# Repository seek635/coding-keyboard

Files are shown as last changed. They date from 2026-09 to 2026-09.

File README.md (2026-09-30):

# ClaudePad

> 蓝牙（BLE）编程专用实体小键盘 —— 为 Claude Code / 终端场景定制

一个 11 键 + 侧边审批拨杆的紧凑键盘，把 Claude Code 里最高频的操作从键盘组合键变成**单手一按**。

```
┌──────────┬────┬──────┬────────┬────────┐
│ 访问等级  │ ↑  │ 模型  │ 命令行  │  停止   │
├────┬────┬────┴────┴────────┤        │
│ ←  │ ↓  │ →    │   回车 2u   │        │
├────┴────┴──────┴────┬───────┴────────┤
│      空格 4u        │      语音       │
└─────────────────────┴────────────────┘
                                    ╱ 审批拨杆（OFF / ON）
```

**核心设计目标**：键盘本身不改变 Claude Code 的任何行为。拨杆 OFF 时它就是一个普通键盘；拨杆 ON 时才介入。

---

## 项目状态

| 模块 | 状态 | 说明 |
|---|---|---|
| 产品需求（PRD） | ✅ 完成 | `docs/PRD.md` |
| 结构设计（3D 打印） | ✅ 已渲染验证 | 6 个 STL 全部水密、尺寸零偏差 |
| 固件（ZMK） | ⚠️ 未编译 | 语法依据官方文档逐条核对，本地无 Zephyr 工具链 |
| 审批拨杆（宿主程序） | ✅ 协议层验证 | 31 个用例通过，未在真机 Claude Code 上跑通 |
| PCB | ⚠️ 未打样 | 封装坐标经两个独立开源库交叉验证 |
| 采购 | ✅ 清单完成 | `docs/采购清单.md` |

**未完成**：实机联调（画板 → 打样 → 焊接 → BLE 配对 → hooks 真机验证）。

---

## 硬件

| 部件 | 选型 | 备注 |
|---|---|---|
| 主控 | NoLogo ProMicro NRF52840 | 兼容 nice!nano，**装在 PCB 背面** |
| 轴体 | Kailh Choc **V2** 矮轴 35–40g | 编程敲击密度高，轻力度降疲劳 |
| 定位板 | 3D 打印，**厚 1.2mm** | Choc 标准值，不是 MX 的 1.5–1.6 |
| 审批拨杆 | SPDT 拨动开关 | 三脚，拨过去停住；轴套长度需 ≥ 9mm |
| 电池 | 3.7V 锂电 400–500mAh | 焊盘接线（非插座）；**厚 ≤ 4.0mm** |
| 反馈 | WS2812 | 可选 |

**整机尺寸**：107.10 × 71.10 × **23.30** mm（X 向 111.20 含右侧拨杆凸台）

### 垂直尺寸链

```
z = 23.30  ┌─────────────┐  键帽顶面
           │   键帽 5.0   │
z = 18.30  ├─────────────┤  键帽底面
           │  ★ 间隙 3.5  │  ← 必须 ≥ 键程 3.2，否则按不下去
z = 14.80  ├═════════════┤  定位板上表面
           │  定位板 1.2  │
z = 13.60  ├─────────────┤  定位板底面
           │  轴体卡扣 5.0 │  ← 只走轴体引脚，主控已改到板背面
z =  8.60  ├─────────────┤  PCB 上表面（轴体焊接面）
           │    PCB 1.6   │
z =  7.00  ├─────────────┤  PCB 下表面
           │ 主控/电池 5.0 │  ← 主控 3.2 + 余 1.8
z =  2.00  ├─────────────┤  底板上表面
           │    底板 2.0   │
z =  0.00  └─────────────┘  桌面
```

> ⚠️ **键帽间隙必须 ≥ 键程**。键帽裙边 17.6mm 比定位板轴孔 13.8mm 宽，塞不进孔里，
> 所以键帽只能悬在板上方，下压空间必须靠这个间隙提供。写成 0.3mm 会让键盘**完全按不下去**。

---

## 目录结构

```
cad/          参数化 3D 模型（OpenSCAD）+ 渲染产物
  lib/params.scad   ★ 所有尺寸的唯一来源
  plate.scad        定位板
  case_bottom.scad  底座（腔体/走线/散热/固定）
  keycap.scad       键帽（1u / 2u / 4u）
  test_coupon.scad  校准试件（打印前必打）
  output/*.stl      已渲染验证的 6 个 STL
  output/viewer.html 可交互三维查看器（three.js）

firmware/     ZMK shield 固件配置
  config/boards/shields/claudepad/*.keymap   ★ 键位与手势

host/         宿主程序（审批拨杆实现）
  claudepad_daemon.py   ★ 常驻：HTTP hook 应答 + 键盘监听
  claudepad_core.py     决策核心
  install_hook.py       一键安装到 Claude Code

pcb/          PCB 网表与接线图（json / md / svg / png）
tools/        校验与生成脚本（14 个）
docs/         设计文档
```

---

## 快速开始

### 看三维模型（零依赖）

```bash
python tools/view_model.py          # 起本地服务 + 开浏览器
```

或直接看 `cad/output/preview/*.png`。

### 校验设计（只需 Python）

```bash
python tools/check_env.py           # 先跑这个，看缺什么
python tools/check_dims.py          # 23 项结构设计规则
python tools/verify_geometry.py     # 孔位 / 对称 / 键帽对位
python tools/check_keymap.py        # 固件 ↔ 结构 交叉校验
```

**只有导出 STL 才需要 OpenSCAD**（`python tools/export_stl.py`）。
校验逻辑全部纯 Python 实现，这是刻意设计——OpenSCAD 是整条链里最难装的东西。

### 打印顺序

**别一次打全套。**

| 顺序 | 文件 | 验证什么 | 耗时 |
|---|---|---|---|
| ① | `00_test_coupon.stl` | **轴体卡扣间隙**（唯一需实测的参数） | 15 min |
| ② | `02_plate.stl` | 轴孔松紧 | 40 min |
| ③ | `05_keycap_4u.stl` | 三轴支撑手感 | 35 min |
| ④ | `01_case_bottom.stl` | 孔位与装配 | 3–4 h |

### 审批拨杆（宿主程序）

```bash
python host/install_hook.py         # 安装到 Claude Code（自动备份 + 幂等）
python host/claudepad_daemon.py     # 启动常驻进程
python host/switchctl.py on|off     # 手动切换状态（没有硬件也能测）
python host/test_hook.py            # 31 个用例
```

---

## 三个关键设计决策

### 1. 键盘是无状态的

键盘收不到权限档位、模型名、审批状态。所以「长按复位到 default」「长按循环切换模型」
**键盘做不了**——它不知道当前在哪一档。

方案：键盘只**发信号**（`Ctrl+Alt+Shift+F13`/`F14` 这种极难误触的组合），
由读取终端状态栏的上位机执行真正的操作。

### 2. 审批拨杆走 hooks，不走文本嗅探

| | 终端文本嗅探 | Hooks |
|---|---|---|
| 稳定性 | 匹配文案，**改文案就失效** | 官方接口，不依赖文案 |
| 能否分级 | 难结构化 | 直接拿到 `tool_name` + `tool_input` |
| 误判 | 天然会误判 | 结构化字段，无误判 |

官方机制里有一条是整个方案成立的关键：

> `PreToolUse` 返回 `{"hookSpecificOutput":{"permissionDecision":"allow"}}` → 跳过权限提示
> **返回空（exit 0 无输出）→ 不算批准** → 走原生权限流程

这使「拨杆 OFF = 产品不存在」成立——不改变用户任何既有行为。

**实测性能**：command 模式 510ms/次（每次起进程，不可接受）→ **HTTP 模式 15ms/次**（采用）。

**两条铁律**：
1. **失效安全** —— 任何故障（进程没跑 / 令牌错 / 脚本异常）都退化为「正常询问」，绝不误批
2. **只升不降** —— hook 只返回 `allow`，从不返回 `ask`/`deny`

### 3. 大键必须多轴支撑

4u 空格单轴支撑时 PLA 挠度 **1.59mm**（明显翘），三轴并联降到 **0.20mm**（降 87.5%）。
回车 2u 用 2 轴，空格 4u 用 3 轴。这不是可选项。

---

## 单一数据源

**所有尺寸只有一个来源：`cad/lib/params.scad`。** 任何地方要数字都必须解析它，不能手抄。

已落实：校验脚本、PCB 网表、行程图、**三维查看器**全部从它读取。

> **教训**：渲染出的 PNG 是快照（改参数就过期），手写 HTML 是副本（改参数就骗人）。
> 展示层也必须生成——否则它比没有更糟，因为它会**自信地展示错误信息**。

改完 `params.scad` 后：

```bash
python tools/check_dims.py && python tools/lint_scad.py && \
python tools/verify_geometry.py && python tools/export_stl.py && \
python tools/gen_viewer.py && python tools/draw_travel.py
```

---

## 已知限制

- **固件未编译**：本地无 Zephyr 工具链。语法依据 ZMK 官方文档（shield 结构 / hold-tap /
  tap-dance / macros）逐条核对，并做了静态一致性校验，但首次构建可能需微调。
- **审批拨杆未在真机验证**：本机无 Claude Code CLI，验证在协议层完成（按官方文档构造
  输入输出 + 验证失效路径）。接入步骤见 `docs/审批拨杆技术验证.md`。
- **PCB 未打样**：封装坐标经交叉验证，但未生成实际 PCB 文件跑 DRC。
- **`SWITCH_PLATE_GAP` 待实测**：Choc 官方未公开定位板高度，社区实测 3.5–6.0mm 浮动。
  用 `00_test_coupon.stl` 实测后回填 `params.scad`。

---

## 文档

| 文档 | 内容 |
|---|---|
| `docs/PRD.md` | 产品需求、键位定义、手势表、HID 映射 |
| `docs/结构设计规格书.md` | 尺寸链、公差、装配顺序、走线 |
| `docs/固件设计说明.md` | ZMK 设计原理与取舍 |
| `docs/PCB设计规格书.md` | 封装坐标、布局、打样参数 |
| `docs/审批拨杆技术验证.md` | hooks 路线可行性报告 |
| `docs/采购清单.md` | BOM 与选型理由 |

---

## 许可

未定。

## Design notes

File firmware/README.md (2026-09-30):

# ClaudePad 固件（ZMK）

三行五列 11 键 + 侧边审批拨杆的 ZMK shield 配置。

**主控**：NoLogo ProMicro NRF52840（原 SuperMini，兼容 nice!nano，Pro Micro 引脚兼容）
**固件框架**：[ZMK](https://zmk.dev)（BLE 键盘事实标准）

---

## 目录结构

本目录就是一个**标准 zmk-config**（ZMK 最主流的仓库布局，不用模块机制）：

```
firmware/                                     ← 这个目录的根 = 仓库根
├── .github/workflows/build.yml               ← GitHub Actions：推上去自动编译出 .uf2
├── build.yaml                                ← 构建矩阵：板子 nice_nano_v2 + shield claudepad
├── config/                                   ← ZMK_CONFIG 指向这里
│   ├── west.yml                              ← ZMK 上游依赖（版本锁定，须与 workflow 一致）
│   └── boards/shields/claudepad/             ← ★ shield 必须在 config/boards/shields/ 下
│       ├── Kconfig.shield                    ← shield 标识
│       ├── Kconfig.defconfig                 ← 设备名等默认配置
│       ├── claudepad.overlay                 ← 矩阵 + 引脚 + 变换
│       ├── claudepad.keymap                  ← ★ 键位与手势（核心）
│       ├── claudepad.conf                    ← 配置建议
│       └── claudepad.zmk.yml                 ← 硬件元数据
```

> **⚠️ 两个曾经踩过的坑（已由 `tools/check_keymap.py` 自动拦截）**
>
> 1. **shield 必须在 `config/boards/shields/` 里**。ZMK 只从 `<ZMK_CONFIG>/boards/shields/`
>    查找 shield（依据 `app/keymap-module/modules/modules.cmake` 与 `app/Kconfig`）。
>    放错层级 → 构建报 `shield not found`，而且报错信息很绕。
> 2. **不要在这里放 `zephyr/module.yml`**。官方 CI 工作流会靠它判断「这是不是一个 ZMK 模块」，
>    一旦存在就改走模块分支（把 config 复制到临时目录、另传 `-DZMK_EXTRA_MODULES`），
>    shield 查找路径随之改变。本项目用标准布局，故不设该文件。

---

## 键位与手势总表

| 键位 | 单击 | 双击 | 长按 |
|---|---|---|---|
| **访问等级** | `Shift+Tab` 循环权限档位 | — | 复位到 default（发信号给上位机） |
| **↑ ↓ ← →** | 对应方向键 | — | 自动重复（系统原生） |
| **模型** | `/model` + Enter | — | 循环切换模型（发信号给上位机） |
| **命令行** | `/` | — | `@` 文件引用 |
| **停止** | `Esc` 中断生成 | `Ctrl+C` 强制取消 | `Ctrl+C` ×2 退出会话 |
| **回车** | `Enter` 发送 | `Shift+Enter` 换行 | — |
| **空格** | `Space` | — | `Tab` 自动补全 |
| **语音** | 按住 = `Space`（push-to-talk） | `/voice` 切换启用 | — |
| **审批拨杆** | 拨到 ON = 持续按下 `F13`；OFF = 释放 | — | — |

> 「发信号给上位机」= 发送 `Ctrl+Alt+Shift+F13` / `F14` 这类极难误触的组合键。
> 因为键盘**无法知道**当前权限档位或模型名，这两个操作必须由读取状态栏的上位机执行。
> 详见 `docs/固件设计说明.md`。

---

## 矩阵接线

电气上是 **3 行 × 6 列**，实际用到 12 个交点：

```
        列1    列2    列3    列4    列5    列6
       (D7)   (D8)   (D9)   (D10)  (D16)  (D14)
行1(D4) 访问    ↑     模型   命令行  停止   审批拨杆
行2(D5)  ←      ↓      →     回车     —      —
行3(D6) 空格    —      —      —     语音     —
```

**大键并联接法**（重要）：
- **回车 2u**：定位板开 2 个轴孔，两个轴体都接到 `(行2, 列4)`
- **空格 4u**：定位板开 3 个轴孔，三个轴体都接到 `(行3, 列1)`

即大键的多个轴体**电气上并联**，任一轴触发即响应。PCB 设计时要把这些焊盘接到同一条线。

> ✅ **引脚分配已定稿并与 PCB 交叉校验通过**（2026-10-01）。板上走线就是这套分配，
> PCB 已于 2026-09-28 下单。`tools/check_keymap.py` 会拿 `claudepad.overlay` 与
> `pcb/netlist.json` 逐项比对，改任一边不一致就会报错。
> 若确需调整，改 `claudepad.overlay` 里的 `row-gpios` / `col-gpios` 即可，键位不用动。

---

## 怎么编译

### 方式一：GitHub Actions（推荐，零环境）✅ 已跑通

**已实测成功**：2026-10-01 首次构建通过，产出 138 KB 的 `.uf2`。

**为什么需要一个「根目录等于 firmware/」的分支或仓库**：官方 CI 用 repo 根目录
定位 `build.yaml` 和 `config/`。本项目是 monorepo，`firmware/` 在子目录里，
套一层就会全部错位。

**当前的做法：`zmk-firmware` 分支**（用 git subtree 把 `firmware/` 的内容摊到根）：

```bash
# 更新固件后，重新生成并推送这个分支，CI 就会重新构建
git subtree split --prefix=firmware -b zmk-firmware
git push origin zmk-firmware --force
```

> 因为 subtree 会重写这段历史，所以推送要带 `--force`。这个分支**只用来构建**，
> 不要在它上面开发 —— 所有改动都改 `main` 的 `firmware/`，然后重新 split。
> 推 `main` 不会触发构建（根目录没有 `.github/workflows/`），只有推 `zmk-firmware` 会。

**拿固件**：Actions → `Build ZMK firmware` → 最新一次运行 → **Artifacts** →
`firmware` → 解压得到 `claudepad-nice_nano_v2-zmk.uf2`。
也可在 Actions 页面点 **Run workflow** 手动触发。

**更干净的长远方案**：把 `firmware/` 的内容单独建一个仓库（如 `claudepad-zmk`），
仓库根就是现在这个目录，就不需要 subtree 那一步了。等固件稳定后可以迁过去。

工作流本身只有一行实质内容 —— 复用 ZMK 官方的可复用工作流：

```yaml
uses: zmkfirmware/zmk/.github/workflows/build-user-config.yml@v0.3.0
```

> ⚠️ 这个 `@v0.3.0` 必须与 `config/west.yml` 里的 zmk `revision` 一致，
> 否则构建脚本和 ZMK 版本对不上。`tools/check_keymap.py` 会检查这一条。

### 方式二：本地构建

需要 Zephyr SDK + west（Windows 上配置繁琐，**一般直接用方式一**）。

```bash
cd firmware                      # 本目录

# 1. 初始化 workspace（本目录即 workspace 根）
west init -l config
west update

# 2. 构建
west build -p -b nice_nano_v2 -s zmk/app -- \
    -DSHIELD=claudepad \
    -DZMK_CONFIG="$(pwd)/config"

# 3. 产物
#   build/zephyr/zmk.uf2
```

本地构建**不需要** `ZMK_EXTRA_MODULES` —— shield 就在 `config/boards/shields/` 下，
ZMK 会自动把 `ZMK_CONFIG` 加进 board root。

---

## 怎么刷固件

1. 主控插 USB（**必须是数据线**）
2. **进 bootloader** → 出现名为 `NICENANO` 的 U 盘
   - ⚠️ NoLogo ProMicro **没有复位按钮**，要**在 0.5 秒内短接 2 次 RST 到 GND**
   - 外壳底板预留了 φ8mm 孔，装一个外接轻触开关接在 RST–GND 之间（见 `docs/新手采购清单.md` 第 14 项）
3. 把 `claudepad.uf2` 拖进去
4. 板子自动重启，蓝牙广播名为 `ClaudePad`

之后改键位只需重新编译刷入，无需重新配对。

---

## 怎么改键位

**只改 `claudepad.keymap` 一个文件。**

改完**务必**跑一致性校验：

```bash
python tools/check_keymap.py
```

它会验证：
- 键位数量与 CAD 布局（`cad/lib/params.scad`）是否一致
- 每个键的顺序和功能是否与 PRD 相符
- 自定义行为的参数个数是否匹配

**改键位时注意**：`bindings` 的顺序必须与 `claudepad.overlay` 里 `default_transform` 的 `map` 顺序严格一致（都是从左到右、从上到下）。

---

## 常用调参

手感类参数都在 `claudepad.keymap` 的行为定义里：

| 想调什么 | 改哪个属性 | 当前值 |
|---|---|---|
| 空格误触 Tab | `spc_tab` 的 `tapping-term-ms` | 300（调大更不易误触） |
| 停止键误退会话 | `stop` 的 `tapping-term-ms` | 1200（调大更安全） |
| 双击判定窗口 | 各 tap-dance 的 `tapping-term-ms` | 200~250 |
| 快速连按不判长按 | `quick-tap-ms` | 150~200 |
| 打字时禁用长按 | `require-prior-idle-ms` | 120 |

---

## 已知限制

| 限制 | 说明 |
|---|---|
| **已编译通过，但未上机** | ✅ 2026-10-01 GitHub Actions 首次构建成功（ZMK v0.3.0，产出 138 KB `.uf2`）。⚠️ 但**从未烧进真机**——BLE 配对、按键手感、长按/双击的判定窗口都要等板子到货后才能验证。 |
| **状态指示未实现** | PRD 第 8 章要求「按键 RGB 显示当前权限档位」，这需要自定义固件 + 上位机通过 GATT 回写状态。当前固件只做键位。 |
| **审批拨杆只上报状态** | 拨杆作为矩阵里的一个键（F13），上位机需自行监听。真正的自动审批逻辑在上位机侧。 |
| **引脚分配已定稿** | ✅ 2026-10-01 交叉校验通过：`claudepad.overlay` 的 行 D4/D5/D6、列 D7/D8/D9/D10/D16/D14 与**已下单的** PCB 网表（`pcb/netlist.json`）逐项一致，二极管方向同为 `col2row`。此校验已固化进 `tools/check_keymap.py`。 |

详见 `docs/固件设计说明.md` 的「后续工作」。

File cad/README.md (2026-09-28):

# ClaudePad CAD 模型

3D 打印用的参数化结构模型。**改尺寸只需改一个文件**：`lib/params.scad`

整机 **107.10 × 71.10 × 23.30 mm**

---

## 依赖：大部分脚本不需要 OpenSCAD

这是刻意设计的。OpenSCAD 是整套工具链里最难装的东西（200MB、官方站和 GitHub 都常被拦），
所以**校验逻辑全部用纯 Python 实现**，不依赖它。

| 脚本 | 依赖 | 作用 |
|---|---|---|
| `view_model.py` | 纯 Python | **在浏览器里看三维模型** |
| `lint_scad.py` | 纯 Python | SCAD 语法与符号检查 |
| `check_dims.py` | 纯 Python | 26 项结构设计规则 |
| `verify_geometry.py` | 纯 Python | 孔位/对位验证 |
| `check_keymap.py` | 纯 Python | 固件 ↔ 结构一致性 |
| `verify_stl.py` | 纯 Python | STL 校验（读文件，不需要 CAD 软件） |
| `gen_pcb.py` | 纯 Python | PCB 网表与接线图 |
| `gen_viewer.py` | 纯 Python | **把尺寸注入三维查看器**（防漂移） |
| `draw_travel.py` | 纯 Python | 按键行程剖面图 |
| **`export_stl.py`** | **★ OpenSCAD** | **把 .scad 渲染成可打印的 STL** |

**实际含义**：

- **只装 Python** → 你能**看模型**、改所有尺寸、验证设计是否自洽、检查固件对不对。
  **完全够用来迭代设计。**
- **装了 OpenSCAD** → 才能把模型变成可以送切片软件的 STL。

不确定自己缺什么？跑这个：

```bash
python tools/check_env.py
```

它会逐项告诉你什么已就绪、什么缺失、缺的那个影响哪些功能。

> **本机现状**：OpenSCAD 已装在 `~/openscad-portable/`，6 个 STL 也已生成。
> 所以你现在直接跑任何脚本都可以。

---

## 怎么看到三维模型

**一条命令**：

```bash
python tools/view_model.py
```

会自动起本地服务并打开浏览器，里面是可旋转、可缩放、可爆炸拆解的实时三维模型。

**不需要 OpenSCAD，不需要任何 CAD 软件**——查看器读的是已经渲染好的 STL，
用浏览器的 WebGL 显示。

其它看模型的方式（都不需要软件）：

| 方式 | 位置 |
|---|---|
| 交互式三维查看器 | `python tools/view_model.py` |
| 渲染好的图片 | `cad/output/preview/*.png` |
| 丢进任意 STL 查看器 | `cad/output/*.stl` |
| 丢进切片软件（Cura / PrusaSlicer） | `cad/output/*.stl` |

**什么时候才需要 OpenSCAD**：改了 `params.scad` 里的尺寸，想看到新模型时。
因为 `.scad` 是模型源码，需要 OpenSCAD 求值才能变成几何体。

---

## 目录结构

```
cad/
├── lib/
│   └── params.scad          ← 所有尺寸都在这里，改这个
├── test_coupon.scad         ← ★ 校准试件（先打这个！）
├── plate.scad               ← 定位板（轴板）
├── case_bottom.scad         ← 底座
├── keycap.scad              ← 键帽（1u / 2u / 4u）
├── assembly.scad            ← 总装预览 + 爆炸图
└── output/                  ← 导出的 STL 放这里

tools/
├── check_env.py             ← 环境自检（先跑这个）
├── view_model.py            ← ★ 在浏览器里看三维模型（不需要 CAD）
├── check_dims.py            ← 设计规则校验（26 项）
├── lint_scad.py             ← 语法与符号检查
├── verify_geometry.py       ← 孔位与对位验证
├── verify_stl.py            ← STL 校验（尺寸/水密性/体积）
├── scad_params.py           ← 参数解析器（上面脚本共用）
├── canvas.py                ← 2D 画布（SVG + PNG 双后端，画图脚本共用）
├── gen_pcb.py               ← 生成 PCB 网表与接线图
├── gen_viewer.py            ← 把尺寸注入三维查看器（防漂移）
├── draw_travel.py           ← 生成按键行程剖面图
├── install_openscad.py      ← 自动下载安装 OpenSCAD（多镜像+断点续传）
└── export_stl.py            ← 一键导出全部 STL（★ 唯一需要 OpenSCAD 的）

docs/
└── 结构设计规格书.md          ← 尺寸 / 公差 / 装配 / 走线的完整说明
```

---

## 四步走

### 第 1 步：核参数（不需要装任何东西）

```bash
python tools/check_dims.py       # 26 项设计规则
python tools/lint_scad.py        # 语法、符号、死代码
python tools/verify_geometry.py  # 孔位、对称性、键帽对位
```

这三个脚本**不依赖 OpenSCAD**，纯 Python，随时可跑。

它们**直接从 `params.scad` 读参数**，所以不存在"改了参数但校验还用旧值"的问题。

**最有价值的是 `check_dims.py`** —— 它会抓出这些真实会翻车的问题：

- 内腔高度和零件堆叠对不上（会导致轴体够不到 PCB）
- 螺丝柱撞穿轴孔
- 拨杆螺母没有咬合长度
- 轴芯太长捅穿键帽顶面
- 主控放正面会压到轴体（板面被 14 个轴体占满）
- 电池厚度超过可用空间
- 空格单轴支撑挠度超标

### 第 2 步：装 OpenSCAD

**方式一：自动安装（推荐）**

```bash
python tools/install_openscad.py
```

脚本会自动尝试多个 GitHub 加速镜像、支持断点续传，最后解压到 `~/openscad-portable/`。

**方式二：手动下载**

下载：https://openscad.org/downloads.html

装完确认能调到：

```bash
openscad --version
```

> **为什么需要专门的安装脚本**：`openscad.org` 官方站和 GitHub Release 的
> `objects.githubusercontent.com` 在部分网络环境会被拦，直连速度可能只有 20KB/s。
> 本脚本按顺序试 `ghproxy.net` / `gh-proxy.com` / `gitmirror` 等镜像，断流自动续传。
>
> Windows 上优先用 `openscad.com`（控制台版），它不会弹 GUI 窗口。

### 第 3 步：导出 STL

```bash
python tools/export_stl.py
```

| 文件 | 零件 | 材料 |
|---|---|---|
| `00_test_coupon.stl` | **校准试件** | PLA |
| `01_case_bottom.stl` | 底座 | PETG |
| `02_plate.stl` | 定位板 | PLA |
| `03_keycap_1u.stl` | 键帽（打 9 个） | PLA |
| `04_keycap_2u.stl` | 回车键帽 | PLA |
| `05_keycap_4u.stl` | 空格键帽 | PLA |

**导出后务必校验**：

```bash
python tools/verify_stl.py
```

它会检查每个 STL 的包围盒尺寸是否与设计一致、是否水密（无破面）、体积是否正常。
这一步能抓出 CSG 建模中的共面/非流形问题。

### 第 4 步：打印

**别一次打全套。** 按这个顺序：

| 顺序 | 打什么 | 验证 | 耗时 |
|---|---|---|---|
| ① | `00_test_coupon.stl` | **轴体卡扣间隙** | 15 min |
| ② | `02_plate.stl` | 轴孔松紧 | 40 min |
| ③ | `05_keycap_4u.stl` | 三轴支撑手感 | 35 min |
| ④ | `01_case_bottom.stl` | 孔位与装配 | 3–4 h |

---

## 预览图

渲染预览（OpenSCAD 已装好后可自己重跑）：

```bash
cd cad
OSC=~/openscad-portable/openscad-2021.01/openscad.com
"$OSC" -D 'VIEW="assembly"' --autocenter --viewall --imgsize=1000,700 \
       -o output/preview/assembly.png assembly.scad
```

`cad/output/preview/` 下已有：

| 文件 | 内容 |
|---|---|
| `assembly.png` | 整机总装（等轴测） |
| `explode.png` | **三层爆炸图**（底座 / 定位板 / 键帽） |
| `top_view.png` | 正俯视 —— 用于核对键位排布 |
| `case_iso.png` | 底座内部结构 |
| `side_90.png` | 右壁正视图（拨杆孔 + USB 开口） |
| `plate.png` | 定位板 |
| `keycap4u_bottom.png` | 4u 空格底面 —— 可见 3 个榫头柱与 3 条加强筋 |

---

## 校准试件怎么用（重要）

`SWITCH_PLATE_GAP`（PCB 到定位板的距离）是**整套模型里唯一无法从公开资料确定**的尺寸。Choc 官方没公开，社区实测在 3.5–6.0mm 之间浮动。

所以先打 `00_test_coupon.stl`，上面有 3 个测试位（间隙 3.50 / 4.25 / 5.00mm）：

1. 拿真实 Choc 轴体逐个插进去
2. 找那个「**卡扣清脆扣入 + 轴体底面刚好贴住基座**」的位置
3. 把 `params.scad` 里的 `SWITCH_PLATE_GAP` 改成该值
4. 重跑 `check_dims.py`、`gen_viewer.py` 和 `export_stl.py`

判读标准：

| 现象 | 结论 |
|---|---|
| 轴体底面与基座之间有缝 | 该位间隙**偏大** |
| 卡扣扣不上 / 扣上后底面顶住基座 | 该位间隙**偏小** |
| 完全贴合 + 卡扣清脆 | ✅ 就是它 |

三个都不合适 → 改 `test_coupon.scad` 里的 `GAPS` 数组，重打（15 分钟）。

---

## 在 OpenSCAD 里预览

```bash
openscad assembly.scad
```

`F5` 快速预览，`F6` 完全渲染。改文件里的 `VIEW` 变量：

| VIEW | 效果 |
|---|---|
| `"explode"` | 爆炸图（默认）—— 检查装配关系与干涉 |
| `"assembly"` | 合体图 |
| `"case"` | 只看底座 |
| `"plate"` | 只看定位板 |
| `"caps"` | 只看键帽 |

单独看键帽：

```bash
openscad keycap.scad
```

改文件里的 `keycap_mode` 为 `"1u"` / `"2u"` / `"4u"`。

---

## 最常改的参数

都在 `lib/params.scad`：

| 想做什么 | 改哪个 | 当前值 |
|---|---|---|
| **轴体卡扣位置**（最重要） | `SWITCH_PLATE_GAP` | `5.00` |
| 轴体装不进 / 太松 | `SWITCH_CUTOUT_TOL` | `0.10` |
| 键帽榫槽太紧 / 太松 | `CAP_CROSS_W` | `1.30` |
| 键距 | `PITCH` | `18.0` |
| 键盘更薄 | `PCB_STANDOFF_H` | `5.00` |
| 换拨杆开关 | `SW_*` 系列 | 见文件 |
| 换电池 | `BATT_*` + `PCB_STANDOFF_H` | 见文件 |

**改完必跑**：

```bash
python tools/check_dims.py && python tools/lint_scad.py && python tools/verify_geometry.py
```

---

## 设计要点

### 垂直尺寸是推导出来的，不是写死的

```
内腔净高 = PCB_STANDOFF_H + PCB_T + SWITCH_PLATE_GAP
         = 5.0 + 1.6 + 5.0
         = 11.6 mm
```

改任何一个零件，整机高度自动跟着变。这样就不会出现"定位板抬高 4mm 导致轴体够不到 PCB"这类致命错误。

### 一个必须知道的耦合

**PCB 下方那 5.0mm 要同时容下电池和主控** —— 两者平面错开到两侧（电池贴左壁、主控贴右壁），
但层高由**较厚的电池**决定：胶 0.6 + 电池 4.0 = 4.6mm。想改薄键盘先确认电池装得下。
`check_dims.py` 会校验这一点。

> 主控早先装在 PCB **正面**，那时这条耦合是「轴体卡扣间隙 = 主控净空」；
> 因为 14 个轴体占满板面，主控已改到背面，耦合随之转移。详见 `docs/PCB设计规格书.md` §14。

### 空格为什么要 3 个轴

按无加强筋的最坏情况估算：

| 支撑方式 | 中点挠度（3N 按压力） |
|---|---|
| 单轴 | 1.59 mm ← 明显翘 |
| 三轴并联 | 0.20 mm ← 可接受 |

降幅约 87%。所以定位板在空格位开 3 个轴孔，键帽内对应 3 个榫槽。

### 螺丝柱为什么只能在边距里

轴孔之间净距只有 `18 − 13.9 = 4.1mm`，放不下螺丝柱。所以螺丝柱放在网格外缘到定位板边缘的 6mm 边距里，`check_dims.py` 会校验它与轴孔有 ≥0.8mm 余量。

---

## 关于 STL 文件

本仓库**包含**已导出的 6 个 STL（`cad/output/*.stl`），这样**只装 Python 也能用**：
查看器、切片软件都能直接吃，不需要为了看一眼模型去装 OpenSCAD。

⚠️ **但要注意它们会过期**：`params.scad` 一改，仓库里的 STL 就是旧的快照。
所以：

- **只是想打印** → 直接用仓库里的，但先确认没改过参数（`git log` 看 `params.scad` 的改动时间）
- **改过参数** → 必须重新导出，别拿旧 STL 去打印

```bash
python tools/export_stl.py     # 需要 OpenSCAD
python tools/verify_stl.py     # 校验包围盒与水密性
```

> 之所以强调这点：展示层（预览图、查看器、STL）都必须是**生成物**而不是手抄的副本 ——
> 副本会「自信地展示错误信息」，比没有更糟。见根目录 `README.md` 的「单一数据源」。

---

## 完整设计依据

尺寸从哪来、公差为什么是这个数、装配顺序、走线怎么走 —— 全在 **`docs/结构设计规格书.md`**。

那里也有「常见问题与对策」，遇到装不进、太松、翘曲先查那里。

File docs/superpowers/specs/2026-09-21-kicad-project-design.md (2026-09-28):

# ClaudePad KiCad 工程生成器 — 设计

**日期**：2026-09-21
**状态**：待实现
**相关文档**：`docs/PCB设计规格书.md` · `docs/结构设计规格书.md` · `docs/采购清单.md`

---

## 1. 背景与目标

### 1.1 背景

PCB 打样卡在「没有板文件」：`pcb/` 目录只有 `netlist.json` / `netlist.md` / `placement.csv` / `wiring.svg`，
没有任何 `.kicad_pcb` / `.kicad_sch` / `.kicad_pro`，也没有 Gerber。

`docs/PCB设计规格书.md` §12 自己声明了这条边界：「本文件给的是**设计规格与坐标**，画板需要你在 KiCad 里落地」。

### 1.2 目标

产出一个**能在 KiCad 中打开、DRC 通过、封装放置正确**的板文件，坐标全部来自 `cad/lib/params.scad`
的派生数据，供用户手工布线后打样。

### 1.3 关键约束

- 封装几何**不能由本项目手抄**。手抄的封装即使错了，DRC 也查不出来，但板子会做废 ——
  必须从 KiCad 官方库加载真封装。
- 坐标**不能有第二份来源**。`params.scad` 是唯一数据源，`gen_pcb.py` 已经从它算出全部坐标，
  新生成器只能读它的产物，不能重算。

---

## 2. 非目标

明确不做：

- ❌ **不布线**。生成的是「封装已放好、网络已连（有飞线）」的板，走线由用户在 KiCad 里手工完成
- ❌ **不出 Gerber**。布线完成后才能出
- ❌ **不生成原理图**。只在 `.kicad_pcb` 内部直接给焊盘指定网络
- ❌ **不含 WS2812**。v1 不放灯珠，只保留 D15 焊盘备将来使用
- ❌ **不做实机验证**。物理验证（校准试件、洞洞板原型）不在本次范围

> **为什么不做原理图**：用户只布线，不靠原理图。省掉一套 S-expression 就少一份出错面。
> 代价是以后想改拓扑得直接在 PCB 里改。

---

## 3. 交付物

| 文件 | 状态 | 说明 |
|---|---|---|
| `pcb/kicad/claudepad.kicad_pcb` | 新增 | 板文件，用户在 KiCad 里打开它布线 |
| `pcb/kicad/claudepad.kicad_pro` | 新增 | 工程设置：2 层、板厚 1.6、DRC 规则 |
| `tools/gen_kicad.py` | 新增 | 生成器 |
| `tools/gen_pcb.py` | 修改 | 修二极管坐标（见 §7） |
| `pcb/placement.csv` | 重跑 | 二极管坐标更新 |
| `pcb/netlist.json` | 重跑 | 增加二极管坐标字段 |
| `pcb/netlist.md` | 重跑 | 二极管数量/位置说明更新 |
| `tools/check_env.py` | 修改 | 增加 KiCad 与 `pcbnew` 的检测 |

**不改动**：`firmware/` · `cad/` · `host/`。

---

## 4. 板上元件

坐标系：**PCB 左下角为原点**，单位 mm，Y 向上。板面 98.00 × 50.00。

### 4.1 正面：14 个轴体

**Kailh Choc V2（PG1353）**，原点 = 轴芯中心。**来源：凯华官方规格图。**

> ⚠️ **2026-09-21 修订**：此前本节依据两个开源封装库（daprice / siderakb）「交叉验证」，
> 但实物实测与该表不符 —— **两个库一起错了**（详见任务 #7）。

| 特征 | 孔径 | 数量 | 类型 |
|---|---|---|---|
| 金属电气脚 | **1.20** | **2** | 金属化（PTH）★ 官方图标注 `2-Ø1.20`，通电 |
| 不通电定位脚 | **1.50** | **1** | 非金属化（NPTH），轴体第 3 脚，不导通（官方图 `2*1.5`） |
| 轴芯中心孔 | **5.00** | 1 | 非金属化（NPTH，让位给中央 Ø4.80 塑料凸台） |
| LED 焊盘 | — | 1 | 官方图标注 `LED` |

**★ 三根引脚坐标（2026-09-26 按官方 datasheet 最终落定）**：电气脚 (−3.80, 4.93) 与
(−5.90, 0.00)，不通电定位脚 (5.15, −5.00)（Ø1.50）。依据：凯华官方 datasheet
CPG135301D01（2020-10-23 版）PCB Layout 矢量图像素标定。
⚠️ siderakb 社区封装三孔坐标是官方坐标的 x/y 互换错版，勿引用。

外形 15 × 15 × 5.3mm；底座外形 13.95 × 13.95mm。

14 个绝对坐标来自 `pcb/netlist.json` 的 `keys[].pcb_positions`：

| 行 | 轴体 x | y |
|---|---|---|
| 1 | 13, 31, 49, 67, 85 | 7 |
| 2 | 13, 31, 49, 67, 85 | 25 |
| 3 | 13, **40**, 67（空格）+ 85（语音） | 43 |

> 空格的中间轴在 x = 40，**不在 18mm 网格上** —— 放置时关掉网格吸附，照坐标放。

### 4.2 正面：12 只 1N4148（直插 DO-35）

用户已购**直插**二极管，不用贴片。

| 项 | 值 |
|---|---|
| 封装 | DO-35 玻璃封装，轴向引线 |
| 引脚跨距 | 7.62 mm（预计 KiCad 库名为 `Diode_THT:D_DO-35_SOD27_P7.62mm_Horizontal`，**Step 0 需确认**） |
| 数量 | **12** |
| 安装面 | **正面**（与轴体同侧） |

**为什么必须放正面**：PCB 下方那 5.0mm 已被电池（左，PCB x 0~28）和主控（右，PCB x 79.7~97.5）占用，
剩余 x 28~79.7 还要扣掉 x=40 / 76 两根 ⌀4 支撑台，按行间隙带估算只放得下约 9 只，**不够 12 只**。

**正面的空间**：轴体之间走廊宽 `18 − 13.5 = 4.5mm`，而 DO-35 本体直径仅约 1.9mm。
二极管**沿走廊方向躺放**（7.62mm 引脚跨距顺着走廊走，不横穿），可以放下。
纵向可用高度为 PCB 上表面到定位板下表面的 5.0mm，本体 1.9mm 占得下。

**12 个位置怎么分布**：11 个矩阵位置（9 个单键 + 回车 1 + 空格 1）各 1 只，
加上拨杆 1 只。具体坐标由生成器按 §7 的算法算出。

**方向**：`col2row` —— **阳极接列线、阴极接行线**，电流方向 列 → 行。
12 只必须**统一方向**，接反不会烧但矩阵读不出来。

### 4.3 背面：主控

**NoLogo ProMicro NRF52840**（原名 SuperMini，nice!nano / Pro Micro 引脚兼容）。

| 项 | 值 |
|---|---|
| 尺寸 | 17.78 × 33.00 mm，厚 3.20 mm |
| 安装面 | **PCB 背面（下表面）** |
| 朝向 | 镜像；元件面朝下；USB-C 朝**右壁** |
| 原点位置 | PCB 坐标 **(79.70, 8.50)**（左下角），右缘 97.48，距板缘 0.52 |
| 引脚 | 2.54mm 通孔，引脚朝上穿过 PCB 焊在正面 |

**为什么在背面**：板面被 14 个轴体占满，穷举后正面「零重叠位置数 = 0」。

**引脚分配**（必须与 `firmware/.../claudepad.overlay` 一致）：

| 信号 | 引脚 | 方向 |
|---|---|---|
| ROW1 / ROW2 / ROW3 | D4 / D5 / D6 | 输入（`ACTIVE_HIGH \| PULL_DOWN`） |
| COL1 … COL6 | D7 / D8 / D9 / D10 / D16 / D14 | 输出（`ACTIVE_HIGH`） |
| RGB 数据（留焊盘） | D15 | 输出 |

### 4.4 背面：其余焊盘

`docs/PCB设计规格书.md` §5 只给了这些焊盘的**语义位置**，没给坐标 —— 生成器需自行选位（见 §6.3）。

| 焊盘组 | 数量 | 语义 | 规格书的说法 |
|---|---|---|---|
| 电池 | 2（B+ / B−） | 电池引线焊到主控的 B+ / B− 焊盘 | 「左侧空区」 |
| 电源开关 | 2 | 串在电池正极与主控之间 | 「左侧」 |
| 复位按钮 | 2 | 并联到 RST（该主控无板载复位按钮） | 「主控旁」 |
| 拨杆引线 | 2 | 公共端 → ROW1，常开端 → COL6 | 「右侧缺口附近」 |
| D15（RGB 预留） | 1 | 备将来接 WS2812 | — |

### 4.5 网络清单

| 网络 | 连接 |
|---|---|
| `ROW1` | 主控 D4、PERM、UP、MODEL、CMD、STOP 的二极管阴极、拨杆二极管阴极 |
| `ROW2` | 主控 D5、LEFT、DOWN、RIGHT、回车二极管阴极 |
| `ROW3` | 主控 D6、空格二极管阴极、语音二极管阴极 |
| `COL1` | 主控 D7、PERM 二极管阳极、LEFT、空格（3 轴并联） |
| `COL2` | 主控 D8、UP、DOWN |
| `COL3` | 主控 D9、MODEL、RIGHT |
| `COL4` | 主控 D10、CMD、回车（2 轴并联） |
| `COL5` | 主控 D16、STOP、语音 |
| `COL6` | 主控 D14、拨杆二极管的**阳极** |
| `APPROVE_MID` | 拨杆二极管的**阴极** ↔ 拨杆开关**常开端 NO** |
| `VBAT` | 电池 B+ → 电源开关 → 主控 B+ |
| `GND` | 电池 B−、主控 B−、复位按钮一端、拨杆公共端 |
| `RST` | 主控 RST、复位按钮另一端 |
| `RGB_DIN` | 主控 D15、D15 预留焊盘 |

**拨杆的串联路径**（与矩阵按键同构，方向一致）：

```
COL6 ──▶ 二极管阳极 ──▶ 二极管阴极 ──▶ 拨杆 NO ──[拨杆]── COM ──▶ ROW1
              （APPROVE_MID 是二极管与开关之间的中间网络）
```

**大键并联**：回车 2 个轴体电气并联到同一交点（ROW2 × COL4）；
空格 3 个轴体并联到（ROW3 × COL1）。PCB 上把它们的焊盘用铜箔连到同一条线。

---

## 5. 板框与缺口

### 5.1 板框

矩形 **98.00 × 50.00**，四角**不做安装孔** —— PCB 由 14 个轴体「挂」着（轴体卡在定位板上，
定位板用 4 颗 M2 螺丝锁在底座上）。

### 5.2 右侧缺口

| 项 | 值 | 状态 |
|---|---|---|
| 深度 | 8.00 mm | ✅ 已定 |
| 长度 | 24.00 mm | ✅ 已定 |
| **纵向位置** | **未知** | ❌ **必须在生成前解决** |

**缺口的用途**：SPDT 拨杆的**本体在壳内**（拨杆 + 轴套 + 螺母在壳外），本体沿轴套方向侵入约 8.5mm。
不给它让位，本体就会压到 PCB 上。

**为什么位置是未知项**：`cad/case_bottom.scad` 第 28 行有 `SW_Y = 16.0`（拨杆中心纵向位置），
但它处于**外壳坐标系**，而缺口要落在 **PCB 坐标系**里。两套坐标的换算关系没有在文档里对齐过，
按 `case_bottom.scad` 第 34–35 行的换算约定（`case = CASE_WALL + PCB偏移 + pcb`）推出来的缺口区间
会超出板边（y 为负），说明 `SW_Y` 可能没跟着历次改动更新。

**更严重的是**：`tools/check_dims.py` 只校验了缺口的**深度**（`PCB_NOTCH_D >= 4.0`），
**从未校验过缺口的纵向位置**。也就是说缺口开错位置，26 项校验照样全绿 —— 这是同一类
「校验过了但不代表对」的陷阱。

**解决要求**：生成前必须确定缺口的纵向区间，并把它固化成可校验的值（进 `params.scad` 或 `check_dims.py`）。
缺口位置错 → 拨杆本体压板 → 板子报废。

---

## 6. 生成器设计

### 6.1 技术路线

用 **KiCad 自带的 Python + `pcbnew` API** 生成。

```
KiCad/bin/python.exe tools/gen_kicad.py
```

选这条路线的**唯一理由是封装正确性**：`pcbnew.FootprintLoad()` 从 KiCad 官方库加载真封装，
封装几何不由本项目手抄。备选方案（纯 Python 手写 `.kicad_pcb` 文本）虽然不依赖 KiCad 的 Python，
但必须内嵌手抄的封装定义 —— 抄错 1mm，DRC 全绿而板子做废，正是本项目 README 警告的
「自信地展示错误信息」。

### 6.2 输入

只读 **`pcb/netlist.json`** —— 由 `tools/gen_pcb.py` 从 `cad/lib/params.scad` 生成。

现有字段已经足够：

| 字段 | 内容 |
|---|---|
| `keys[]` | 12 个键：`label` / `row` / `col` / `net_row` / `net_col` / `pin_row` / `pin_col` / `switches` / `pcb_positions` |
| `rows[]` / `cols[]` | 网络名到引脚的映射 |
| `pinout` | 行/列/拨杆/RGB 引脚 |
| `diode_direction` | `col2row` |
| `switch_footprint` | Choc V2 焊盘坐标与孔径 |
| `pcb` | 宽 / 高 / 厚 / 原点偏移 / 缺口深度与长度 |

**生成器不得重新计算轴体坐标**。坐标算错一次就有两份不一致的来源。

### 6.3 需要生成器自行选位的部分

`netlist.json` 里**没有**这些焊盘的坐标，生成器必须按语义选定并写死为常量（附注释说明依据）：

- 电池 B+ / B− 焊盘
- 电源开关 2 个焊盘
- 复位按钮 2 个焊盘
- 拨杆引线 2 个焊盘

选位时必须满足：

1. 不与任何轴体本体（13.5mm 见方）重叠
2. 不与 4 个 ⌀4 支撑台（PCB 坐标 (40,16) (76,16) (40,34) (76,34)）重叠
3. 落在板框内
4. 不侵入右侧 8×24 缺口

---

## 7. 二极管坐标重算（修现有 bug）

### 7.1 问题

`pcb/placement.csv` 当前给出的二极管「建议位」**落在板外**：

```
D1,diode,ROW1xCOL1,13.00,-1.00,PERM；阳极→COL1，阴极→ROW1
```

它是按「轴体正上方 8mm」算的，而轴体在 y = 7，减 8 得 **y = −1**，板是 y 0~50。

### 7.2 修法

把二极管坐标的计算**移进 `tools/gen_pcb.py`**（它已经在算轴体坐标），算法：

1. 对每个需要二极管的矩阵位置，找一个**离对应轴体最近、且合法**的走廊位置
2. 合法性 = 不与轴体本体、支撑台、缺口、板缘重叠
3. 二极管方向统一为 `col2row`

产出写进 `netlist.json` 的新字段（如 `keys[].diode_pcb_pos`），供：

- `gen_pcb.py` 写 `placement.csv` 与 `netlist.md`
- `gen_kicad.py` 放 KiCad 封装

**这样三处共用同一份坐标**，不会各算各的。

---

## 8. 验证方案

| # | 手段 | 查什么 |
|---|---|---|
| 1 | `kicad-cli pcb drc` | 必须 **0 错误** |
| 2 | `kicad-cli pcb export gerbers` | 能导出 = 文件可被 KiCad 解析 |
| 3 | `gen_kicad.py` 自带纯 Python 自检 | ① 轴体/二极管坐标与 `netlist.json` 逐条一致 ② 二极管与轴体本体、支撑台不重叠 ③ 焊缝网络与 `netlist.md` 逐条一致 ④ 板框 98×50 |
| 4 | 人工 | 在 KiCad 里打开，核对板框、缺口位置、轴体是否落在定位板孔位上 |

**自检必须是纯 Python**（不依赖 KiCad），延续本项目「校验逻辑全部纯 Python 实现」的设计 ——
OpenSCAD 与 KiCad 都只用于产出，不用于校验。

---

## 9. 执行顺序

### Step 0：侦察 ✅ **已完成（2026-09-26，KiCad 10.0.6 @ D:\kicad）**

1. ✅ `pcbnew` 在 KiCad 自带 Python（`D:\kicad\bin\python.exe`）可 import，版本 10.0.6
2. ✅ **官方库没有 Choc 封装**（Button_Switch_Keyboard.pretty 只有 MX 系列）
   → 决定：自建封装，孔位直接采用 §4.1 已确认坐标（电气 (−3.8,4.93)/(−5.9,0) Ø1.20 PTH，
   定位 (5.15,−5) Ø1.50 NPTH，中心 Ø5.00 NPTH）——按凯华官方 datasheet 像素标定
3. ✅ 主控封装：`Connector_PinHeader_2.54mm:PinHeader_1x12_P2.54mm_Vertical`（直焊两排 1×12）
4. ✅ 二极管封装：`Diode_THT:D_DO-35_SOD27_P7.62mm_Horizontal`（与预期库名完全一致）

### Step 1..n

1. ✅ 缺口纵向位置已固化（params.scad `PCB_NOTCH_Y0/Y1` = [0,12] + check_dims.py 校验）
2. ✅ 二极管坐标已进 `gen_pcb.py`（DIODE_POS，DRC 校正后 v2），`netlist.json` 新字段 `diode_pcb_pos`
3. ✅ `placement.csv` 已同步（含轴体旋转角）
4. ✅ `gen_kicad.py` 已写完（2026-09-26）
5. ✅ 板文件已生成 `pcb/claudepad.kicad_pcb`：生成器自检通过 + DRC 0 违规（58 unconnected 为布线前预期）+ Gerber 全层导出成功
6. ✅ 用户 KiCad 核对通过（2026-09-27）；**布线完成**：FreeRouting v2.4.1 自动布线
   （DSN 导出 → CLI `-de/-do` → 58 项全布通）→ `tools/import_ses.py` 导回
   （KiCad 10 的 ImportSpecctraSES 对 FR v2.4.1 输出返回 False，自写导入器：
   坐标变换 x_k=x_ses×0.1μm / y_k=−y_ses，179 段走线 + 2 过孔）
   → **DRC 最终结果：0 违规、0 未连接** ✓ 待打样

**生成过程沉淀的关键决策**（详见 `tools/gen_kicad.py` 头注释）：
- 主控 y[8.5,41.5]→y[12.5,45.5]（右排孔避让缺口 + 左排孔避让 STOP 焊盘；外壳 USB 开孔 y 联动）
- 缺口纵向 [0,12]（拨杆本体 [2.4,8.8] + 主控右排孔下缘 13.53 双约束）
- 轴体旋转：STOP 0°、ENTER 第2轴 180°、VOICE 180°（电气焊盘避让主控排针）
- NPTH 定位孔省略 2 个（ENTER 第2轴、STOP——落主控区/缺口，定位脚悬空，机械靠卡扣）
- 二极管 12 只分布两条走廊（间距 ≥10.32、避支撑台禁带与主控左排孔带）

---

## 10. 风险与未知项

| # | 风险 | 影响 | 应对 |
|---|---|---|---|
| 1 | ~~三根引脚坐标未知~~ **已解除（2026-09-26）** | — | 坐标已落定：(−3.8,4.93)/(−5.9,0) 电气、(5.15,−5) 定位；官方 datasheet 像素标定 + 万用表导通对确认 |
| 2 | KiCad 库里没有 Choc V2 封装，或库里的与官方图不符 | 现成封装的引脚坐标 / 中心孔可能对不上 → **轴插不进** | Step 0 侦察；对不上就按官方图自建封装 |
| 3 | 缺口纵向位置错 | 拨杆本体压板，**整板报废** | §5.2 必须在生成前解决，并加进自动校验 |
| 4 | 定位板开孔 13.80 vs 底座外形 13.95 | 轴体装不进定位板 | 待实物复量；若需改则定位板要重打 |
| 5 | 二极管选位算法产出的位置不合法 | 装不进 | 自检项 ②③ 拦掉 |
| 6 | `pcbnew` API 版本差异 | 脚本跑不起来 | Step 0 侦察；以实际安装版本的 API 为准 |
| 7 | 主控在背面需镜像 | 引脚左右颠倒，固件对不上 | 生成后用自检核对每个引脚的网络与 `netlist.md` 一致 |

---

## 11. 本设计的边界

**包含**：生成器设计、板上元件与网表、板框与缺口、二极管坐标重算、验证方案、执行顺序。

**不包含**：

- ❌ 布线（用户在 KiCad 里完成）
- ❌ Gerber 导出与打样参数（布线后的事）
- ❌ 原理图
- ❌ 实机（校准试件 / 洞洞板原型 / 焊接）

**前置假设**：

- 用户已购**直插** 1N4148（不用贴片）
- 用户会安装 KiCad
- 布局不再变动（若物理验证后要改布局，本产物需重新生成）

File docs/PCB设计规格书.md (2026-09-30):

# ClaudePad PCB 设计规格书

**版本**：v0.2
**日期**：2026-09-20
**板子尺寸**：98.00 × 50.00 × 1.60 mm（2026-09-16 从 86 加宽，解决 USB 口够不到右壁）
**配套文件**：`pcb/netlist.json` · `pcb/netlist.md` · `pcb/wiring.svg` · `cad/lib/params.scad`

> 本文件里的所有坐标均由 `tools/gen_pcb.py` 从 `cad/lib/params.scad` 生成，与外壳/定位板/固件严格对齐。
>
> **v0.2 同步**：附录速查此前停留在 86mm 板宽 / Choc V1 的旧值，已对齐到 **98×50 / Choc V2 /
> 支撑台 40·76 / 主控 (79.70, 8.50)**；主控名称统一为 **NoLogo ProMicro NRF52840**。
> §14 保留为改动过程的历史记录，其中的 86×50 与「x=68」是当时的值。

---

## 0. 快速导航

| 你想做的事 | 看哪节 |
|---|---|
| 手焊洞洞板 | §3 接线 + `pcb/wiring.svg` |
| 画 PCB | §4 封装坐标 + §5 元件布局 |
| **拿开源设计改板** | **`docs/PCB改板方案.md`** |
| 打样下单 | §8 制造参数 |
| 检查设计对不对 | §11 验证清单 |

---

## 1. 这块板子要做什么

把 11 个轴体 + 1 个审批拨杆 + 1 个主控 + 1 个电池座连起来，装进外壳。

**设计约束（全部来自已确定的结构与固件）**：

| 约束 | 来源 | 值 |
|---|---|---|
| 板子外形 | `params.scad` 的 `PCB_W` / `PCB_H` | 98 × 50 mm |
| 板厚 | `PCB_T` | 1.6 mm |
| 矩阵 | 固件 `claudepad.overlay` | 3 行 × 6 列 |
| 引脚 | 同上 | 行 D4/D5/D6，列 D7/D8/D9/D10/D16/D14 |
| 右侧缺口 | 拨杆本体在壳内的位置 | 深 8 × 长 24 mm |
| 轴体位置 | 定位板轴孔（`params.scad`） | 见 §4 |

---

## 2. 板子外形

```
        ┌──────────────────────────────────────────────┐
        │                                              │
        │             98.00 × 50.00                    │
        │                                              │┌──┐
        │              主矩阵区                         ││缺│
        │                                              ││口│ 8×24
        │                                              │└──┘
        └──────────────────────────────────────────────┘
```

**右侧缺口**：深 8mm、纵向 24mm，位置对准拨杆。
原因：SPDT 拨杆的**本体在壳内**（拨杆+轴套+螺母在壳外），本体沿轴套方向侵入约 8.5mm。
不给它让位，本体就会压到 PCB 上。

**四角不要放安装孔**：PCB 不靠螺丝固定——它由 14 个轴体「挂」着（轴体卡在定位板上，定位板用 4 颗 M2 螺丝锁在底座上）。
这是键盘的常规做法，PCB 无需额外固定。

---

## 3. 矩阵接线

完整接线图见 **`pcb/wiring.svg`**（可打印放大），焊接对照表见 **`pcb/netlist.md`**。

### 3.1 二极管方向（关键）

```
固件配置：diode-direction = "col2row"
含义：    二极管阳极接列线，阴极接行线
电流方向：列 → 行
```

每个按键回路：

```
列线 ──▶ 二极管阳极 ──▶ 二极管阴极 ──▶ 轴体 ──▶ 行线
```

**为什么是这个方向**：`col2row` 时列是**输出驱动**（`GPIO_ACTIVE_HIGH`），行是**输入读取**（`GPIO_ACTIVE_HIGH | GPIO_PULL_DOWN`）。二极管必须允许电流从被驱动的列流向被读取的行。

> ⚠️ **接反不会烧，但矩阵完全读不出来。**
> 修正二选一：把所有二极管掉头，或把固件里的 `diode-direction` 改成 `"row2col"`。
> 后者更省事，但以后别人看板子会困惑——建议前者。

### 3.2 引脚分配

| 信号 | 引脚 | 方向 |
|---|---|---|
| ROW1 / ROW2 / ROW3 | D4 / D5 / D6 | 输入（PULL_DOWN） |
| COL1 … COL6 | D7 / D8 / D9 / D10 / D16 / D14 | 输出 |
| RGB 数据 | D15 | 输出 |

> 这套分配必须与 `firmware/config/boards/shields/claudepad/claudepad.overlay` 一致。
> `tools/check_keymap.py` 现在会**自动交叉校验**行/列引脚与二极管方向（2026-10-01 补上），
> 与 `pcb/netlist.json` 不一致会直接报错 —— 不再依赖人工确认。

### 3.3 大键并联（重要）

回车和空格在定位板上分别开了 2 个和 3 个轴孔（解决长键翘曲）。这些轴体在**电气上并联**：

| 大键 | 轴体数 | 都接到 |
|---|---|---|
| **回车**（2u） | 2 | ROW2 × COL4 |
| **空格**（4u） | 3 | ROW3 × COL1 |

**PCB 上要把这几个轴体的焊盘用铜箔连到同一条行/列线上**，否则会变成多个独立按键。
手焊洞洞板时，就是用一根导线把它们的引脚串起来。

### 3.4 审批拨杆

| 项 | 值 |
|---|---|
| 位置 | 右壁（不在轴体网格里） |
| 接线 | 公共端 → ROW1；常开端 → COL6（D14） |
| 二极管 | **建议串一只 1N4148** —— 拨杆是开关不是轴体，不串可能在多键同按时产生鬼影 |

拨杆是**两态**器件：拨到 ON 时持续接通 ROW1–COL6，固件读到的就是一个「一直按住的 F13」。

---

## 4. 轴体封装坐标

**Kailh Choc V2 (PG1353)**，原点 = 轴芯中心。

> **来源：凯华官方规格图**（PCB 板安装示意图）。
> ⚠️ 2026-09-21 修订：此前本节依据两个开源封装库（`daprice/keyswitches.pretty` 与
> `siderakb/key-switches.pretty`）「交叉验证」，但**实物实测与该表不符 —— 两个库一起错了**。

官方图确认的数据：

| 特征 | 孔径 mm | 数量 | 类型 |
|---|---|---|---|
| 金属电气脚 | **1.20** | **2** | 金属化（PTH）★ 官方图标注 `2-Ø1.20`，通电 |
| 不通电定位脚 | **1.50** | **1** | 非金属化（NPTH），轴体第 3 脚，不导通（官方图 `2*1.5`） |
| 轴芯中心孔 | **5.00** | 1 | 非金属化（NPTH）★ 让位给中央 Ø4.80 塑料凸台 |
| LED 焊盘 | — | 1 | 官方图标注 `LED` |

**★ 三根引脚坐标（2026-09-26 按官方 datasheet 最终落定）**：

| 引脚 | 坐标 (x, y) mm | 孔径 | 类型 |
|---|---|---|---|
| 电气脚 1 | (−3.80, 4.93) | Ø1.20 | PTH，通电 |
| 电气脚 2 | (−5.90, 0.00) | Ø1.20 | PTH，通电 |
| 定位脚 | (5.15, −5.00) | Ø1.50 | NPTH，不导通 |
| LED 焊盘 | (5.15, 0.00) | — | 焊盘 |

依据：凯华官方 datasheet（CPG135301D01，2020-10-23 版）Recommended PCB Layout，
600dpi 矢量图像素标定 + 双尺寸交叉验证（误差 0.1%）。
⚠️ **siderakb 等社区封装的三个孔坐标是官方坐标的 x/y 互换错版**（(−5.90,0)→(0,5.9)，
(−4.93,3.8)→(−5,3.8)，(5.15,−5)→(5,−5.15)），勿再引用；两两间距实测无法区分这组镜像。
**2026-09-26 用户已用万用表实测确认**：按下导通的一对即电气脚。
PCB 必须钻满 3 个孔，一个都不能省。

**外形**：官方图标注 **15 × 15 × 5.3mm**，底座外形 **13.95 × 13.95mm**。

> ⚠️ 定位板开孔当前是 **13.80**（`params.scad` 的 `SWITCH_CUTOUT`），而 **13.95 > 13.80**。
> 若底座需穿过定位板，此孔偏小 → 轴体装不进。**待实物复量后定。**

**每个轴体的绝对位置**（PCB 坐标系，原点 = PCB 左下角）：

| 按键 | 轴体坐标 (x, y) |
|---|---|
| 访问等级 PERM | (13, 7) |
| ↑ UP | (31, 7) |
| 模型 MODEL | (49, 7) |
| 命令行 CMD | (67, 7) |
| 停止 STOP | (85, 7) |
| ← LEFT | (13, 25) |
| ↓ DOWN | (31, 25) |
| → RIGHT | (49, 25) |
| 回车 ENTER | (67, 25) **和** (85, 25) |
| 空格 SPACE | (13, 43) **(40, 43)** **(67, 43)** |
| 语音 VOICE | (85, 43) |

> 空格三个轴在 x = 13 / 40 / 67，跨 54mm，配合 4u 键帽的 3 个榫槽。
>
> ⚠️ 这组坐标随 **PCB 加宽**整体 +6mm（原 7/25/43/61/79）。权威来源是
> `pcb/placement.csv`（由 `tools/gen_pcb.py` 生成），改 PCB 尺寸后重跑该脚本即可同步。

---

## 5. 元件布局

| 元件 | 位置 | 说明 |
|---|---|---|
| 14 个轴体 | 见 §4 | 主矩阵 |
| 14 只 1N4148 | 每个轴体旁 | 建议放在轴体与行线之间，占用小 |
| NoLogo ProMicro NRF52840 | **PCB 背面（下表面）右侧**，**直接焊在板上** | 见下 |
| 审批拨杆引线焊盘 | 右侧缺口附近 | 公共端→ROW1，常开端→COL6 |
| 电池引线焊盘（B+ / B−） | 左侧空区 | 电池在 PCB 正下方，走线穿过 |
| 电源开关焊盘 | 左侧 | 串在电池正极与主控之间 |
| 复位按钮焊盘 | 主控旁 | 并联到 RST |
| WS2812 | 沿轴体分布 | 数据线 D15 |

### 5.1 主控必须直焊，不能用排母

主控装在 **PCB 背面**，那一层（`PCB_STANDOFF_H`）只有 **5.0mm**，
而主控本体 3.2mm + 普通排母 2.54mm = **5.74mm，超了**。

所以主控必须**直接焊接在 PCB 上**（板对板），引脚朝上穿过 PCB 焊在正面。这是「薄」换来的代价。

主控位置：PCB 背面右侧，USB-C 口朝**右侧**，对准外壳右壁的 USB 开孔。

> 同一层还有电池（贴左壁）。两者平面错开、互不重叠，但一起受这 5.0mm 限制 —— 详见 `docs/结构设计规格书.md` §1.3。

### 5.2 PCB 支撑台位置（与外壳的配合）

外壳里有 4 个矮柱托住 PCB，位置在 **PCB 坐标 (40,16)、(76,16)、(40,34)、(76,34)**。

> ⚠️ 这些位置是**轴体之间的空隙中心**，不是四角。
> 轴体之间只有 `18 − 13.5 = 4.5mm` 空隙，四角正好是轴体塑料脚的位置，支撑台放那里会顶住装不进去。
> 支撑台直径 4.0mm < 4.5mm 空隙。
>
> 合法的空隙中心是 x ∈ {22, 40, 58, 76}、y ∈ {16, 34}。取 40 / 76 是因为
> x=22 被电池占、x=58 与主控（x=79.7 起）不对称。校验见 `check_dims.py` 第 19–22 项。

画 PCB 时**不需要**为它们开孔（支撑台在 PCB 下方，只是托着）。

---

## 6. 布线规格

| 项 | 建议值 | 理由 |
|---|---|---|
| 铜厚 | 1 oz（35µm） | 常规，够用 |
| 行/列信号线宽 | **0.25 mm** | 信号线电流极小 |
| 电源线宽（3.3V / VBAT） | **0.6 mm** | 主控峰值电流 + RGB |
| GND 线宽 | **0.6 mm** 或铺铜 | 回流路径 |
| 线间距 | ≥ 0.2 mm | 嘉立创常规工艺 |
| 过孔 | 0.3/0.6 mm | 常规 |
| 层数 | **2 层** | 足够，成本低 |

**布线要点**：

1. **行线/列线尽量走到底层**，顶层留给轴体焊盘和元件
2. **WS2812 的数据线串一颗 100–300Ω 电阻**（靠主控端），防振铃
3. **RGB 电源加 100µF 电解 + 0.1µF 陶瓷**去耦，否则灯珠闪烁
4. 天线区（主控的板载天线在 **PCB 背面**，其正下方的**底层投影区**）**不要铺铜、不要走线**，否则蓝牙距离骤降
5. 大键并联的几个轴体，用同一根粗一点的线（0.4mm）串起来

---

## 7. 与外壳/定位板的配合

| 接口 | 值 | 校验方式 |
|---|---|---|
| 板子外形 | 98 × 50 mm | `check_dims.py` 第 7 项 |
| 板厚 | 1.6 mm | 与 `PCB_T` 一致 |
| 轴体位置 | 与定位板轴孔同心 | `gen_pcb.py` 从 `params.scad` 取 |
| 右侧缺口 | 深 8 × 长 24 mm | `check_dims.py` 第 11 项 |
| PCB 上方净空 | 5.0 mm | 只走轴体引脚，决定了「主控不能放正面」 |
| PCB 下方净空 | 5.0 mm | 主控 + 电池；决定主控必须直焊（排母会超） |
| 支撑台避让 | 支撑台在空隙中心 | `check_dims.py` 第 19–22 项 |

**装配关系**：

```
        定位板（4 颗 M2 螺丝锁在底座上）
          │
          │ 轴体穿过定位板、焊在 PCB 上
          ▼
        PCB  ──── 由轴体「挂着」，同时被 4 个支撑台托住
          │
          │ 电池 + 走线在 PCB 下方
          ▼
        底座底板
```

---

## 8. 制造参数（嘉立创打样）

| 参数 | 值 |
|---|---|
| 层数 | 2 层 |
| 尺寸 | 98 × 50 mm |
| 板厚 | 1.6 mm |
| 铜厚 | 1 oz |
| 阻焊颜色 | 任意（建议哑黑，视觉干净） |
| 丝印 | 白 |
| 表面处理 | 有铅喷锡（最便宜）或沉金 |
| 最小线宽/间距 | 0.25 / 0.2 mm（常规工艺范围内） |
| 最小孔径 | 0.3 mm（本项目最小是 1.27，很宽裕） |

> 板子很小，嘉立创 5 片起打，成本极低。建议**多打几片**——首片焊坏了不用重等。

---

## 9. 打板前必做的三件事

1. **先打外壳和定位板，实测 `SWITCH_PLATE_GAP`**
   （用 `cad/test_coupon.scad` 校准件，15 分钟）
   这个值决定 PCB 上轴体焊盘与定位板的相对高度关系，虽然 PCB 本身不受影响，
   但**主控高度**受它约束——如果实测值 < 3.7mm，主控方案要改。

2. **确认拨杆实物尺寸**
   轴套直径/长度、面板尺寸、**本体侵入深度**。本体侵入 > 8.5mm 的话，缺口要加深。

3. **确认 NoLogo ProMicro 的封装尺寸**
   17.78 × 33.00mm 是标称值，实物可能有偏差。特别是 USB-C 口的位置——它要和外壳右壁的开孔对齐。

---

## 10. 手焊洞洞板（不用打 PCB 的路线）

如果想先验证电路再打板，按 `pcb/wiring.svg` 在洞洞板上焊：

**需要的洞洞板**：至少 98 × 50 mm（留余量）

**步骤**：

1. 先焊 14 只二极管，**统一方向**（阳极朝列）
2. 用裸铜线沿列走 6 条、沿行走 3 条，构成矩阵
3. 每个轴体位置焊两个排针座（或用飞线直接连轴体）
4. 大键的多个轴体，用一根线把它们的引脚串起来
5. 最后接主控、拨杆、电池座

> 洞洞板版本的轴体无法插进去固定，只能**用飞线把轴体引出来**，或者先不装轴体、用镊子短接焊盘测试固件。

---

## 11. 验证清单

打板前逐项确认：

```
□ 板子外形 98 × 50 mm
□ 右侧缺口 深 8 × 长 24 mm，位置对准拨杆
□ 14 个轴体位置与 §4 表格一致
□ 引脚共 **3 个孔**：电气 2 孔 **Ø1.20 PTH**（官方图 `2-Ø1.20`）+ 不通电定位 1 孔 **Ø1.50 NPTH** —— 一个都不能省
□ 中心孔 **Ø5.00** 非金属化
□ 二极管统一方向：阳极接列、阴极接行
□ 回车两个轴、空格三个轴各自并联到同一交点
□ 引脚分配与 claudepad.overlay 一致
□ 主控天线区无铺铜、无走线（天线在 PCB 背面）
□ 主控焊在 PCB **背面**，引脚朝上穿板焊在正面
□ 主控 USB 口位置与外壳右壁开孔对齐（开孔 z = PCB 下表面 −1.80 = 5.20）
□ PCB 四角无安装孔（不需要）
□ 支撑台位置不需开孔
```

---

## 12. 本规格书的边界

**包含**：板子外形、矩阵接线、封装坐标、元件布局、布线规格、与外壳的配合。

**不包含**：
- ❌ **具体 PCB 布局文件**（KiCad 工程）——本文件给的是**设计规格与坐标**，画板需要你在 KiCad 里落地
- ❌ **原理图符号库**——直接用 KiCad 自带的 Switch/Diode 符号即可
- ❌ **RGB 灯珠的具体数量与排布**——取决于你想要的灯效，见 PRD 第 8 章

**未验证项**：
- 本规格书的数据来自 `params.scad` 与两个开源封装库，**逻辑与坐标已交叉验证**
- 但**没有生成实际的 PCB 文件并用 DRC 检查过**，也没有打样实测
- 首次画板后，请用 KiCad 的 DRC 跑一遍，并对照 §11 清单人工确认

---

## 13. 能买现成的 PCB 吗？

**结论：不能。** 而且原因比"布局特殊"更根本。

### 13.1 根本障碍：我们的轴体不在标准网格上

标准宏键盘 PCB 是**均匀网格**——每 18mm（Choc）或 19.05mm（MX）一个格点，每个格点一个独立矩阵节点。

本设计的轴体坐标（PCB 原点在左下，单位 mm）：

| 键 | 坐标 |
|---|---|
| 第 1 行 5 键 | x = 13, 31, 49, 67, 85（y=7） |
| 第 2 行 3 键 + 回车 2 轴 | x = 13, 31, 49, 67, 85（y=25） |
| 空格 3 轴 | **x = 13, 40, 67**（y=43） |
| 语音 | x = 85（y=43） |

网格线是 **13 / 31 / 49 / 67 / 85**。而空格的中间那根轴在 **x = 40** —— **它不在网格上**。

这不是失误：4u 键跨列 1–4，跨度 72mm，三点对称支撑落在 1/6、3/6、5/6 处，中点正好是跨度中心。
**任何均匀网格的 PCB 都放不下它。**

### 13.2 其余三个不匹配

| 维度 | 本设计 | 市面现成宏键盘 PCB |
|---|---|---|
| 主控 | NoLogo ProMicro（nRF52840）+ BLE | 多为 Pro Micro（ATmega32u4）+ USB 有线 |
| 固件 | ZMK | 多为 QMK（引脚与配置不通用） |
| 轴体 | Kailh Choc **V2** 矮轴，18mm 键距 | 多为 MX，19.05mm 键距 |
| 板形 | 98 × 50，右侧 8×24 拨杆缺口 | 尺寸与缺口都对不上 |

### 13.3 那怎么办？三条实际路径

| 路径 | 说明 | 适用时机 |
|---|---|---|
| **A. 洞洞板手焊** | 用 §10 的接线图 + `pcb/wiring.svg` 直接焊。零等待、成本最低 | **原型验证阶段（推荐先走这条）** |
| **B. 拿开源设计改** | 立创开源硬件平台（oshwhub）上有现成的**无线矮轴小键盘**项目，已解决最难的部分：nice!nano 引脚、电池接口、充电电路、电源开关、Choc 轴座封装、ZMK/RMK 固件。只需改布局 + 加拨杆缺口。**详细方案见 `docs/PCB改板方案.md`** | 想要正式 PCB 但不想从零画 |
| **C. 从零画板打样** | 本规格书已给全部网表与坐标，2 层板，嘉立创 5 片起 | 布局定稿后 |

**参考开源项目**（oshwhub 搜索可得，均为无线矮轴 + nice!nano）：
- **EPPad** —— 无线小键盘，凯华/佳达隆两种轴座孔，资料最全（原理图+PCB+BOM+结构）→ **推荐作底板**
- **TK13** —— 凯华矮轴，结构简单，但无 BOM

> ⚠️ 这些项目**布局都与本设计不同**，只能拿来复用「主控电路 + 轴座封装 + 固件框架」，
> 布局必须自己改。**具体怎么做见 `docs/PCB改板方案.md`** —— 含复用清单、
> 三个必先解决的冲突（热插拔高度冲突 / 板形 / 离格轴）、分步流程与验证清单。

### 13.4 为什么建议先洞洞板

1. **布局还没经过实物验证** —— 大键手感、拨杆位置、整体厚度都只是纸面设计
2. **洞洞板改起来零成本**，PCB 改一次要等一周
3. 项目本来就是分步推进的（`docs/采购清单.md` 第 1 步 → 第 3 步）

**顺序建议**：校准试件 → 洞洞板原型 → 实机验证手感 → 定稿布局 → 打样 PCB。

---

## 14. ★ 已解决的阻塞问题：主控放不下

**2026-09-15 发现，2026-09-16 解决。** 本节保留为改动过程记录 ——
**其中的 86 × 50、"x = 68 / y = 8.5"、支撑台 34/52 都是当时的值，不是现状。**
当前值见文首与附录速查：板 98×50、主控 (79.70, 8.50)、支撑台 40/76。

它当时影响**所有**路径（买现成 / 改开源 / 自己画）——
不是 PCB 的问题，是**布局本身没有给主控留位置**。

### 14.1 问题

主控 nice!nano 是 **17.8 × 33.0 mm**，而板面只有 **86 × 50 mm**，
上面已经摆了 **14 个轴体**（本体 13.5mm 见方，占 2550 mm²，板面共 4300 mm²）。

穷举板面所有位置（步长 0.5mm）：

| 检查 | 结果 |
|---|---|
| 当前设计位置（PCB 坐标 65.2, 14.0） | ❌ 与轴体重叠 **322.52 mm²** |
| 板面上零重叠的位置数 | **0 个** |

重叠的 4 个轴体：

| 键 | 轴心 | 重叠面积 |
|---|---|---|
| 回车（第 2 轴） | (79, 25) | ~146 mm²（几乎整个轴体） |
| 语音 | (79, 43) | ~116 mm²（几乎整个轴体） |
| 回车（第 1 轴） | (61, 25) | ~34 mm² |
| 空格（第 3 轴） | (61, 43) | ~27 mm² |

**根因**：3×5 网格在 18mm 键距下需要 **90 × 54 mm** 才排得开，
而 PCB 只有 86 × 50 —— 轴体本体几乎贴到板边（四边各余 0.25mm），**没有任何连续空位**。

> 这条已固化为 `tools/check_dims.py` 第 11 节的两项自动检查，不会再被漏掉。

### 14.2 解决方案（推荐：主控移到 PCB 背面）

PCB 下方有 **5.0 mm** 层高，主控厚 **3.2 mm** —— **放得下**。

背面布局（PCB 坐标）：

```
        ┌────────────────────────────────────────┐
        │                                        │
        │        电池 30×40（居中偏左）           │
        │      x 30.55~60.55  y 7.55~47.55       │
        │                          ┌───────────┐ │
        │                          │  主控      │ │
        │                          │ 17.8×33   │ │
        │                          │x68~85.8   │ │
        │                          │y8.5~41.5  │ │
        └──────────────────────────┴───────────┴─┘
```

**推荐位置**：`x = 68.0, y = 8.5`（最靠右，USB-C 朝右壁）

### 14.3 连带要改的三处

| # | 改什么 | 从 | 到 |
|---|---|---|---|
| 1 | **右侧支撑台** | x = 70（会被主控压住） | **x = 52**（合法的轴体间隙中心） |
| 2 | **USB-C 开孔高度** | PCB 上表面 +1.8mm | PCB 下表面 −1.8mm |
| 3 | 天线净空 | 主控正上方禁铺铜 | 改为**主控正下方**（PCB 背面）禁铺铜 |

**支撑台为什么能挪**：合法位置是轴体间隙中心，x ∈ {16, 34, 52, 70}、y ∈ {16, 34}。
把右侧两个从 70 挪到 52 仍在合法集合内，且避开主控（52 < 68）。

### 14.4 备选方案

| 方案 | 做法 | 代价 |
|---|---|---|
| **A. 主控放背面**（推荐） | 见 §14.2 | USB 开孔下移；天线区改到背面 |
| B. 换更小主控 | 用 E73-2G4M08S1E 等模块（约 13×18mm） | 需自己加充放电电路；固件要改引脚 |
| C. 加大板子/外壳 | PCB 加宽到 96mm 以上 | 整机尺寸变大，外壳全部重做 |
| ~~D. 改用 ESP32~~ | **已评估，否决**（见 §14.4.1） | — |

**方案 B 的额外好处**：EPPad 作者也提到 nice!nano 多为 2020 年产芯片、**容易坏**，
建议改用 E73 + 自加充放电。如果要走这条路，值得一并考虑。

### 14.4.1 已评估并否决：ESP32（2026-09-16）

用户问过「能不能用 ESP32-WROOM-32 做主控」。**结论：不行，三个硬伤。**

| 硬伤 | 数据 | 来源 |
|---|---|---|
| **① 装不进** | ESP32-DevKitC 开发板 **54.4 × 27.9 × 10 mm**；而键盘 PCB 上方净空 **3.40mm**、下方 **5.0mm** | 乐鑫官方 / 厂商规格 |
| **② 焊不了** | 纯模组 **18.00 × 25.50 × 3.10 mm**，38 脚，**引脚间距 1.27mm**。洞洞板是 2.54mm 网格，插不进；手工焊需热风枪或拖焊 | `ESP32-WROOM-32_datasheet_cn.pdf` v3.8 第 32 页 |
| **③ 固件要自己写** | ESP32 **跑不了 ZMK**，需用 ESP-IDF + FreeRTOS 自己实现矩阵扫描 / 去抖 / BLE HID 报告 / 休眠状态机 | — |

**外加：功耗差一个数量级**

| 方案 | 500mAh 电池续航 | 出处 |
|---|---|---|
| nice!nano (nRF52840) | **约 25 天** | kriscables 官方 FAQ（110mAh + 每天 8h = 5–7 天，换算） |
| ESP32-C3 低功耗模式 | 约 2 天 | 实测（9.5mA） |
| ESP32-C3 默认设置 | 约 5 小时 | 实测（93mA） |
| ESP32-WROOM-32 | 比 C3 更差（初代双核，非低功耗设计） | — |

> **关键差异不在睡眠电流，而在连接状态**：nRF52840 深度睡眠 **20µA 且保持蓝牙连接**；
> ESP32 深度睡眠虽低至 5µA，但**必须断开蓝牙**，唤醒后需 **3–5 秒**重连，期间按键无响应。
> 对键盘而言这是体验硬伤。

**外围也全要自己加**：无 USB（需 CH340/CP2102）、无稳压（锂电 3.7–4.2V 需 LDO）、
无充电管理（需 TP4056/IP5306）。nice!nano 全部板载。

**如果确实想走 ESP32 系**：选 **ESP32-C3** 而非 WROOM-32（功耗与尺寸都更好，
且内置 USB Serial/JTAG 可直接烧录，省掉一个芯片）。立创开源平台有现成的
「ESP32-C3 17 键 BLE 数字小键盘」可参考（CC BY-NC-SA 4.0，Gitee 有源码）。

**如果想省钱**：用 **SuperMini nRF52840**（约 20–30 元）—— Pro Micro 引脚兼容、
**2.54mm 通孔**、能跑 ZMK、低功耗。该有的都有，钱也省了。

### 14.5 待办

- [x] 确认采用哪个方案 —— **2026-09-16 选定方案 A（主控放背面）**
- [x] 更新 `cad/lib/params.scad`（加主控位置参数）
- [x] 更新 `cad/case_bottom.scad`（挪支撑台、移 USB 开孔、电池让位）
- [x] 重新跑 `tools/check_dims.py` 确认 26 项全绿
- [x] 重新导出 STL 并验证

**实施记录（2026-09-16）**

| 项 | 从 | 到 |
|---|---|---|
| 主控安装面 | PCB 正面（上表面） | **PCB 背面（下表面）**，`NANO_ON_BACK = true` |
| 主控位置（PCB 坐标） | (65.2, 14.0) | **(68.0, 8.5)** |
| 支撑台 x | 16 / 70 | **34 / 52** |
| 电池 x（PCB 坐标） | 28.15 ~ 58.15（居中） | **−8 ~ 22（贴内腔左壁）** |
| USB 开孔 z | `PCB_TOP_Z + 1.80` = 10.40 | **`PCB_BOTTOM_Z − 1.80` = 5.20** |

**为什么电池也要挪**：主控移到背面右侧后，支撑台必须用 x=34/52 这两个间隙中心
（x=70 被主控占、x=16 让给电池）。而**居中的电池（x 28.15~58.15）正好盖住 34 和 52** ——
四个候选位置会全部冲突。所以电池让位到左侧，PCB 坐标 x −8~22。

> 这是改板过程中**新暴露**的连锁问题：原设计（主控在正面、电池居中、支撑台 16/70）
> 本身是自洽的，但一旦主控移到底面右侧，三个元件就在同一层里抢位置。

**校验结果**：`check_dims.py` **26 项全部通过**（项目首次全绿）。
`lint_scad` / `verify_geometry` / `check_keymap` / `verify_stl` 全部通过，6 个 STL 已重新导出。

**⚠️ 已打印的外壳需要重做**：支撑台位置在底板上、USB 开孔在右壁上，两处都变了。
顶盖和定位板不受影响。

---

### 14.6 ✅ 已解决：USB 口够不到外壳右壁（2026-09-16 发现并当天解决）

**现象**：主控装在 PCB 背面后，USB 口位于主控右缘 = PCB 坐标 x 85.8。
PCB 右边缘在 86，而内腔右壁在 94 —— **USB 口距内腔右壁 8.2mm**。

**后果**：标准 USB-C 插头的金属部分只有 **6.5mm**，插入时够不到 USB 座，
**插不到底、可能接触不良**。

**根因**：PCB 比内腔小 16mm（每边 8mm）。
`PCB_W = GRID_W − 4 = 86`，而定位板 `= GRID_W + 12 = 102`，内腔 102.3。
**无论主控放正面还是背面、横放还是竖放，这个距离都消不掉** ——
换安装面只是把它从 11.3mm 改善到 8.2mm，没有根治。

**四个候选解法**：

| 方案 | 做法 | 代价 |
|---|---|---|
| **A. USB-C 面板延长线**（推荐） | 买一根「面板安装式 USB-C 公转母延长线」，公头插主控、母座固定在右壁孔上 | 多一个元件（约 10 元）；右壁开孔改为按母座尺寸 |
| B. PCB 加宽 | `PCB_W` 从 86 加到约 100，四角切角避开螺丝柱 | 改 PCB 设计；需重新验证轴体焊盘与定位板对位 |
| C. 主控 USB 端探出 PCB | 主控右移，右侧引脚用飞线补 | 引脚悬空，不可靠，不推荐 |
| D. 接受现状 | 插头只能插到 6.5mm | **不推荐**，可能接触不良 |

**状态**：✅ **已解决 —— 采用方案 B（PCB 加宽）**

用户 2026-09-16 决定「不买延长线，直接改 PCB」（外壳尚未开工，改动成本最低）。

**实施**：`PCB_W` 从 86 加宽到 **98**（`PCB_X` 由 8 变 2），主控随之右移到 x=80。

| 检查 | 结果 |
|---|---|
| PCB 右缘距内腔右壁 | **2.15 mm** |
| 插头插入深度 = 壁厚 + 该距离 | 2.4 + 2.15 = **4.55 mm** |
| 插头金属部分长度 | 6.5 mm |
| 判定 | ✅ **4.55 < 6.5，够得到** |

**为什么加宽不会撞四角螺丝柱**：PCB 占 y 8~58，而螺丝柱占 y 1.5~6.5 与 59.5~64.5 ——
两者在 y 方向天然错开，所以 PCB 在 x 方向可以一直延伸到接近内腔壁。

**连带改动**：PCB 加宽使 `PCB_X` 从 8 变 2，所有「列间隙中心」整体左移 6mm，
支撑台从 34/52 改为 **40/76**（间距 36mm，对称，且与电池、主控都留有余量）。

**副产物**：PCB 面积从 4300 增至 4900 mm²，布线余量更大。

**同时发现并修复的检查器 bug**：`check_dims.py` 里 x 和 y 方向的偏移**都用了 PCB_X**。
原设计 `PCB_X == PCB_Y == 8`，巧合正确；PCB 加宽后 `PCB_X` 变 2，y 方向检查立即误报。
已改为各自使用 `PCB_X` / `PCB_Y`。

---

## 附：一页速查

```
【板子】98 × 50 × 1.6 mm，2 层，右侧缺口 8×24

【矩阵】3 行 × 6 列
  行 D4/D5/D6（输入，PULL_DOWN）
  列 D7/D8/D9/D10/D16/D14（输出）

【二极管】col2row：阳极接列、阴极接行，电流 列→行

【轴体封装】Choc V2 (PG1353)，原点=轴芯中心 —— **来源：凯华官方规格图**
  物理引脚 ×3（一个都不能省）：
    电气脚 ×2  孔径 Ø1.20 PTH    ← ★ 官方图 `2-Ø1.20`，通电
    定位脚 ×1  孔径 Ø1.50 NPTH   ← 不通电
  中心孔   ×1   孔径 Ø5.00 NPTH   ← 让位给中央 Ø4.80 塑料凸台
  另有 1 个 LED 焊盘
  外形 15 × 15 × 5.3 ｜ 底座外形 13.95 × 13.95
  ★ 引脚坐标最终落定（官方datasheet像素标定）：(-3.8,4.93)电气 / (-5.9,0)电气 / (5.15,-5)定位Ø1.5

【轴体坐标】网格线 13/31/49/67/85，行 7/25/43（PCB 坐标）
  ★ 空格中间轴在 x=40 —— 离格值，放置时关掉网格吸附
  权威来源：pcb/placement.csv（python tools/gen_pcb.py 生成）

【大键并联】回车 2 轴 → ROW2×COL4 ｜ 空格 3 轴 → ROW3×COL1

【主控】NoLogo ProMicro NRF52840，装在 PCB 背面
  位置 (79.70, 8.50)（PCB 坐标），USB-C 朝右壁
  ★ 必须直焊，不能用排母（下方层只有 5.0，主控 3.2 + 排母 2.54 = 5.74 超了）
  【主控选谁】nRF52840 系（NoLogo ProMicro / nice!nano / E73）。不要 ESP32（见 §14.4.1）
  天线在 PCB 背面 → 背面天线投影区禁铺铜
  USB 开孔 z = PCB 下表面 −1.80 = 5.20

【支撑台】外壳侧在 PCB (40,16)(76,16)(40,34)(76,34)，板子上不用开孔

【生成命令】python tools/gen_pcb.py
【改键位后】python tools/check_keymap.py 会校验固件与结构是否一致

【能买现成的吗】不能 —— 空格中间轴在 x=40，不在 18mm 网格上（见 §13）
【推荐顺序】校准试件 → 洞洞板原型 → 验证手感 → 定稿 → 打样
```

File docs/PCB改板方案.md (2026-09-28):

# ClaudePad PCB 改板方案（路径 B：拿开源设计改）

**日期**：2026-09-15（**2026-09-20 同步**：板形 86 → **98mm**、空格离格轴 x=34 → **40**、主控改到 **PCB 背面**）
**路径**：不改布局、不从零画板 —— 拿一个成熟的开源无线矮轴键盘工程做底板，替换布局
**配套文件**：`pcb/placement.csv`（元件坐标表）· `docs/PCB设计规格书.md` §13

---

## 0. 结论速览

| 项 | 结论 |
|---|---|
| **选定底板** | **EPPad**（立创开源硬件平台，作者 HAVIS，GPL 3.0） |
| **复用** | nice!nano 载板电路 · 凯华矮轴封装 · 贴片二极管 · 结构做法 |
| **重做** | 布局 · 板形 · 矩阵 · 拨杆接线 · 固件 |
| **★ 必须先解决** | **不能用热插拔轴座**（高度冲突，见 §3.1） |
| **合规** | EPPad 是 GPL 3.0 → 本项目若基于它改板，**必须同样开源**（见 §7） |

---

## 1. 为什么选 EPPad

调研过的候选：

| 项目 | 来源 | 布局 | 主控 | 轴体 | 提供什么 | 结论 |
|---|---|---|---|---|---|---|
| **EPPad** | oshwhub | 20 键（4×5） | **nice!nano** / Monkey / TuCore | **凯华/佳达隆矮轴** | 原理图 + PCB + **BOM** + 定位板/底板 + 3D | ✅ **选定** |
| TK13 | oshwhub | 10 键 | nice!nano | 凯华矮轴 | 壳 STEP + 固件，**无 BOM** | 资料太少 |
| sticc14 | GitHub | 3×5 均匀网格 | Pro Micro | MX | KiCad + gerber | ❌ 有线、无大键 |
| 其他 GitHub 宏键盘 | GitHub | — | — | — | 多为**固件配置**，非硬件 | ❌ |

**选 EPPad 的三个理由**：

1. **同时满足「无线 + nice!nano + 凯华矮轴」** —— 这三个条件同时满足的开源项目极少
2. **资料最全** —— 有原理图、PCB 源文件、BOM（含具体型号）、定位板与底板示例
3. **规模最接近** —— 20 键 vs 我们 14 轴，差得不多

> ⚠️ EPPad 作者自己提到：市面 nice!nano 多为 2020 年产芯片，**容易坏**，建议买正品。
> 这一点与本项目 `docs/采购清单.md` 的提醒一致。

---

## 2. 复用什么 / 重做什么

### 2.1 直接复用（省掉大部分工作）

| 项 | 说明 |
|---|---|
| **nice!nano 载板电路** | 引脚 breakout、电池接口、电源开关、复位按钮 —— 这是最难自己搞对的部分 |
| **凯华矮轴封装** | 轴体焊盘 + 定位柱孔（本项目已交叉验证过坐标，可互相印证） |
| **贴片二极管封装** | EPPad 用 0805 的 CD4148WSP，比直插省空间 |
| **结构做法** | 定位板厚度、铜柱高度、电池固定方式 |
| **BOM 型号** | 照抄，避免选型踩坑 |

### 2.2 必须重做

| 项 | 从 | 到 |
|---|---|---|
| **轴体布局** | 20 键均匀网格 | 14 个轴体的坐标（含 **x=40 离格轴**） |
| **板形** | EPPad 外形 | **98 × 50 mm + 右侧 8×24 拨杆缺口** |
| **矩阵** | EPPad 的矩阵 | **3 行 × 6 列**（第 6 列给拨杆） |
| **新增 SPDT 拨杆** | 无 | 接到 ROW1 × COL6 |
| **固件** | RMK | **本项目的 ZMK shield**（`firmware/`） |

---

## 3. 三个必须先解决的冲突

### 3.1 ★ 不能用热插拔轴座（最硬的约束）

EPPad 用的是**凯华矮轴热插拔轴座**，但我们用不了：

| | 数值 |
|---|---|
| 热插拔轴座在 PCB **下方**凸出 | **2.5 – 3.0 mm** |
| 而 PCB 下方总共只有（`PCB_STANDOFF_H`） | **5.0 mm** |
| 电池已占（`BATT_H` 4.0 + `BATT_TAPE_T` 0.6） | **4.6 mm** |
| 剩余 | **0.4 mm** ← 装不下轴座 |

**结论：必须改成直焊**（轴脚穿过 PCB 后剪平，凸出 < 0.5mm）。

| | 热插拔 | **直焊（采用）** |
|---|---|---|
| 占用 PCB 下方高度 | 2.5–3.0 mm | < 0.5 mm |
| 能否换轴 | 能 | 不能 |
| 焊接难度 | 低 | 中（14 个轴 × 2 脚） |

**代价可接受**：这是把键盘做到 23.3mm 薄必须付的成本。

> 顺带说明：本项目在 `docs/结构设计规格书.md` 里早就按直焊设计，
> 这条冲突是**改板时才会暴露**的 —— 直接照抄 EPPad 会装不进去。

### 3.2 板形与网格尺寸对不上

| | 尺寸 |
|---|---|
| EPPad 的 4×5 网格 | 约 **90 × 72 mm** |
| 本项目的板 | **98 × 50 mm** |

板形必须完全重画。但这不是问题——「改板」的本意就是重画布局。

### 3.3 离格轴（最容易漏的一条）

空格中间那根轴在 **x = 40**，而网格线是 13 / 31 / 49 / 67 / 85 —— **它不在网格上**。

**操作要点**：放置时**关掉网格吸附**（KiCad 里按 `N` 或改 grid 为 0.01mm），
严格照 `pcb/placement.csv` 的坐标放。靠网格吸附会把它吸到 25 或 43，导致定位板孔对不上。

---

## 4. 分步操作流程

### 第 1 步：拿到 EPPad 工程

1. 打开 EPPad 项目页（立创开源硬件平台，搜索「EPPad」）
2. 点「克隆工程」把工程复制到自己账号
3. 在立创 EDA 编辑器里打开，或导出为 KiCad 格式

### 第 2 步：建新板并改外形

- 板外形改成 **98 × 50 mm**
- 右侧开缺口 **深 8 × 长 24 mm**，纵向位置对准拨杆（见 `docs/PCB设计规格书.md` §2）
- 板厚 1.6mm，2 层

### 第 3 步：照坐标表放轴体

打开 `pcb/placement.csv`，逐行放 14 个轴体：

```
ref,type,label,matrix,x_mm,y_mm,x_kicad,y_kicad,rotation,note
SW1,switch,PERM,ROW1xCOL1,7.00,7.00,7.00,43.00,0,PERM
...
SW12,switch,SPACE,ROW3xCOL1,40.00,43.00,40.00,7.00,0,SPACE（2/3 并联）
...
```

**注意**：CSV 给了两套坐标
- `x_mm / y_mm` —— 本设计坐标系（板左下角为原点，Y 向上）
- `x_kicad / y_kicad` —— KiCad 坐标系（Y 向下），`y_kicad = 50 − y_mm`

**放之前先确认你的 KiCad 原点设在哪**，别混用。

### 第 4 步：放二极管

14 个 1N4148（0805 贴片）。方向**必须**：**阳极接列线、阴极接行线**（`col2row`）。

> 接反了不会烧，但矩阵读不出来 —— 排查很痛苦，建议放之前先在纸上画一遍。

### 第 5 步：移植主控电路

从 EPPad 复制：主控封装（NoLogo ProMicro / nice!nano 引脚兼容）、电池接口、电源开关、复位按钮。
**但有三处必须改：**

1. **把热插拔轴座换成直焊焊盘**（见 §3.1）
2. **主控放到 PCB 背面**（下表面）—— 正面被 14 个轴体占满，放不下
   （见 `docs/PCB设计规格书.md` §14）。位置 (79.70, 8.50)，USB-C 朝右壁
3. **电池改到 PCB 背面左侧**（贴着左壁），与主控平面错开

> ⚠️ 主控在背面意味着**顶层的天线投影区禁铺铜** —— 和 EPPad 默认的顶层天线净空规则相反，照抄会削弱蓝牙。

### 第 6 步：接矩阵

按本项目的 `pcb/wiring.svg` 接：

| 网络 | 引脚 |
|---|---|
| 行 ROW1 / ROW2 / ROW3 | D4 / D5 / D6 |
| 列 COL1–COL5 | D7 / D8 / D9 / D10 / D16 |
| COL6（拨杆） | D14 |

**大键并联**（关键）：
- 回车 2 轴 → 同一矩阵点 **ROW2 × COL4**
- 空格 3 轴 → 同一矩阵点 **ROW3 × COL1**

### 第 7 步：布线

- 信号线 **0.25 mm**，电源 **0.5 mm**
- 2 层，背面铺地
- 天线区域（主控在 **PCB 背面**，其天线在底层）**禁止铺铜**

### 第 8 步：DRC → 出 gerber → 打样

对照 §6 清单人工确认后，导出 gerber 送嘉立创。

---

## 5. 坐标数据

`pcb/placement.csv` 由 `tools/gen_pcb.py` 从 `cad/lib/params.scad` 生成，
**改尺寸后重跑一次即可同步**：

```bash
python tools/gen_pcb.py
```

14 个轴体的完整坐标见该文件。核心规律：

| 行 | 轴体 x 坐标 | y |
|---|---|---|
| 第 1 行 | 13, 31, 49, 67, 85 | 7 |
| 第 2 行 | 13, 31, 49, 67, 85 | 25 |
| 第 3 行 | 13, **40**, 67（空格）+ 85（语音） | 43 |

**网格线是 13/31/49/67/85，第 3 行的 40 是唯一离格值。**
（这组坐标随 PCB 加宽 86→98 整体 +6mm；权威来源是 `pcb/placement.csv`。）

---

## 6. 打板前验证清单

- [ ] 轴体坐标与 `pcb/placement.csv` **逐行一致**
- [ ] 空格 3 轴确认**并联到同一矩阵点** ROW3 × COL1
- [ ] 回车 2 轴确认并联到 ROW2 × COL4
- [ ] 二极管方向：**阳极接列、阴极接行**
- [ ] 拨杆接到 ROW1 × COL6
- [ ] 板形 98 × 50，缺口 8 × 24 **对准拨杆位置**
- [ ] 热插拔轴座**已全部换成直焊焊盘**
- [ ] 主控天线下方（**底层**）**未铺铜**
- [ ] KiCad DRC **无错误**
- [ ] 与 `docs/PCB设计规格书.md` §11 清单对照

---

## 7. 许可证与合规（重要）

**EPPad 采用 GPL 3.0。** 这意味着：

| 义务 | 说明 |
|---|---|
| **衍生作品必须同样以 GPL 3.0 开源** | 本项目当前**没有 LICENSE**，基于 EPPad 改板后需加上 GPL 3.0 |
| **保留原作者署名** | PCB 文件里注明「基于 HAVIS 的 EPPad 修改」 |
| **提供源文件** | 打样时需同时公开 KiCad 源文件，不能只给 gerber |

> 立创开源硬件平台的声明：项目仅供学习交流，**不包括商业性使用**。
> 如果以后要商业化，需要联系原作者授权。

**建议**：既然本项目已经在 GitHub 开源，加个 GPL 3.0 是一致的做法。
我可以帮你加 LICENSE 并写好署名说明。

---

## 8. 本方案的边界

**包含**：底板选型、复用/重做清单、冲突分析、操作流程、坐标数据、验证清单。

**不包含**：
- ❌ **改好的 PCB 文件** —— 需要在 KiCad / 立创 EDA 里实际操作
- ❌ **EPPad 的源文件** —— 需你从平台克隆获取（有版权，我不代为分发）
- ❌ **实际打样验证** —— 尚未执行

**未验证**：本方案基于对 EPPad 公开资料的阅读，**未实际下载其工程验证**。
§3.1 的热插拔冲突是理论计算（`PCB_STANDOFF_H` 5.0 vs 电池 4.6），
拿到实物后可复核。

---

## 附：一页速查

```
【底板】EPPad（oshwhub / HAVIS / GPL 3.0）
【复用】nice!nano 电路 · 凯华矮轴封装 · 0805 二极管 · 结构做法
【重做】布局 · 板形 98×50+缺口 · 矩阵 3×6 · 拨杆 · 固件

【★ 必改】热插拔 → 直焊
  轴座下方凸出 2.5–3.0mm，该层只有 5.0mm，电池已占 4.6mm

【★ 别漏】空格中间轴 x=40 不在网格上 → 关网格吸附，照 CSV 放

【坐标】python tools/gen_pcb.py → pcb/placement.csv
【接线】见 pcb/wiring.svg
【合规】GPL 3.0，衍生作品必须同样开源 + 署名
```

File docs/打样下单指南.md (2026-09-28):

# ClaudePad 打样下单指南（嘉立创 JLC）

> 打样文件已打包：`pcb/fabrication/claudepad-jlc.zip`（Gerber 7 层 + 钻孔 + IPC-D-356 网表）
> 生成命令：`kicad-cli pcb export gerbers/drill/ipcd356`（2026-09-28，基于 DRC 全绿版板文件）

## 一、下单参数（嘉立创官网 → PCB 智能下单 → 上传 zip 后逐项核对）

| 参数 | 选什么 | 说明 |
|---|---|---|
| 板子尺寸 | 98 × 50 mm（自动识别） | 单板，**不拼板** |
| 板层数 | **2** | 双面板 |
| 板厚 | **1.6 mm** ★ | **凯华 datasheet 明确要求 1.6mm**（轴体引脚长度按此设计），选错轴体插不到底 |
| 数量 | 5 | 嘉立创最低起订量 |
| 阻焊颜色 | 任意（绿色最便宜） | |
| 丝印颜色 | 白色 | 阻焊选绿/红/蓝时配白字；选白油需配黑字 |
| 表面处理 | **有铅喷锡（HASL）** | 最便宜够用；预算充足可选沉金（插拔更顺滑） |
| 铜厚 | 1 oz（默认） | |
| 过孔处理 | **盖油（覆盖）** | 板上仅 2 个过孔，盖油防止意外短路 |
| 飞针/电测 | 可不选 | 已附带 IPC-D-356 网表（claudepad-d356a.txt），需要时再补 |
| 半孔/挖槽 | 无需特殊工艺 | 右下角缺口是普通板边开槽，不加钱 |

## 二、下单步骤

1. 打开 jlc.com → 注册/登录 → 首页「PCB 下单」
2. 把 `pcb/fabrication/claudepad-jlc.zip` 拖进上传框 → 系统自动解析尺寸/层数
3. 按上表逐项核对（尤其 **板厚 1.6mm**）
4. 付款下单（5 片学生价约 10~30 元，普通物流另计）

## 三、到货核对清单

- [ ] 板厚 1.6mm（卡尺量）
- [ ] 右下角缺口位置、深度 8mm 对（对照板上丝印）
- [ ] 14 个轴体孔位：每轴 2 小孔 + 1 中心大孔（下排最右、中排最右 2 轴无小定位孔——设计如此）
- [ ] 24 个主控排针孔两列对齐
- [ ] 走线无断路（可对照 `pcb/fabrication/claudepad-d356a.txt` 或 KiCad 3D 视图）

## 四、到货后返回项目继续

焊接 → 固件烧录 → 装壳。参考 `docs/新手采购清单.md` 的焊接章节。

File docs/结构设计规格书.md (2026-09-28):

# ClaudePad 结构设计规格书

**版本**：v0.4
**日期**：2026-09-20
**制造方式**：FDM 3D 打印（0.4mm 喷嘴）
**配套文件**：`cad/*.scad`（参数化模型）· `tools/*.py`（校验与导出）

> **v0.4 同步**：把本文档对齐到 `params.scad` 的实际值。此前有三轮改动只改了模型没改文档：
> 主控移到 **PCB 背面**（§1.3 / §3）、PCB 加宽 86 → **98mm**、轴体改用 **Choc V2**
> （键程 3.0 → **3.2mm**，键帽榫槽改成 MX 十字）。
> 整机高度因此从 23.10 变为 **23.30mm**，PCB 尺寸从 86×50 变为 **98×50**。
>
> **v0.3 重要修正**：v0.1–v0.2 的键帽间隙是 0.3mm，导致**按键根本按不动**
> （键帽裙边比定位板轴孔宽，下压时直接撞板）。已改为按轴体键程推导，
> 整机高度 20.1 → 23.1mm。详见 §1.3 与 `docs/按键行程图.png`。
>
> **v0.2 修正**：内腔高度写死导致轴体够不到 PCB、定位板宽度算错 12mm。
>
> 现在垂直方向的尺寸**全部由零件堆叠推导**，不再有写死的数值。

---

## 0. 快速导航

| 你想做的事 | 看哪节 |
|---|---|
| **先打个件验证尺寸** | §9 → 打 `00_test_coupon.stl` |
| 知道整机多大 | §1 |
| 知道每样东西装在哪 | §3 |
| 知道孔要开多大 | §6 |
| 知道怎么装起来 | §8 |
| 卡住了怎么办 | §11 |

---

## 1. 总体尺寸

### 1.1 整机外形

| 项目 | 尺寸 |
|---|---|
| **长（X，列方向）** | **107.10 mm** |
| **宽（Y，行方向）** | **71.10 mm** |
| **高（Z，桌面到键帽顶）** | **23.30 mm** |
| 底座本体高 | 14.80 mm |
| 重量（预估） | 约 140–170 g |

**作为参照**：标准 104 键键盘宽约 440mm，ClaudePad 只有它的 1/4。

### 1.2 垂直尺寸链（关键）

```
z = 23.30  ┌─────────────────┐  键帽顶面
           │    键帽 5.0     │
z = 18.30  ├─────────────────┤  键帽底面（离定位板 3.5）
           │  行程空间 3.5    │  ★ 必须 ≥ 轴体键程 3.2
z = 14.80  ├═════════════════┤  定位板上表面
           │   定位板 1.2    │
z = 13.60  ├─────────────────┤  定位板下表面 ◄─ 轴体卡扣在此
           │  轴体卡扣 5.0    │  ★ 待实物确认
z =  8.60  ├─────────────────┤  PCB 上表面（轴体焊接面）
           │     PCB 1.6     │
z =  7.00  ├─────────────────┤  PCB 下表面
           │ 主控/电池 5.0    │  ← 主控 3.2（贴板背面）+ 电池 4.0 + 胶 0.6
z =  2.00  ├─────────────────┤  底板上表面
           │    底板 2.0     │
z =  0.00  └─────────────────┘  桌面（含 0.2 倒角）
```

**内腔净高 = 5.0（电池/走线）+ 1.6（PCB）+ 5.0（轴体卡扣）= 11.6mm**

> ⚠️ 这个 11.6 是**算出来的**，不是拍的。改任何一个零件尺寸，它自动跟着变。
> 改参数后跑 `python tools/check_dims.py`，会校验整条链是否还自洽。

### 1.3 两个必须知道的耦合关系

**耦合 1：PCB 下方层高同时决定电池与主控**

主控**装在 PCB 背面**（v0.4 起），与电池共用 PCB 下方这 5.0mm。两者平面**不重叠**
（电池贴内腔左壁、主控贴右侧），但层高必须同时容下最厚的那个：

| 占用 | 高度 |
|---|---|
| 电池 4.0 + 双面泡棉胶 0.6 | **4.6 mm** ← 决定层高 |
| 主控 3.2（贴 PCB 背面，元件面朝下） | 3.2 mm（余 1.8） |

所以 `PCB_STANDOFF_H = 5.0` 是**电池**定的，不是主控。想改薄键盘，先确认电池装得下。

> **v0.4 之前**：主控装在 PCB **正面**，与轴体争板面 —— 14 个轴体几乎占满板面，
> 穷举后「零重叠位置数 = 0」。移到背面后这条约束消失，`SWITCH_PLATE_GAP`
> 不再兼任「主控净空」，只由**轴体卡扣位置**决定。详见 `docs/PCB设计规格书.md` §14。

**耦合 2：键帽间隙必须 ≥ 轴体键程**（v0.3 修正的 bug）

键帽裙边 **17.6mm** 比定位板轴孔 **13.8mm** 宽，**塞不进孔里**。所以键帽只能整体悬在定位板上方，
下压时裙边会直接撞到板面。

```
键帽底面离定位板 ≥ 轴体键程
CAP_GAP (3.5) ≥ SWITCH_TRAVEL (3.2)   ✅
```

> **v0.1–v0.2 的 `CAP_GAP = 0.3mm` 是错的** —— 按键只能按下 0.3mm 就顶死，剩余行程全废，
> **按键根本按不动**。修正后整机从 20.1mm 变成 23.1mm，这 3mm 是物理上必须的。
> v0.4 换 Choc V2 后键程 3.0 → 3.2，整机再涨到 23.3mm。
> 详见 `docs/按键行程图.png`。

---

## 2. 零件清单

| 编号 | 零件 | 文件 | 材料 | 填充 | 耗时 |
|---|---|---|---|---|---|
| 00 | **校准试件** | `00_test_coupon.stl` | PLA | 20% | 15 min |
| 01 | 底座 | `01_case_bottom.stl` | PETG | 25% | 3–4 h |
| 02 | 定位板 | `02_plate.stl` | PLA | 40% | 40 min |
| 03 | 键帽 1u × **9** | `03_keycap_1u.stl` | PLA | 15% | 12 min/个 |
| 04 | 键帽 2u（回车） | `04_keycap_2u.stl` | PLA | 15% | 20 min |
| 05 | 键帽 4u（空格） | `05_keycap_4u.stl` | PLA | 15% | 35 min |

**为什么底座用 PETG、定位板用 PLA**：底座要承受反复插拔 USB 和拨杆拨动，PETG 韧性更好；定位板只需要卡住轴体，PLA 刚性高、打印精度好。

---

## 3. 内部布局

### 3.1 俯视分区

下图是**去掉定位板后**的俯视示意（主控和电池都在 PCB **下表面**那一层，左右分开）：

```
        ┌───────────────────────────────────────────────┐
        │ [柱]                              [柱]        │
        │                                               │
        │  ┌────────────┐            ┌──────────────┐   │
        │  │            │            │  NoLogo      │   │
        │  │  电池仓     │            │  主控        │───┼─→ USB-C 开孔
        │  │  30 × 40   │            │  17.78 × 33  │   │    （右壁）
        │  │  （贴左壁）  │            │  （贴右壁）   │   │
        │  └────────────┘            └──────────────┘   │
        │ [柱]                              [柱]        │
        │                                               │
        │  ←─── 走线通道 A（沿下缘）────→                 │
        └───────────────────────────────────────────────┘
          右壁外侧：审批拨杆凸台（外凸 4.1mm）
```

> **为什么左右分开**：两者同处 PCB 下方这一层（只有 5.0mm）。电池 40mm 长、主控 33mm 长，
> 内腔宽度装不下并排两个，所以电池贴左壁、主控贴右壁，靠 X 方向错开。
> 支撑台因此只能取 x = 40 / 76 这两个轴体间隙中心（x = 22 被电池占、x = 94 不存在）。

### 3.2 各部件安装位置与固定方式

| 部件 | 位置 | 固定方式 | 可拆 |
|---|---|---|---|
| **定位板** | 内腔顶部，与外壳上沿**齐平** | 4 颗 M2×6 螺丝，穿过定位板拧入四角螺丝柱 | ✅ |
| **PCB** | 内腔中部，托在 4 个矮支撑台上 | 靠轴体 + 定位板压住（不需螺丝） | ✅ |
| **NoLogo ProMicro 主控** | **PCB 背面（下表面）右侧** | **必须直接焊在 PCB 上**（不能用普通排母，高度不够） | ❌ |
| **锂电池** | **PCB 正下方，贴内腔左壁** | 双面泡棉胶贴底 + 限位挡墙 | ✅ |
| **SPDT 拨杆** | 右壁外侧凸台 | 轴套穿过 φ6.2 孔，**外侧**拧螺母锁紧（拨杆+轴套+螺母在壳外，开关本体在壳内） | ✅ |
| **脚垫 × 4** | 底面四角沉孔 | 硅胶脚垫压入 | — |

### 3.3 为什么这样分区

| 决策 | 理由 |
|---|---|
| **电池走 PCB 正下方** | 内腔平面只有 102×66，电池 30×40 无法与 PCB（98×50）并排放置；且电池放最下层，远离主控发热 |
| **主控靠右** | USB-C 开孔开在右壁上，主控越靠右开孔越浅越好做 |
| **主控必须直焊** | 这层只有 5.0mm 高，普通排母（8.5mm）根本放不下。这是"薄"换来的代价 |
| **拨杆在右壁** | 拇指自然落点；信号线沿右壁竖直走，路径最短 |
| **定位板与上沿齐平** | 视觉整洁，且定位板被内腔四壁框住，不会横向晃动 |

---

## 4. 走线通道

### 4.1 两条主干道

| 通道 | 路径 | 走什么线 |
|---|---|---|
| **A** | 沿下缘横向 | 键位矩阵行线（3 条）+ 列线（5 条） |
| **B** | 沿右缘纵向 | 拨杆信号线（2 条）+ 地线 |

规格：槽宽 3.0 × 深 2.0mm，从底板上表面下挖。

### 4.2 走线规则

1. **所有飞线走 PCB 下方**（PCB 抬高 5.0mm 的这层），PCB 上方只允许轴体引脚和主控。
2. 走线槽转角做圆角，防割线皮。
3. 线径上限 2.2mm（30AWG 硅胶线约 0.8mm，余量充裕）。
4. 每根线两端留 5–8mm 余量，方便拆装。

---

## 5. 散热与间隙

### 5.1 发热源

| 部件 | 发热 | 处理 |
|---|---|---|
| NoLogo ProMicro（nRF52840） | 中（BLE 脉冲） | 正下方（底板上）开 6 个 φ4 通气孔形成对流 |
| 充电 IC | 中（充电时） | 同上 |
| 电池 | 不发热但**怕热** | 与主控同在 PCB 下方这一层，但**平面错开到两侧**，互不叠加 |

### 5.2 间隙要求

| 位置 | 最小间隙 |
|---|---|
| 元器件 ↔ 元器件 | 0.5 mm |
| 主控 ↔ 底板 | 0.3 mm（当前实际 **1.8mm**，主控 3.2 贴 PCB 背面，下方余 1.8） |
| 走线槽 ↔ 元器件 | 1.0 mm |
| 电池 ↔ PCB | 由 PCB_STANDOFF_H 保证（胶 0.6 + 电池 4.0 = 4.6 ≤ 5.0） |

### 5.3 通气孔

**3×2 共 6 个 φ4 孔**，开在底板上、跟随主控位置（因此随主控一起移到了右侧）。
作用：主控与充电 IC 的散热对流。

> v0.4 之前主控在 PCB 正面，通气孔在电池上方，兼有「电池鼓包泄压」的作用；
> 现在电池已让位到左壁、通气孔跟着主控到了右侧，**泄压作用不再成立**。

---

## 6. 公差总表（3D 打印直接照用）

FDM 打印的孔会比设计值小，所以孔一律放大。

| 部位 | 设计值 | 打印应设 | 说明 |
|---|---|---|---|
| **轴体开孔** | 13.80 | **13.90 ~ 13.95** | **最关键**。过紧装不进，过松轴体晃 |
| M2 自攻底孔 | 1.70 | **1.70** | PLA 可直接拧自攻螺丝 |
| M2 通孔 | 2.00 | **2.30** | 定位板过孔 |
| 拨杆轴套孔 | 6.00 | **6.20** | 要螺纹咬合，宁紧勿松 |
| 拨杆运动槽 | 4.50 | **4.70** | 要能自由拨动 |
| USB-C 开孔 | 9.0×3.6 | **9.4×4.4** | **宁大勿小** |
| 定位板 ↔ 内腔 | — | 单边 **+0.15** | 落入式配合 |
| 电池仓 | — | 单边 **+1.00** | 电池实物误差大 |
| 键帽外宽 | 17.60 | **17.60** | = 间距 − 0.4，防相邻摩擦 |
| 键帽榫槽宽 | 1.30 | **1.30** | **MX 十字**筋厚 ~1.2，留 0.1 松配（V1 小十字是 0.95） |
| 键帽十字臂长 | 4.00 | **4.00** | MX 标准（V1 小十字只有 1.20） |
| 底部倒角 | — | **0.2×45°** | 防首层大象脚卡死 |

**孔轴线平行热床**（孔径最准），所有零件**不需要支撑**。

### 6.1 CSG 融合重叠（建模规则，不是打印公差）

所有「贴附在母体表面」的凸起（螺丝柱 / PCB 支撑台 / 电池挡墙 / 拨杆凸台）在建模时都**往母体里多伸 0.5mm**（`FUSE_OVERLAP`）。

**为什么**：如果两个实体的面完全共面，布尔并集后会产生**非流形边** —— STL 不水密，切片软件可能报错或产生薄壁。

这个问题是在**真实渲染验证**中发现的：第一版底座 STL 有 64 / 11300 条边不是恰好被 2 个面共用。加上 0.5mm 重叠后完全水密。

> 校验方法：`python tools/verify_stl.py` —— 它会检查每个 STL 的水密性与包围盒尺寸。

### 6.2 已通过的真实渲染验证

6 个零件全部导出 STL 并校验通过：

| 零件 | 实测包围盒 | 偏差 |
|---|---|---|
| 底座 | 111.20 × 71.10 × 14.60 mm | 0.00 |
| 定位板 | 102.00 × 66.00 × 1.20 mm | 0.00 |
| 键帽 1u | 17.60 × 17.60 × 5.00 mm | 0.00 |
| 键帽 2u | 35.60 × 17.60 × 5.00 mm | 0.00 |
| 键帽 4u | 71.60 × 17.60 × 5.00 mm | 0.00 |

> 底座 X 含壳外拨杆凸台（+4.10mm），Z 少底部防大象脚倒角（−0.20mm），均为设计值。

---

## 7. 打印参数

| 参数 | 底座 | 定位板 | 键帽 |
|---|---|---|---|
| 材料 | PETG | PLA | PLA |
| 层高 | 0.20 mm | **0.16 mm** | 0.12 mm |
| 壁数 | 3 | 3 | 3 |
| 填充 | 25% | 40% | 15% |
| 支撑 | 不需要 | 不需要 | 不需要 |
| 打印方向 | 底面朝下 | 平放 | **顶面朝下倒扣** |

> **定位板层高为什么是 0.16**：板厚只有 1.2mm，用 0.2 层高只有 6 层，太粗糙；0.16 有 7.5 层，尺寸更准。

---

## 8. 装配顺序

```
第 1 步  主控焊到 PCB
        └─ NoLogo ProMicro 直接焊在 PCB **背面**（不用排母！高度不够）
        └─ 引脚朝上穿过 PCB，焊在正面
        └─ 焊二极管（矩阵防鬼影）

第 2 步  定位板装轴体
        └─ 从定位板正面按入 11 个轴
        └─ 空格位装 3 个轴（左中右），回车位装 2 个
        └─ ⚠️ 装前先试插 1 个，确认松紧

第 3 步  焊接
        └─ 定位板 + 轴体翻转，对齐 PCB 引脚，逐个焊
        └─ 焊拨杆引线（留 8mm 余量）
        └─ 🔌 先接 USB 测一遍：所有键是否响应、拨杆是否识别
        └─ ⚠️ 这一步别跳过，焊完再拆开查线最痛苦

第 4 步  装进底座
        └─ 定位板+PCB 组合体放入内腔，对准四角螺丝柱
        └─ 4 颗 M2×6 螺丝**对角交替**拧紧（别一次拧死）

第 5 步  电池
        └─ 电池背面贴双面泡棉胶
        └─ 塞入 PCB 下方**左侧**（主控在右侧，两边不叠；注意极性）
        └─ 走线沿通道 A 归拢

第 6 步  拨杆
        └─ SPDT 开关本体从右壁**内侧**对准轴套孔，轴套穿出壳外
        └─ **壳外**套垫片、拧螺母锁紧（螺母在凸台外侧，见 §11.2）
        └─ 拨动几次确认行程顺畅

第 7 步  收尾
        └─ 底面贴 4 个硅胶脚垫
        └─ 上键帽（注意 2u/4u 位置别装错）
        └─ 🎉 通电
```

---

## 9. 分步打印路线（强烈建议照做）

| 顺序 | 打什么 | 验证什么 | 耗时 |
|---|---|---|---|
| **①** | `00_test_coupon.stl` | **轴体卡扣间隙**（最关键） | 15 min |
| ② | `02_plate.stl` | 轴孔松紧、键帽能否挂住 | 40 min |
| ③ | `05_keycap_4u.stl` | 三轴支撑手感 | 35 min |
| ④ | `01_case_bottom.stl` | 孔位与装配 | 3–4 h |
| ⑤ | 全部 | — | — |

### 第 ① 步怎么用（最重要）

校准试件上有 **3 个测试位**，卡扣间隙分别是 **3.50 / 4.25 / 5.00mm**：

1. 拿一个**真实 Choc 轴体**，逐个插进去
2. 找那个「卡扣清脆扣入，且轴体塑料底面刚好贴住基座顶面」的位置
3. **判读**：
   - 轴体底面与基座之间有缝隙 → 该位间隙**偏大**
   - 卡扣扣不上，或扣上后底面顶住基座 → 该位间隙**偏小**
   - 完全贴合 + 卡扣清脆 → ✅ **就是它**
4. 把 `cad/lib/params.scad` 里的 `SWITCH_PLATE_GAP` 改成该值
5. 重跑校验和导出：
   ```bash
   python tools/check_dims.py
   python tools/export_stl.py
   ```

**为什么必须先做这步**：`SWITCH_PLATE_GAP` 是整套模型里**唯一无法从公开资料确定**的尺寸。Choc 官方未公开定位板高度，社区实测在 3.5–6.0mm 之间浮动。花 15 分钟测准，比打完 4 小时外壳才发现按不动划算得多。

**如果三个测试位都不合适**：改 `test_coupon.scad` 里的 `GAPS` 数组，重打一次（15 分钟）。

---

## 10. 需要额外采购的结构件

| 物品 | 规格 | 数量 | 用途 |
|---|---|---|---|
| M2 × 6mm 自攻螺丝 | 十字盘头 | 4 | 固定定位板 |
| 硅胶脚垫 | φ8mm，背胶 | 4 | 底面防滑 |
| 双面泡棉胶 | 0.6mm 厚 | 1 片 | 固定电池 |
| SPDT 拨动开关 | 轴套 φ6、长 **≥9mm** | 1 | 审批拨杆 |

> 螺丝多备 1.5 倍，极易丢。

---

## 11. 常见问题与对策

### 11.1 打印类

| 问题 | 对策 |
|---|---|
| 轴孔装不进 | `params.scad` 里 `SWITCH_CUTOUT_TOL` 从 0.10 调到 0.20 |
| 轴体装进去晃 | 调到 0.05 |
| 键帽榫槽太紧 | `CAP_STEM_GAP` 调到 1.05 |
| 键帽榫槽太松 | 调到 0.90 |
| 底部装不进底座 | 确认底部 0.2×45° 倒角已生效 |
| 定位板卡在内腔里 | 调大 `CASE_TOP_TOL`，或砂纸修定位板四边 |
| 空格按两端翘 | 确认空格装了 3 个轴（不是 1 个） |

### 11.2 拨杆选型注意

**必须买 SPDT 拨动开关**（拨过去停住的），不是自复位按钮。

**安装方向**：拨杆 + 轴套 + 螺母在**壳外**，开关本体在**壳内**。所以壳壁上只需要一个轴套过孔，**不需要拨杆行程槽**（拨杆在壳外摆动，不干涉壳体）。

默认按这个规格建模：

| 参数 | 值 | 参数名 |
|---|---|---|
| 轴套直径 | 6.0 mm | `SW_BUSH_D` |
| 轴套长度 | **≥ 9.0 mm** | `SW_BUSH_H` |
| 螺母厚度 | 2.0 mm | `SW_NUT_T` |
| 凸台直径 | 12.0 mm | `SW_BOSS_D` |

**为什么轴套要 ≥9mm**：外壳壁 2.4mm + 凸台 4.1mm + 螺母 2.0mm = 8.5mm，还要留 0.5mm 余量。

**买回来先量**，对不上就改 `params.scad` 里对应的 `SW_*` 参数，然后重跑校验 —— `check_dims.py` 会检查：
- 轴套能否穿过 壁+凸台+螺母
- 凸台会不会穿出外壳上下表面
- PCB 缺口够不够让开开关本体

### 11.3 电池选型注意

PCB 下方净高 5.0mm，减去泡棉胶 0.6mm，**电池厚度上限 4.4mm**。

| 规格 | 是否合适 |
|---|---|
| 3.7V 400–500mAh，厚 ≤4.0mm，**带引线**（焊到主控 B+ / B− 焊盘） | ✅ 推荐 |
| 3.7V 500mAh，厚 5.0mm | ❌ 需改 `PCB_STANDOFF_H` 到 6.0（整机变厚 1mm） |
| 3.7V 1000mAh 以上 | ❌ 装不下 |

**务必带保护板**。买前量实际长宽厚，电池是「标称和实物差最多」的元件。

---

## 12. 如何修改模型

**所有尺寸都在 `cad/lib/params.scad` 一个文件里。** 改完必做：

```bash
python tools/check_dims.py        # 设计规则（26 项）
python tools/lint_scad.py         # 语法与符号
python tools/verify_geometry.py   # 孔位与对位
python tools/export_stl.py        # 重新导出（需装 OpenSCAD）
```

**常见修改**：

| 想做什么 | 改哪个参数 |
|---|---|
| 键距 18 → 19 | `PITCH` |
| 键盘更薄 | 减小 `PCB_STANDOFF_H`（但要先确认电池装得下） |
| 换更大的电池 | `PCB_STANDOFF_H` 调大 + `BATT_*` |
| 换拨杆开关 | `SW_*` 系列 |
| 轴孔松紧 | `SWITCH_CUTOUT_TOL` |
| 键帽高度 | `CAP_H` |

> 这些脚本会**直接从 params.scad 读参数**，所以不存在「改了参数但校验还用旧值」的问题。

---

## 13. 本规格书的边界

**包含**：结构几何、内部布局、公差、打印参数、装配顺序、设计规则校验。

**不包含**：
- ❌ **电路设计（原理图 / PCB 布局）**——只定义「PCB 装在哪、多大、要开什么缺口」
- ❌ **ZMK 固件配置**
- ❌ **上位机软件**
- ❌ **打印服务报价**

**前置假设**：
- 0.4mm 喷嘴 FDM 打印机
- 材料 PLA / PETG
- 你按 §9 分步验证，而不是一次打全套

---

## 附：一页速查

```
【尺寸】
  整机  107.10 × 71.10 × 23.30 mm
  内腔净高 11.6 = 主控/电池 5.0 + PCB 1.6 + 轴体卡扣 5.0
  定位板 102 × 66 × 1.2 mm ｜ PCB 98 × 50 × 1.6 mm

【两条不能违反的耦合】
  ① PCB 下方 5.0mm 要同时容下电池（胶 0.6 + 电池 4.0 = 4.6）和主控（3.2）
     两者平面错开到两侧（电池贴左壁、主控贴右壁），层高由【电池】决定
  ② 键帽间隙 ≥ 轴体键程 → 3.5 ≥ 3.2
     否则键帽裙边撞定位板，按键按不动

【最关键的 3 个公差】
  轴体开孔 13.80 → 打印设 13.90~13.95   ← 错了整机报废
  USB-C 开孔        → 宁大勿小 +0.4
  键帽榫槽 1.30     → MX 十字臂宽，太紧插不进，太松老掉

【打印参数】
  底座 PETG 0.20mm 25% ｜ 定位板 PLA 0.16mm 40% ｜ 键帽 PLA 0.12mm 15%
  全部不需要支撑 ｜ 键帽倒扣打

【装配 7 步】
  主控焊 PCB 背面 → 装轴 → 焊接+测试 → 装入底座拧螺丝 → 电池 → 拨杆 → 上键帽

【打印顺序】
  ① 校准试件（测轴体间隙，15min）
  ② 定位板 → ③ 4u 空格 → ④ 外壳

【唯一需要实测的参数】
  SWITCH_PLATE_GAP —— 用 00_test_coupon.stl 测出来再回填

【改参数后必跑】
  python tools/check_dims.py     # 26 项设计规则，能抓出行程/干涉/主控放置类错误
```

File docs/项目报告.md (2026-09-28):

# ClaudePad 项目报告

**报告日期**：2026-09-15（**2026-09-20 修订**：对齐到 params.scad 实际值 —— 主控改到 PCB 背面、PCB 加宽至 98mm、轴体改 Choc V2）
**项目代号**：ClaudePad
**当前阶段**：P1 技术验证收尾 → P2 原型机制造（**设计已冻结，等待制造**）
**仓库**：https://github.com/seek635/coding-keyboard

---

## 一、项目概览

### 1.1 一句话定位

一款**蓝牙（BLE）编程专用实体小键盘**，11 键 + 侧边审批拨杆，把 Claude Code 里最高频的操作从键盘组合键变成单手一按。

### 1.2 核心设计目标

> **键盘本身不改变 Claude Code 的任何行为。** 拨杆 OFF 时它就是一个普通键盘；拨杆 ON 时才介入。

这一条决定了整个产品的技术路线——不是"劫持"终端，而是通过**官方 hooks 接口**在用户明确授权时提供便利。

### 1.3 键位

```
┌──────────┬────┬──────┬────────┬────────┐
│ 访问等级  │ ↑  │ 模型  │ 命令行  │  停止   │
├────┬────┬────┴────┴────────┤        │
│ ←  │ ↓  │ →    │   回车 2u   │        │
├────┴────┴──────┴────┬───────┴────────┤
│      空格 4u        │      语音       │
└─────────────────────┴────────────────┘
                                    ╱ 审批拨杆（OFF / ON）
```

- **11 个物理键** + 1 个侧边拨杆
- 三行五列网格；**方向键保留传统十字排列**（最高优先级约束）
- 大键：空格跨 4 格、回车跨 2 格

### 1.4 整机参数

| 项 | 值 |
|---|---|
| 尺寸 | **107.10 × 71.10 × 23.30 mm**（X 向 111.20 含右侧拨杆凸台） |
| 主控 | NoLogo ProMicro NRF52840（**装在 PCB 背面**） |
| 轴体 | Kailh Choc **V2** 矮轴 35–40g，**共 14 个** |
| 供电 | 3.7V 锂电 400–500mAh（厚度 ≤4.0mm） |
| 固件 | ZMK（shield 配置） |
| 连接 | BLE HID over GATT |

---

## 二、任务计划与进度

### 2.1 路线图（P0–P4）

| 阶段 | 目标 | 状态 | 完成度 |
|---|---|---|---|
| **P0 产品定义** | 确认键位、交互、边界 | ✅ **已完成** | 100% |
| **P1 技术验证** | 打通 BLE HID + hooks 自动审批 | 🟡 **大部分完成** | 70% |
| **P2 原型机** | 实体原型，键位全部可用 | 🟡 **设计完成，未制造** | 55% |
| **P3 上位机** | 状态回写、配置界面 | ⚪ 未开始 | 10% |
| **P4 打磨** | 安全机制、日志、可编程键位 | ⚪ 未开始 | 0% |

**整体完成度约 50%**（设计与验证基本就绪，制造与联调未开始）。

> 说明：完成度为**粗略估计**，用于判断重心，非精确度量。判定依据是「可交付物是否就绪」——
> 设计与验证类工作已闭环，制造与实机联调尚未开始。

### 2.2 P1 技术验证明细

| 验证项 | 状态 | 证据 |
|---|---|---|
| hooks 能否读取外部状态并跳过审批 | ✅ **已验证** | 官方文档确认 + 31 个用例通过 |
| HTTP hook 延迟是否可接受 | ✅ **已验证** | 实测 15ms/次（command 模式 510ms 已弃用） |
| 失效安全（故障时是否误批） | ✅ **已验证** | 4 条失效路径全部退化为「正常询问」 |
| BLE HID 实机配对 | ⚪ **未验证** | 需硬件 |
| ZMK 固件实机烧录 | ⚪ **未验证** | 需硬件 + 工具链 |

### 2.3 P2 原型机明细

| 工作项 | 状态 | 说明 |
|---|---|---|
| 结构设计（3D 打印） | ✅ 完成 | 6 个 STL 已渲染验证 |
| 键位/手势定义 | ✅ 完成 | 11 键 + 7 种手势 |
| 固件配置编写 | ✅ 完成 | ⚠️ 未编译 |
| PCB 设计 | ✅ 完成 | ⚠️ 未打样 |
| 采购清单 | ✅ 完成 | 见第四章 |
| **实际制造** | ⚪ **未开始** | 打印 + 采购 + 焊接 |

---

## 三、模块进度明细

### 3.1 总览

| 模块 | 状态 | 代码/文件量 | 关键产出 |
|---|---|---|---|
| 产品定义 | ✅ | PRD 29KB | `docs/PRD.md` |
| 结构设计 | ✅ 已渲染验证 | 819 行 SCAD | 6 个 STL + 9 张预览图 |
| 固件 | ⚠️ 未编译 | 426 行 | ZMK shield 配置 |
| 宿主程序 | ✅ 协议层验证 | 1087 行 | 审批拨杆实现（6 个脚本） |
| PCB | ⚠️ 未打样 | 4 个文件 | 网表 + 接线图 |
| 工具链 | ✅ | 2751 行 | 14 个脚本 |
| 文档 | ✅ | 7 份 md | 见 3.3 |

**代码总量 5083 行**（cad + firmware + host + tools）。

### 3.2 结构设计

| 项 | 结果 |
|---|---|
| 零件数 | 6 个（底座 / 定位板 / 键帽 ×3 / 校准试件） |
| STL 校验 | **6/6 通过**（水密、包围盒零偏差） |
| 设计规则 | **26 项全部通过** |
| 几何对位 | **14 个轴孔 100% 对位** |

**垂直尺寸链**：

```
z = 23.30  ┌─────────────┐  键帽顶面
           │   键帽 5.0   │
z = 18.30  ├─────────────┤  键帽底面
           │  ★ 间隙 3.5  │  ← 必须 ≥ 键程 3.2
z = 14.80  ├═════════════┤  定位板上表面
           │  定位板 1.2  │
z = 13.60  ├─────────────┤  定位板底面
           │  轴体卡扣 5.0 │  ← 只走轴体引脚，主控已移到板背面
z =  8.60  ├─────────────┤  PCB 上表面
           │    PCB 1.6   │
z =  7.00  ├─────────────┤  PCB 下表面
           │ 主控/电池 5.0 │  ← 主控 3.2 贴背面 + 电池 4.0 + 胶 0.6
z =  2.00  ├─────────────┤  底板上表面
           │    底板 2.0   │
z =  0.00  └─────────────┘  桌面
```

### 3.3 文档产出

| 文档 | 大小 | 内容 |
|---|---|---|
| `PRD.md` | 28.8 KB | 产品需求、键位定义、手势表、HID 映射 |
| `结构设计规格书.md` | 18.4 KB | 尺寸链、公差、装配顺序、走线 |
| `采购清单.md` | 14.9 KB | BOM 与选型理由 |
| `PCB设计规格书.md` | 12.9 KB | 封装坐标、布局、打样参数 |
| `审批拨杆技术验证.md` | 12.4 KB | hooks 路线可行性报告 |
| `固件设计说明.md` | 10.0 KB | ZMK 设计原理与取舍 |
| `项目报告.md` | 15.1 KB | 本报告 |
| `按键行程图.svg/png` | — | 行程剖面图 |

---

## 四、材料清单（BOM）

> **不标具体价格**——电子件价差可达 3 倍，标了反而误导。以下给的是**规格要求**。

### 4.1 最小验证集（建议先买，8 项）

花最少的钱验证三件事：**BLE 能否连上** / **ZMK 能否自定义** / **拨杆能否被识别**。

| # | 物品 | 规格 | 数量 |
|---|---|---|---|
| 1 | NoLogo ProMicro NRF52840 主控 | nRF52840，Pro Micro 兼容，自带充电管理 | 1 |
| 2 | 锂电池 | 3.7V 300–500mAh，**JST 1.25** | 1 |
| 3 | Choc 矮轴 | 红轴轻力度 35–40g | 6 |
| 4 | Choc 1u 键帽 | 矮轴专用 | 6 |
| 5 | 拨动开关 | **SPDT 三脚**（非自复位） | 2 |
| 6 | 杜邦线 | 公母各一扎 | 2 |
| 7 | 面包板 | 400 孔 | 1 |
| 8 | USB-C 数据线 | **必须是数据线**，非纯充电线 | 1 |

### 4.2 完整原型清单

**电子部分**

| # | 物品 | 规格 | 数量 |
|---|---|---|---|
| 1 | NoLogo ProMicro NRF52840 | nRF52840 | 1 |
| 2 | 锂电池 | 3.7V 400–500mAh，**厚 ≤4.0mm**，带保护板 | 1 |
| 3 | **Choc 矮轴** | 红轴轻力度 | **17**（需 14，备 3） |
| 4 | ~~键帽~~ | — | **0**（自己打印） |
| 5 | SPDT 拨动开关 | 三脚，**轴套长 ≥9mm** | 2 |
| 6 | 二极管 | 1N4148 | 20 |
| 7 | 电源开关 | 小型拨动 | 1 |
| 8 | 复位按钮 | 轻触开关 | 2 |
| 9 | ~~排针/排母~~ | — | **0**（主控必须直焊） |
| 10 | 细导线 | 30AWG 硅胶线 | 1 卷 |
| 11 | WS2812 | RGB 灯珠 | 若干 |

**结构部分**（全部自己打印）

| # | 物品 | 对应文件 |
|---|---|---|
| 12 | 底座 | `01_case_bottom.stl` |
| 13 | 定位板 | `02_plate.stl` |
| 14 | 键帽 1u ×9 | `03_keycap_1u.stl` |
| 15 | 键帽 2u ×1 | `04_keycap_2u.stl` |
| 16 | 键帽 4u ×1 | `05_keycap_4u.stl` |
| 17 | 硅胶脚垫 φ8 | — |
| 18 | M2×6mm 自攻螺丝 ×6 | — |

### 4.3 工具（一次性投入，可复用）

可调温电烙铁 + 细尖头 · 焊锡丝 0.6mm · 助焊剂 · 吸锡带 · 防静电镊子 · 斜口钳 · 万用表（带通断）· 热缩管 · 防静电手环

### 4.4 成本构成（比例参考）

| 类别 | 占比 |
|---|---|
| 主控 + 电池 | 25–30% |
| 轴体 + 键帽 | 25–30% |
| 拨杆 + 元器件 | 5–10% |
| 结构件 | 10–15% |
| 工具 | 20–30%（一次性） |

### 4.5 三个必避的坑

| 坑 | 后果 |
|---|---|
| **USB-C 买成纯充电线** | 只有电源针，电脑不认设备，刷不了固件 |
| **拨杆买成 SPST（两脚）** | 做不出 OFF/ON 两态语义，审批功能失效 |
| **拨杆轴套长度 <9mm** | 壁 2.4 + 凸台 4.1 + 螺母 2.0 = 8.5mm，短了装不上 |

---

## 五、关键设计决策

### 5.1 键盘是无状态的

键盘收不到权限档位、模型名、审批状态。所以「长按复位到 default」「长按循环切换模型」**键盘做不了**——它不知道当前在哪一档。

**方案**：键盘只**发信号**（`Ctrl+Alt+Shift+F13`/`F14` 这种极难误触的组合），由读取终端状态栏的上位机执行真正的操作。

### 5.2 审批拨杆走 hooks，不走文本嗅探

| | 终端文本嗅探 | Hooks（采用） |
|---|---|---|
| 稳定性 | 匹配文案，**改文案就失效** | 官方接口，不依赖文案 |
| 能否分级 | 难结构化 | 直接拿到 `tool_name` + `tool_input` |
| 误判 | 天然会误判 | 结构化字段，无误判 |

**官方机制的关键一条**：

> `PreToolUse` 返回 `{"hookSpecificOutput":{"permissionDecision":"allow"}}` → 跳过权限提示
> **返回空（exit 0 无输出）→ 不算批准** → 走原生权限流程

这使「拨杆 OFF = 产品不存在」成立。

**两条铁律**：
1. **失效安全** —— 任何故障（进程没跑 / 令牌错 / 脚本异常）都退化为「正常询问」，绝不误批
2. **只升不降** —— hook 只返回 `allow`，从不返回 `ask`/`deny`

### 5.3 大键必须多轴支撑

| 方案 | 4u 空格 PLA 挠度 |
|---|---|
| 单轴支撑 | **1.59 mm**（明显翘） |
| **三轴并联** | **0.20 mm**（降 87.5%） |

回车 2u 用 2 轴，空格 4u 用 3 轴。**这不是可选项**，是数值证明的必需项。

### 5.4 键帽间隙必须 ≥ 键程

键帽裙边 **17.6mm** 比定位板轴孔 **13.8mm** 宽——**裙边塞不进孔里**，键帽只能悬在板上方。所以下压空间必须靠「键帽底面到定位板」的间隙提供：

```
CAP_GAP = SWITCH_TRAVEL(3.2) + 0.3 = 3.50 mm
```

写成 0.3mm 会让键盘**完全按不下去**。这一条是在审查渲染图时发现并修正的。

### 5.5 单一数据源

**所有尺寸只有一个来源：`cad/lib/params.scad`。** 校验脚本、PCB 网表、行程图、三维查看器全部解析它，不手抄。

---

## 六、验证证据

### 6.1 六项自动校验（当前全绿）

| # | 校验 | 结果 |
|---|---|---|
| 1 | SCAD 语法 + 跨文件符号 + 死代码 | ✅ 全部通过 |
| 2 | 结构设计规则 | ✅ **26 项全部通过** |
| 3 | 几何对位（孔位/对称/筋宽/键帽） | ✅ 全部通过 |
| 4 | STL 校验（包围盒/水密性/体积） | ✅ **6/6** 通过 |
| 5 | 固件 ↔ 结构 交叉校验 | ✅ 12 键位、矩阵 3×6 相符 |
| 6 | 审批 hook 逻辑 | ✅ **31 个用例**通过 |

### 6.2 关键实测数据

| 项 | 实测值 |
|---|---|
| 底座 STL 包围盒 | 111.20 × 71.10 × 14.60 mm（偏差 0.00） |
| 定位板 STL | 102.00 × 66.00 × 1.20 mm（偏差 0.00） |
| 键帽 STL | 17.60 / 35.60 / 71.60 × 17.60 × 5.00 mm |
| hook 延迟（HTTP） | **15 ms/次** |
| hook 延迟（command） | 510 ms/次（已弃用） |
| 4u 空格挠度 | 单轴 1.59mm → 三轴 0.20mm |

### 6.3 Choc V2 (PG1353) PCB 封装（凯华官方 datasheet 像素标定，2026-09-26 最终版）

| 特征 | 坐标 | 孔径 | 类型 |
|---|---|---|---|
| 电气引脚 1 | (−3.80, 4.93) | 1.20 | PTH，通电 |
| 电气引脚 2 | (−5.90, 0.00) | 1.20 | PTH，通电 |
| 不通电定位脚 | (5.15, −5.00) | 1.50 | NPTH |
| 轴芯中心孔 | (0, 0) | **5.0**（★ V2 加大，V1 是 3.429） | NPTH |
| LED 焊盘 | (5.15, 0) | — | 焊盘 |

> ⚠️ 社区开源库（siderakb 等）的三孔坐标是官方坐标的 **x/y 互换错版**，本项目已按
> 凯华官方 datasheet（CPG135301D01，2020-10-23 版）像素标定修正，两两间距 6/12.5/14
> 的实测无法区分这组镜像，坐标以官方图为准。

---

## 七、风险与未验证项

### 7.1 高优先级（阻塞制造）

| 风险 | 影响 | 应对 |
|---|---|---|
| ~~★ 主控在板面上放不下~~ | ✅ **已解决（2026-09-16）**：原板面 86×50 被 14 个轴体占满，17.8×33 的主控零重叠位置数为 0，与 4 个轴体重叠 322.52 mm² | 主控移到 **PCB 背面**、PCB 加宽到 98、支撑台改 40/76。详见 `docs/PCB设计规格书.md` §14 |
| **`SWITCH_PLATE_GAP` 未知** | Choc 官方未公开定位板高度，社区实测 3.5–6.0mm 浮动。取错会导致轴体装不上或主控放不下 | 已做**校准试件** `00_test_coupon.stl`（3 个测试位），**15 分钟打印即可实测** |

### 7.2 中优先级

| 风险 | 说明 |
|---|---|
| **固件未编译** | 本地无 Zephyr 工具链。语法依据官方文档逐条核对 + 静态校验，首次构建可能需微调 |
| **审批拨杆未真机验证** | 本机无 Claude Code CLI，验证在协议层完成。接入步骤见 `docs/审批拨杆技术验证.md` §7 |
| **PCB 未打样** | 封装坐标已交叉验证，但未生成实际 PCB 文件跑 DRC |

### 7.3 低优先级

| 风险 | 说明 |
|---|---|
| 拨杆型号差异 | 不同型号轴套尺寸可差 2mm。买回后量三个尺寸（轴套直径/长度/面板），对不上改 `params.scad` 的 `SW_*` 参数 |
| 打印公差 | 轴孔 13.80 → 打印需设 **13.90~13.95**。这是唯一错了就整机报废的尺寸 |

### 7.4 设计过程中发现并修复的严重问题

| 问题 | 后果 | 发现方式 |
|---|---|---|
| 键帽间隙写死 0.3mm | **键盘完全按不下去** | 用户看渲染图发现 |
| 内腔高度写死 9.0mm | 定位板抬高 4.2mm，轴体够不到 PCB | 自写脚本检查发现 |
| USB-C 开口方向错 | **USB 口插不进去** | 渲染右壁正视图发现 |
| PCB 支撑台顶住轴体塑料脚 | 装不进去 | 计算轴体空隙发现 |
| 底座 STL 非水密 | 切片软件报错 | STL 校验脚本发现 |

> **教训**：「零件之间不干涉」不等于「机构能动」。静态装配检查全过，但运动部件的行程没检查。
> 任何有相对运动的部件，都必须校验「它能否走完整个行程」。

---

## 八、下一步

### 8.1 推荐执行顺序

| 顺序 | 事项 | 耗时 | 为什么先做 |
|---|---|---|---|
| **1** | 打印校准试件，实测 `SWITCH_PLATE_GAP` | 15 min | **唯一阻塞项**，且决定后续所有尺寸 |
| **2** | 买最小验证集（8 项），验证 BLE + ZMK + 拨杆 | 1 周 | 花小钱试通，避免投错方向 |
| **3** | 打印定位板 → 键帽 → 外壳 | 半天 | 验证打印公差 |
| **4** | 焊接组装，做出第一台能用的原型 | 1 周 | — |
| **5** | 打样 PCB，替换手工布线 | 2 周 | 布局定稿后再投 |
| **6** | 接入 Claude Code 真机验证 hooks | 5 min | 报告 §7 有六步接入流程 |

### 8.2 立即可做的三件事

1. **改仓库可见性** —— 当前是**公开**，需改为私有（Settings → Danger Zone → Change visibility）
2. **决定许可证** —— 目前无 LICENSE
3. **打印校准试件** —— `cad/output/00_test_coupon.stl`，15 分钟

---

## 附录：项目文件结构

```
coding-keyboard/
├── README.md              项目首页
├── cad/                   参数化 3D 模型（819 行）
│   ├── lib/params.scad    ★ 所有尺寸的唯一来源
│   ├── output/*.stl       6 个已验证 STL
│   ├── output/preview/    9 张预览图
│   └── output/viewer.html 可交互三维查看器
├── firmware/              ZMK shield 配置（426 行）
├── host/                  审批拨杆实现（1087 行）
├── pcb/                   网表 + 接线图（json/md/svg/png）
├── tools/                 14 个校验与生成脚本（2751 行）
└── docs/                  7 份设计文档 + 行程图
```

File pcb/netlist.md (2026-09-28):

# ClaudePad PCB 网表

矩阵 **3 行 × 6 列**｜轴体 **14 个**（含大键并联）｜审批拨杆 **1 个**

> 本文件由 `tools/gen_pcb.py` 从 `cad/lib/params.scad` 自动生成，不要手改。

## 1. 引脚分配

| 信号 | 主控引脚（NoLogo ProMicro NRF52840 / nice!nano 兼容） | 说明 |
|---|---|---|
| ROW1 | **D4** | 行，输入（`ACTIVE_HIGH \| PULL_DOWN`） |
| ROW2 | **D5** | 行，输入（`ACTIVE_HIGH \| PULL_DOWN`） |
| ROW3 | **D6** | 行，输入（`ACTIVE_HIGH \| PULL_DOWN`） |
| COL1 | **D7** | 列，输出（`ACTIVE_HIGH`） |
| COL2 | **D8** | 列，输出（`ACTIVE_HIGH`） |
| COL3 | **D9** | 列，输出（`ACTIVE_HIGH`） |
| COL4 | **D10** | 列，输出（`ACTIVE_HIGH`） |
| COL5 | **D16** | 列，输出（`ACTIVE_HIGH`） |
| COL6 | **D14** | 列，输出（`ACTIVE_HIGH`） |
| RGB 数据 | D15 | WS2812 数据线 |

## 2. 二极管方向

`diode-direction = "col2row"`

**阳极接列线，阴极接行线（电流 列 → 行）**

即每个按键回路：**列线 → 二极管阳极 → 二极管阴极 → 轴体 → 行线**

> 接反不会烧，但矩阵读不出来。修正二选一：所有二极管掉头，或把固件 `diode-direction` 改成 `"row2col"`。

## 3. 按键接线对照表

| # | 按键 | 矩阵位置 | 行线 | 列线 | 轴体数 | 二极管 |
|---|---|---|---|---|---|---|
| 1 | **PERM** | 行1·列1 | ROW1(D4) | COL1(D7) | 1 | 1N4148 |
| 2 | **UP** | 行1·列2 | ROW1(D4) | COL2(D8) | 1 | 1N4148 |
| 3 | **MODEL** | 行1·列3 | ROW1(D4) | COL3(D9) | 1 | 1N4148 |
| 4 | **CMD** | 行1·列4 | ROW1(D4) | COL4(D10) | 1 | 1N4148 |
| 5 | **STOP** | 行1·列5 | ROW1(D4) | COL5(D16) | 1 | 1N4148 |
| 6 | **LEFT** | 行2·列1 | ROW2(D5) | COL1(D7) | 1 | 1N4148 |
| 7 | **DOWN** | 行2·列2 | ROW2(D5) | COL2(D8) | 1 | 1N4148 |
| 8 | **RIGHT** | 行2·列3 | ROW2(D5) | COL3(D9) | 1 | 1N4148 |
| 9 | **ENTER** | 行2·列4 | ROW2(D5) | COL4(D10) | 2 | 1N4148 |
| 10 | **SPACE** | 行3·列1 | ROW3(D6) | COL1(D7) | 3 | 1N4148 |
| 11 | **VOICE** | 行3·列5 | ROW3(D6) | COL5(D16) | 1 | 1N4148 |
| 12 | **APPROVE** | 行1·列6 | ROW1(D4) | COL6(D14) | 1 | 1N4148（建议） |

### 大键并联接法（重要）

**ENTER**（2u）—— 定位板开 2 个轴孔，**2 个轴体电气并联**到同一个矩阵交点 （ROW2 × COL4）：

```
  轴体① 引脚 → COL4 ｜ 轴体① 另一脚 → 二极管 → ROW2
  轴体② 引脚 → 与轴体① 同一条线（并联）
```

**SPACE**（4u）—— 定位板开 3 个轴孔，**3 个轴体电气并联**到同一个矩阵交点 （ROW3 × COL1）：

```
  轴体① 引脚 → COL1 ｜ 轴体① 另一脚 → 二极管 → ROW3
  轴体② 引脚 → 与轴体① 同一条线（并联）
  轴体③ 引脚 → 与轴体① 同一条线（并联）
```

> PCB：这几个轴体的焊盘用铜箔连到同一条行/列线。
> 手焊洞洞板：用一根导线把它们的引脚串起来。

## 4. Choc V2 (PG1353) 轴体 PCB 封装

原点 = 轴芯中心。**来源：凯华官方规格图**（PCB 板安装示意图）。

> ⚠️ 2026-09-21 修订：此前本节依据两个开源封装库（daprice / siderakb）「交叉验证」，但实物实测与该表不符 —— **两个库一起错了**。

| 特征 | 坐标 (x, y) mm | 孔径 mm | 数量 | 类型 |
|---|---|---|---|---|
| 金属电气脚 | (-3.80, 4.93) | 1.20 | 1 | 金属化（PTH），通电 |
| 金属电气脚 | (-5.90, 0.00) | 1.20 | 1 | 金属化（PTH），通电 |
| 不通电定位脚 | (5.15, -5.00) | 1.50 | 1 | 非金属化（NPTH），不导通 |
| 轴芯中心孔 | (0, 0) | 5.0 | 1 | 非金属化（NPTH） |
| LED 焊盘 | (5.15, 0.00) | — | 1 | 官方图标注 `LED` |

坐标来源：凯华官方 datasheet（CPG135301D01，2020-10-23 版）Recommended PCB Layout，
600dpi 矢量图像素标定，双尺寸交叉验证误差 0.1%（2026-09-26 落定）。
LED 焊盘中心 (5.15, 0.00)。
PCB 必须钻满 3 个孔，一个都不能省（定位脚孔 NPTH，不导通）。
★ 导通对已于 2026-09-26 经万用表实测确认（按下导通 = 电气脚对），坐标可用。

**外形**：官方图标注 15 × 15 × 5.3mm，底座外形 13.95 × 13.95。

## 5. 其他元件

| 元件 | 连接 |
|---|---|
| 审批拨杆 SPDT | 公共端 → ROW1；常开端 → COL6。**串一只 1N4148 防鬼影** |
| 电池 | 带引线的电池 → 主控 **B+ / B− 焊盘**（注意极性；该板不是 JST 插座） |
| 电源开关 | 串在电池正极与主控之间 |
| 复位按钮 | 并联到主控的 RST 焊盘（该板无板载复位按钮） |
| WS2812 | 数据线 → D15，电源接 3.3V/VCC，地接 GND |

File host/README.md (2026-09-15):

# ClaudePad 宿主程序

审批拨杆的宿主侧实现。**让键盘侧边拨杆真正能自动批准 Claude Code 的操作。**

设计依据与实测数据见 `docs/审批拨杆技术验证.md`。

---

## 它解决什么问题

Claude Code 跑长任务时会反复弹审批：「是否允许执行 rm」「是否允许写入配置」。
用户此时可能在做别的事，每次都要切回终端按回车。

把键盘拨杆拨到 ON，这些审批自动通过。拨回 OFF，恢复原样。

**拨杆 OFF 时，这个程序对 Claude Code 完全没有影响**——不改变任何既有行为。

---

## 目录

```
host/
├── claudepad_core.py       决策核心（危险命令识别 / 受保护路径 / 状态读写）
├── claudepad_daemon.py     ★ 常驻守护进程：HTTP hook 服务 + 键盘监听
├── claudepad_hook.py       command 模式 hook（降级方案）
├── switchctl.py            命令行控制（手动开关 / 状态 / 日志 / 守护模式）
├── install_hook.py         一键安装卸载 hook 配置
└── test_hook.py            测试台（31 个用例）
```

---

## 快速开始

### 1. 先跑测试（不需要键盘，不需要 Claude Code）

```bash
python test_hook.py
```

应该输出「31 个用例全部通过」。这一步验证审批逻辑本身是对的。

### 2. 安装 hook

```bash
python install_hook.py              # 预览要写入的配置（不改文件）
python install_hook.py --apply      # 确认后真正写入（自动备份原文件）
```

安装脚本会自动填好路径和访问令牌。**不要手改 `settings.json`**——路径里的反斜杠和空格最容易在这里出错。

### 3. 启动守护进程

```bash
python claudepad_daemon.py
```

保持运行。它会：
- 在 `127.0.0.1:8787` 提供 hook 应答服务
- 监听全局按键，捕捉键盘发来的 F13/F14

> 需要 `pynput` 才能监听键盘：`pip install pynput`
> 没装也能用，只是要手动控制拨杆。

### 4. 验证

```bash
python switchctl.py on     # 打开拨杆
# 回到 Claude Code，做一件需要授权的事 → 应该不再询问
python switchctl.py off    # 关掉，恢复询问
```

---

## 常用命令

```bash
python switchctl.py status      # 查看拨杆状态
python switchctl.py on          # 打开（模拟拨杆 ON）
python switchctl.py off         # 关闭
python switchctl.py toggle      # 切换
python switchctl.py watch       # 守护模式（不带 HTTP 服务）
python switchctl.py log 30      # 查看最近 30 条审批记录
python switchctl.py reset-log   # 清空日志
```

---

## 行为规则

拨杆 ON 时：

| 操作类型 | 行为 |
|---|---|
| 读文件（`Read` / `Glob` / `Grep`） | ✅ 自动批准 |
| 编辑/新建文件（`Edit` / `Write`） | ✅ 自动批准 |
| 常规命令（`ls` / `git status` / `npm test`） | ✅ 自动批准 |
| 联网（`WebFetch` / `WebSearch`） | ✅ 自动批准 |
| **危险命令** | ⚠️ **不自动批准**，交回原生流程询问 |
| **写受保护路径** | ⚠️ **不自动批准** |
| **`AskUserQuestion`** | ⚠️ **永不代答**（需要用户本人判断） |

### 被拦截的危险命令

删除类：`rm -rf`、`rm -r`、`rmdir`、`del /s`、`rd /s`、`Remove-Item -Recurse`
权限类：`sudo`、`runas`、`chmod 777`、`chown`
磁盘系统：`dd`、`mkfs`、`format`、写 `/dev/sd*`、`shutdown`、`reboot`
Git 破坏性：`git push --force`、`git push -f`、`git reset --hard`、`git clean -f`
远程执行：`curl | sh`、`wget | bash`
其他：`kill -9`、fork bomb、`npm publish`

### 受保护路径

`/etc/`、`/usr/`、`/bin/`、`/boot/`、`C:\Windows`、`C:\Program Files`、
`~/.ssh/`、`~/.aws/`、`~/.gnupg/`、`~/.bashrc`、`~/.zshrc`、
`~/.claude/settings.json`（防止自我修改配置）、`.git/config`

> 想调整规则？改 `claudepad_core.py` 里的 `DANGEROUS_CMD_PATTERNS` 和
> `PROTECTED_PATH_PATTERNS`，然后重跑 `test_hook.py`。

---

## 为什么用 HTTP 模式而不是 command 模式

hooks 支持两种执行方式，实测延迟差 34 倍：

| 模式 | 延迟 | 说明 |
|---|---|---|
| `command` | **510 ms/次** | 每次工具调用起一个 Python 进程 |
| `http` | **15 ms/次** | 常驻进程直接应答 |

`command` 模式下每个工具调用都多等半秒，不可接受。所以默认装 HTTP 模式。

如果不想常驻进程，可以装 command 模式：

```bash
python install_hook.py --mode command --apply
```

逻辑完全一样（共用 `claudepad_core.py`），只是慢。

---

## 安全设计

### 失效安全：任何故障都退化为「正常询问」

| 故障 | 结果 |
|---|---|
| 守护进程没跑 | 连接失败 → **正常询问** |
| 访问令牌不匹配 | HTTP 403 → **正常询问** |
| hook 脚本异常 | 返回空 → **正常询问** |
| 输入 JSON 损坏 | 返回空 → **正常询问** |
| 状态文件丢失 | 视为拨杆 OFF → **正常询问** |

**绝不会出现「因为程序 bug 而全部自动批准」。**

### 只升不降

hook 只返回 `allow`，从不返回 `ask` 或 `deny`。

危险命令一律**静默放行**给 Claude Code 原生流程判断，而不是强制弹窗。

好处：不会出现「本来在 `acceptEdits` 模式，因为拨杆 ON 反而被强制弹窗」这种反直觉行为。

### 访问令牌

守护进程监听在 `127.0.0.1`，理论上本机任何程序都能调它。所以加了令牌校验：
令牌存在 `~/.claudepad/token`，由安装脚本写进 hook 配置的请求头。
令牌不对直接 403，Claude Code 会退化为正常询问。

### 审计日志

所有决策记录在 `~/.claudepad/approvals.jsonl`：

```
✅ 2026-09-14T19:40:12  Bash      allow   常规 shell 命令              git status
⏭️ 2026-09-14T19:40:15  Bash      skipped 危险命令特征: rm -rf          rm -rf /tmp/x
```

用 `python switchctl.py log` 查看。

---

## 卸载

```bash
python install_hook.py --uninstall --apply
```

会把 ClaudePad 的条目从 `settings.json` 移除，**保留你其他所有 hook 和设置**。

---

## 故障排查

| 现象 | 原因 | 处理 |
|---|---|---|
| 拨杆 ON 但仍弹审批 | 守护进程没跑 | 检查守护进程是否在运行 |
| 同上 | hook 没装上 | `python install_hook.py` 看预览，再 `--apply` |
| 同上 | 令牌不匹配 | 重跑 `install_hook.py --apply` 重新写入令牌 |
| 危险命令被拦下了 | **这是设计如此** | 危险命令不自动批，属预期行为 |
| 守护进程起不来 | 端口被占 | `--port 8788` 换端口，同时重装 hook 指定同一端口 |
| 键盘拨杆无反应 | 没装 pynput | `pip install pynput` |
| 键盘拨杆无反应 | F13 被拦截 | 换 F14/F15（改固件 + `claudepad_daemon.py` 的 `VK_F13`） |

---

## 关于「未在真实 Claude Code 上跑通」

本机没有安装 Claude Code CLI，所以验证是在**协议层**完成的：按官方文档构造 hook 的
输入 JSON、检查脚本的输出、验证失效路径。逻辑和协议格式都已确认，但
「Claude Code 真的会按文档所述处理这个响应」这一步没有实测。

接入真机后按上面的「快速开始」走一遍，第 4 步「不再询问」即验证通过。

详见 `docs/审批拨杆技术验证.md` §7。

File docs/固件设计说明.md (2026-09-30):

# ClaudePad 固件设计说明

**版本**：v0.1
**日期**：2026-09-14
**固件框架**：ZMK
**配套文件**：`firmware/config/boards/shields/claudepad/*`

---

## 0. 这份文档解决什么

`firmware/README.md` 讲**怎么用**，本文讲**为什么这么设计**——尤其是几个必须做取舍的地方。

---

## 1. 核心约束：键盘是「无状态」的

这是整个固件设计里最重要的一条认知，它决定了哪些功能能做、哪些必须交给上位机。

**键盘只能发按键，收不到任何状态。** 它不知道：

- 当前 Claude Code 处于哪个权限档位（plan / default / acceptEdits / auto）
- 当前用的是哪个模型（Opus / Sonnet）
- 是否有审批弹窗正在等待

所以 PRD 里那些「听起来键盘自己能做」的操作，实际上分两类：

| 类型 | 例子 | 实现方式 |
|---|---|---|
| **纯输出** | 单击发 `Shift+Tab`、发 `/model`、发 `Esc` | ✅ 键盘独立完成 |
| **依赖状态** | 长按「复位到 default」、长按「循环切换模型」 | ❌ 键盘只发**信号**，上位机执行 |

### 1.1 为什么「复位到 default」不能由键盘做

直觉方案是：长按就连续发 `Shift+Tab` 直到转回 default。但**转几圈才回到 default 是不确定的**：

- 用户在键盘外按过 `Shift+Tab`
- Claude Code 自己切换过（比如 plan 批准后进入 auto）
- 循环里有 4 档，从哪一档出发都是未知的

所以键盘只能发一个「请求复位」的信号，由**读取终端状态栏的上位机**执行真正的复位——因为只有上位机知道当前在哪一档。

### 1.2 信号怎么发

用 `Ctrl+Alt+Shift+F13` / `F14` 这类**极难误触**的组合：

```dts
m_perm_reset:  &kp LC(LA(LS(F13)))
m_model_cycle: &kp LC(LA(LS(F14)))
```

为什么用 F13/F14：它们在 HID 协议里是合法键码（0x68 起），但普通键盘没有这些键，所以**不会被误触发**，也不会与任何软件的快捷键冲突。上位机监听这两个键即可。

---

## 2. 矩阵设计

### 2.1 为什么是 3 行 × 6 列

物理布局是三行五列 11 键，但矩阵多了一列——**第 6 列专门给审批拨杆**。

好处：拨杆被当作一个普通按键处理，不需要写自定义驱动就能被固件读到。拨到 ON 时它表现为「持续按下」，OFF 时释放。

```
        列1    列2    列3    列4    列5    列6
行1     访问    ↑     模型   命令行  停止   审批拨杆   ← 6 个
行2      ←      ↓      →     回车     —      —        ← 4 个
行3     空格    —      —      —     语音     —        ← 2 个
```

12 个交点全部用上，无浪费。

### 2.2 大键的并联接法

回车（2u）和空格（4u）在定位板上分别开了 2 个和 3 个轴孔（解决长键翘曲）。这些轴体在**电气上并联**到同一个矩阵交点：

- 回车：两个轴都接 `(行2, 列4)`
- 空格：三个轴都接 `(行3, 列1)`

**PCB 设计时必须把这些焊盘接到同一条行线/列线**，否则会出现两个独立的键位。

### 2.3 二极管方向

`diode-direction = "col2row"`，即二极管从列线指向行线，行线用 `GPIO_PULL_DOWN`。

审批拨杆虽然是开关不是轴体，**建议也串一只 1N4148**——否则拨杆 ON 时与其他键同按可能产生鬼影。

---

## 3. 手势实现

ZMK 没有现成的「单击 A、双击 B、长按 C」三合一行为，需要用**行为嵌套**组合出来。

### 3.1 嵌套结构总览

| 键位 | 外层（hold-tap） | 内层（tap-dance） |
|---|---|---|
| 停止 | 长按 = 退出会话 | 单击 = Esc，双击 = Ctrl+C |
| 语音 | 按住 = Space | 单击 = 无，双击 = /voice |

其余键位只用到一层：

| 键位 | hold-tap |
|---|---|
| 访问等级 | 长按 = 复位信号 / 单击 = Shift+Tab |
| 模型 | 长按 = 循环信号 / 单击 = /model |
| 命令行 | 长按 = `@` / 单击 = `/` |
| 空格 | 长按 = Tab / 单击 = Space |
| 回车 | 仅 tap-dance（单击 Enter，双击 Shift+Enter） |

### 3.2 长按侧为什么用「宏」而不是「按键」

以命令行键为例：长按要输出 `@`。

如果用 `bindings = <&kp AT>, <&kp SLASH>`，长按时 ZMK 会让 `AT` **保持按下**，操作系统触发自动重复 → 输出 `@@@@@@@@`。

改用宏：

```dts
m_at: m_at {
    compatible = "zmk,behavior-macro";
    #binding-cells = <0>;
    wait-ms = <5>;
    tap-ms  = <5>;
    bindings = <&kp AT>;      // 宏的 tap 模式 = 按下再松开，只输出一次
};
```

宏在 tap 模式下是「按下→松开」，**只输出一个字符**，且不参与自动重复。空格的长按 Tab、停止的长按退出会话，都用了这个模式。

### 3.3 hold-tap 的参数占位规则

ZMK 的 hold-tap 固定是 `#binding-cells = <2>`，两个参数分别转发给 hold 和 tap 行为。

**零参数的行为（宏、tap-dance）要传 `0` 占位**：

```dts
&stop 0 0            // hold = m_quit(0参), tap = stop_td(0参)
&cmd 0 SLASH         // hold = m_at(0参),   tap = &kp(1参)
&spc_tab 0 SPACE     // hold = m_tab(0参),  tap = &kp(1参)
```

> 这是 ZMK 的硬性要求，漏了会编译失败。`tools/check_keymap.py` 会校验每个行为的参数个数。

### 3.4 flavor（裁决策略）怎么选

`flavor` 决定「按住期间又按了别的键」时判 hold 还是 tap。本项目按**误触代价**选：

| 键位 | flavor | 理由 |
|---|---|---|
| 空格 | `tap-preferred` | 最高频键。只有**刻意按住 300ms** 才出 Tab，正常打字绝不会误判 |
| 停止 | `tap-preferred` | 退出会话是破坏性操作，1200ms 长按才触发 |
| 语音 | `hold-preferred` | 「按住说话」是主用法，200ms 就进 push-to-talk |
| 访问等级 / 模型 / 命令行 | `balanced` | 折中，单击与长按都常用 |

### 3.5 空格键的特殊保护

空格是唯一一个「单击极高频、长按有副作用」的键，所以给了三重保护：

```dts
spc_tab: space_tab {
    flavor = "tap-preferred";        // 犹豫时判 tap
    tapping-term-ms = <300>;         // 要按住 300ms 才算长按
    quick-tap-ms = <150>;            // 150ms 内连按强制判 tap
    require-prior-idle-ms = <120>;   // 刚打完别的字后的 120ms 内禁用长按
};
```

---

## 4. 审批拨杆的处理

### 4.1 当前方案（v0.1）

拨杆接在矩阵 `(行1, 列6)`，绑定 `&kp F13`：

| 拨杆 | 键盘行为 |
|---|---|
| 拨到 ON | 持续按下 `F13` |
| 拨回 OFF | 释放 `F13` |

上位机监听 `F13` 的按下/释放事件，即可知道拨杆状态，从而决定是否自动审批。

**为什么这样够用**：拨杆是**两态**而非瞬时按键，`F13` 的「按下持续 / 释放」正好一一对应 ON / OFF，不需要额外的通信通道。

### 4.2 局限

这个方案只能**上报状态**，「检测到审批弹窗就自动应答」的逻辑全在上位机侧。这是刻意的——上位机才看得见终端输出。

### 4.3 更好的方案（后续）

PRD 6.3 定义了自定义 GATT 服务，可以把拨杆状态、权限档位、模型名做成特征值双向通信。这样：

- 键盘可以主动上报拨杆状态，不占用 HID 键码
- 上位机可以回写状态，驱动按键 RGB 显示当前档位（PRD 第 8 章）

代价是要写 ZMK 自定义 GATT 服务（C 代码），工作量明显大于当前方案。**建议先跑通 v0.1，确认产品可用后再做。**

---

## 5. 后续工作

按优先级：

| 优先级 | 事项 | 说明 |
|---|---|---|
| **P0** | **PCB 设计** | 当前只有外壳和定位板。PCB 决定引脚分配，需与 `claudepad.overlay` 对齐 |
| **P0** | **上位机程序** | 监听 `F13`/`F14`、读状态栏、执行复位与模型循环。**没有它，长按功能是空的** |
| **P1** | 编译验证 | 本文档的语法依据 ZMK 官方文档编写，但**未经实际编译**（本地无 Zephyr 工具链）。首次构建时请留意报错 |
| **P1** | 实测手感调参 | `tapping-term-ms` 等参数需上手实测后微调 |
| **P2** | 自定义 GATT 服务 | 实现状态回写与 RGB 指示 |
| **P2** | 每键 RGB 状态指示 | 依赖 P2 的 GATT 服务 |

### 5.1 关于「未经编译验证」

**这一点必须说清楚**：本固件配置是依据 ZMK 官方文档（shield 结构、hold-tap、tap-dance、macros 的语法）编写的，并做了静态一致性校验（`tools/check_keymap.py` 验证了键位数量、顺序、功能、参数个数）。

但**本地没有 Zephyr 工具链，所以没有真正编译过**。首次构建如果报错，大概率是：

1. `#include` 路径或 ZMK 版本差异（`west.yml` 锁在 `v0.1.0`）
2. 某个行为属性名在新版 ZMK 里改了
3. `F13` 键码名称（若报错可换成 `F14` 或其他）

---

## 6. 与其它交付物的关系

```
docs/PRD.md                  ← 产品定义（键位、手势、边界）
        │
        ├──→ cad/             ← 结构：外壳 / 定位板 / 键帽
        │       │
        │       └──→ 定位板轴孔数 ──┐
        │                            │
        └──→ firmware/       ← 固件：键位与手势
                │                    │
                └── tools/check_keymap.py ──→ 交叉校验两边是否一致
```

`tools/check_keymap.py` 是关键的「防漂移」工具：它把 `cad/lib/params.scad` 的键位表与 `claudepad.keymap` 的绑定逐项比对。改了任一边忘了另一边，脚本会立刻报错。

---

## 7. 一页速查

```
【矩阵】3 行 × 6 列，用 12 个交点（第 6 列给审批拨杆）
【大键】回车 2 轴并联到 (2,4)，空格 3 轴并联到 (3,1)
【引脚】行 D4/D5/D6，列 D7/D8/D9/D10/D16/D14（待 PCB 定稿）

【核心约束】键盘无状态 → 依赖状态的操作只发信号，上位机执行
【信号键码】复位 = Ctrl+Alt+Shift+F13 ｜ 模型循环 = Ctrl+Alt+Shift+F14

【长按侧用宏】避免自动重复输出 @@@@@@
【零参行为占位】&stop 0 0 ｜ &cmd 0 SLASH ｜ &spc_tab 0 SPACE
【空格三重保护】tap-preferred + 300ms + quick-tap 150ms + prior-idle 120ms

【改键位后必跑】python tools/check_keymap.py
【未经编译验证】首次构建可能需微调，见 §5.1
```

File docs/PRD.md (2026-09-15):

# ClaudePad 产品需求文档（PRD）

**产品代号**：ClaudePad
**形态**：蓝牙（BLE）连接的编程专用实体小键盘
**版本**：v0.1（产品定义阶段）
**日期**：2026-09-14
**目标宿主**：Claude Code（CLI / 终端为主，兼容 IDE 终端）

---

## 1. 产品定位

### 1.1 一句话定义

一把为 AI 编程对话场景定制的蓝牙小键盘，把「与 Claude Code 对话、切换权限、审批操作」这些高频且必须用键盘完成的动作，从手指在 104 键上"找键"变成"按一个专属键"。

### 1.2 要解决的核心痛点

| 痛点 | 现状 | 本产品方案 |
|---|---|---|
| 方向键离手远 | 主键盘方向键在右侧，从打字区过去要移动整只手 | 方向键独立成一组，贴在主位区旁 |
| 权限模式切换靠记忆 | `Shift+Tab` 循环切，切到哪一档要靠状态栏文字确认 | 独立「访问等级键」，键帽丝印 + RGB 指示当前档位 |
| 审批要手动点 | 长任务中频繁弹出审批，每次都要移动手到回车 | 侧边物理拨杆，ON 时自动应答审批 |
| 语音输入要打命令 | 要先敲 `/voice` 再按住空格 | 独立语音键，按住即说 |
| 模型切换要打命令 | 敲 `/model` 或按 `P` 且要确认当前是哪个模型 | 独立模型切换键，长按进选择器 |

### 1.3 非目标（明确不做）

- ❌ 不做全尺寸键盘，不做打字主力键盘（本产品是**副键盘 / 快捷键外设**，定位为"左手边那块小板子"）
- ❌ 不做无线接收器版本（只做 BLE，不支持 2.4G 私有协议）
- ❌ 首版不追求跨软件通用（先聚焦 Claude Code，其他软件通过可编程键位兜底）
- ❌ 不做屏幕（成本与功耗不划算，状态反馈用 RGB + 键帽丝印）

---

## 2. 目标用户与使用场景

### 2.1 用户画像

**主用户**：使用 Claude Code 长时间跑任务的重度开发者。
典型特征是"双手不离键盘"，对快捷键有肌肉记忆，讨厌在终端里翻找功能，愿意为效率买专用硬件（类似买 Stream Deck 的人）。

### 2.2 核心场景

**场景 A — 长任务守望**
用户让 Claude 跑一个大规模重构，Claude 反复弹出「是否允许执行 rm」「是否允许写入配置文件」。用户此时在做别的事，用左手拇指把侧边拨杆拨到 ON，所有审批自动通过；任务结束拨回 OFF，恢复安全状态。

**场景 B — 权限梯度切换**
开始探索陌生代码库时切到 `plan`（只读）。确认思路后切到 `default` 手动审查。进入批量改文件的重复劳动时切到 `acceptEdits`。

**场景 C — 语音驱动**
构思到一半，不想打字，按住语音键口述需求，松开自动提交。

**场景 D — 打断与纠偏**
Claude 跑偏了，右手食指按下右上角停止键中断生成（单击 `Esc`），用方向键回看历史，改一句话按回车重发。

---

## 3. 按键清单与功能定义

### 3.1 物理按键总表

| # | 按键 | 类型 | 单击行为 | 长按行为 | 备注 |
|---|---|---|---|---|---|
| 1 | `Enter` 回车 | **大键（跨 2 格）** | 发送当前输入 | 双击 = `Shift+Enter` 换行 | 键帽做加高/异色，最容易盲按 |
| 2 | `↑` 上 | 单键 | 上方向 | 自动重复 | 方向键十字 |
| 3 | `↓` 下 | 单键 | 下方向 | 自动重复 | 方向键十字 |
| 4 | `←` 左 | 单键 | 左方向 | 自动重复 | 方向键十字 |
| 5 | `→` 右 | 单键 | 右方向 | 自动重复 | 方向键十字 |
| 6 | `语音` | 单键 | 按住说话，松开提交 | 双击切换启用 | 见 3.3，紧邻空格 |
| 7 | `模型` | 单键 | 唤起模型选择器 | 循环切换常用模型 | 见 3.4 |
| 8 | `空格` | **大键（跨 4 格）** | 空格 | 长按 = `Tab` 补全 | 独占一行，见 3.1.1 |
| 9 | `命令行` | 单键 | 输入 `/` 唤起斜杠命令 | 长按 = `@` 文件引用 | 见 3.5 |
| 10 | `访问等级` | 单键 | 循环切换权限档位（4 档） | 复位到 default | 带 RGB 指示 |
| 11 | `停止` | 单键 | 中断当前生成 / 停止任务 | — | 见 3.6 |
| 12 | `审批` 拨杆 | 侧边拨动开关 | OFF / ON 两态 | — | 见第 4 章，**核心差异点** |

> **本产品共 11 个物理按键 + 1 个侧边审批拨杆。** 其中回车与空格为大键（跨格），其余为单键。低频操作通过长按/双击手势承载，详见 3.6。

### 3.1.1 物理布局：三行五列

**主键区为三行 × 五列网格。** 方向键保留传统十字排列嵌入左侧，空格独占最底一行并横跨四格，回车跨两格位于第二行。

```
        ┌──────┬──────┬──────┬──────┬──────┐   ┌──────────┐
        │ 列1  │ 列2  │ 列3  │ 列4  │ 列5  │   │  侧边    │
┌───────┼──────┼──────┼──────┼──────┼──────┤   │ 审批拨杆 │
│ 行1   │访问等级│  ↑   │ 模型 │命令行│ 停止 │   │          │
├───────┼──────┼──────┼──────┼──────┴──────┤   │   OFF    │
│ 行2   │  ←   │  ↓   │  →   │   回车      │   │    ○     │
├───────┼──────┴──────┴──────┴──────┬──────┤   │          │
│ 行3   │          空格              │ 语音 │   │   ON     │
└───────┴───────────────────────────┴──────┘   │    ●     │
                                                └──────────┘
```

**格位分配表：**

| | 列1 | 列2 | 列3 | 列4 | 列5 |
|---|---|---|---|---|---|
| **行1** | 访问等级 | **↑** | 模型 | 命令行 | 停止 |
| **行2** | **←** | **↓** | **→** | **回车**（跨列4-5） | |
| **行3** | **空格**（跨列1-4） | | | | 语音 |

| 键位 | 位置 | 功能 | 备注 |
|---|---|---|---|
| 访问等级 | 列1·行1 | 循环切换 4 档 | RGB 指示，见第 5 章 |
| ↑ ← ↓ → | 列1-3·行1-2 | 方向键 | **传统十字排列**，↑ 居中，下方一排 ← ↓ → |
| 模型 | 列3·行1 | 单击唤起选择器，长按循环 | 见 3.4 |
| 命令行 | 列4·行1 | 输入 `/` | 见 3.5 |
| 停止 | 列5·行1 | 中断生成 / 停止任务 | 见 3.6 |
| 回车 | 列4-5·行2 | 发送输入 | **大键，跨 2 格** |
| 空格 | 列1-4·行3 | 空格 | **大键，跨 4 格，独占一行** |
| 语音 | 列5·行3 | 按住说话，双击启用 | 见 3.3，紧邻空格 |
| 审批拨杆 | 侧边（不占格位） | OFF / ON 两态 | 见第 4 章，**核心差异点** |

**布局原则：**

1. **方向键优先保形**——方向键是人类肌肉记忆最强的键群，**必须保留传统十字形状**（↑ 居中，下一排 ← ↓ →），不能为了布局整齐而拆散。这是本布局的最高优先级约束。
2. **大键承担高频操作**——空格独占一行横跨 4 格、回车跨 2 格，面积最大化，符合"最高频操作盲按容错最高"的原则。
3. **语音紧邻空格**——语音键位于底行最右，与空格同处底行。因为 Claude Code 的语音模式本身就是"按住空格说话"，两者相邻便于切换手势。
4. **停止键置于上排最右**——停止键位于行1 最右端。作为紧急操作键，位置需**醒目且易于定位**，同时远离空格避免误触（空格是最高频键，若停止紧邻则误停风险高）。
5. **侧边拨杆物理隔离**——不占网格格位，距离主键区最远，且是拨动而非按压，两种操作手感完全不同，避免误触。

> **几何说明**：方向键十字占据「列2·行1」的 ↑ 与「列1-3·行2」的 ← ↓ →，**十字形状完整无拆散**。↑ 两旁的两个格位（列1·行1、列3·行1）填入访问等级与模型——这是几何必然（十字最下排占满三格），也恰好是最合理的利用。

> **关于低频操作**：`Ctrl+R` 历史搜索、`/clear` 清空会话等操作**不占用物理键位**，由主键盘承担；`Tab` 补全、`@` 引用等通过长按/双击手势承载，详见 3.7。

### 3.2 键位设计原则

Claude Code 的实际操作点超过 20 个（权限模式 4 档、模型切换、语音、40+ 斜杠命令、历史回滚、中断、Tab 补全、文件引用 `@`……），而本产品只有 11 个物理键。

**本产品的键位设计原则：**

> **高频操作一键直达，低频操作手势复用，不增加物理键数。**

具体分工：

- **一键直达（11 个物理键）**：回车、方向键、语音、模型、空格、命令行、访问等级、停止 —— 这些是 AI 编程对话中每个会话都会反复用到的操作。
- **手势复用（长按 / 双击）**：`Shift+Enter` 换行、`@` 文件引用、`Tab` 补全、语音启用切换 —— 这些是次要操作，用同一批键的手势承载（详见 3.6）。
- **不纳入范围**：`Ctrl+R` 历史、`Ctrl+O` 详细输出、`/clear` 清空 —— 由主键盘承担，本键盘不做映射。

### 3.3 「语音输入键」行为定义

**关键依据**：Claude Code 的语音功能是 `/voice` 命令启用的"按住说话"（push-to-talk），默认绑定在**空格键**上。

因此本产品的语音键需要区分两种设计：

| 方案 | 行为 | 优劣 |
|---|---|---|
| **方案 A（推荐）** | 语音键模拟"按住空格说话"，前提是用户已开启 `/voice` | 无延迟，最接近原生体验；但需用户先启用语音功能 |
| **方案 B** | 语音键发送 `/voice` 命令启用功能，再按住说话 | 单键完成全流程；但首次按下会有一次命令往返延迟 |

**建议实现**：语音键**双击**发送 `/voice` 切换启用状态，**单击按住**执行 push-to-talk。同时键盘上保留独立空格键——当语音未启用时，空格就是普通空格，不冲突。

**位置**：语音键位于底行最右（列5·行3），与空格同处底行。因语音模式本身是"按住空格说话"，两者相邻使手势切换自然。

**状态反馈**：语音录制中，语音键 RGB 呼吸灯（红光）。

### 3.4 「模型切换键」行为定义

Claude Code 中模型切换可通过 `/model [model]` 命令或 `P` 键触发。

| 操作 | 行为 |
|---|---|
| 单击 | 发送 `/model` 并回车，唤起模型选择列表 |
| 长按（>800ms） | 在当前会话的常用模型间**循环切换**（快捷键实现，无菜单） |

**为什么加长按**：菜单选择需要方向键 + 回车三步，而循环切换只需一下。用户在 Opus / Sonnet 之间来回切时，长按是效率最高的路径。

**状态反馈**：模型键 RGB 颜色区分当前模型（如 Opus 紫、Sonnet 蓝）。**注意**：键盘无法感知 Claude Code 内部用了哪个模型，需要上位机配合读取状态后回写，详见 6.3。

### 3.5 「命令行键」行为定义

| 操作 | 行为 |
|---|---|
| 单击 | 输入 `/` 字符，唤起 Claude Code 的斜杠命令补全菜单 |
| 单击后继续键入 | 正常字母输入补全 |

**设计考量**：不做"N 个命令专属键"。斜杠命令有 40+ 个（`/clear` `/compact` `/resume` `/cost` `/context` `/diff` `/model` `/permissions` `/hooks` `/mcp` `/agents` `/voice` …），做专属键必然臃肿。正确做法是**一键唤起菜单 + 传统输入筛选**。

长按此键 = `@`，用于文件引用（见 3.6）。

### 3.6 「停止键」行为定义

**停止键是紧急操作键**，位于行1 最右格（列5·行1）。

| 操作 | 行为 | 说明 |
|---|---|---|
| **单击** | 发送 `Esc` | 中断当前生成 / 打断正在输出的回答 |
| **双击** | 发送 `Ctrl+C` | 强制取消当前任务（比 Esc 更彻底） |
| **长按（>1.5s）** | 发送 `Ctrl+C` 两次 | 退出当前会话（需谨慎，不轻易触发） |

**设计考量**：

1. **位置选择**——放在行1 最右端。该位置在键盘右上角，是**视线与手指都容易定位的显著位置**；同时远离空格（最高频键），避免误触导致意外中断。相比放在空格旁边，此方案以"降低误触风险"优先。
2. **为什么需要物理键**——停止是**唯一的"紧急中断"操作**，用户需要在发现 AI 跑偏的**第一瞬间**按下。如果还要移手到主键盘找 `Esc`，那几秒的延迟足以让 AI 完成一连串错误操作。
3. **单击 = Esc 而非 Ctrl+C**——`Esc` 只中断当前生成但保留会话上下文，是更常见的需求；`Ctrl+C` 会取消整个任务，破坏性更强，所以放在双击（需要刻意操作）。
4. **键帽设计**——建议用**凸起或异色键帽**，便于在盲操时通过触感快速定位，无需低头寻找。

**状态反馈**：按下后键盘短暂显示橙光确认（区别于审批拨杆的红色警示）。

### 3.7 低频操作的处理方式（手势复用）

除停止键外，产品不再增加物理键。以下低频操作通过**手势复用**承载：

| 承载方式 | 映射 | 用途 |
|---|---|---|
| 双击「语音」 | `/voice` | 切换语音功能启用状态 |
| 长按「模型」 | 循环切换模型 | 免菜单快速切换 |
| 长按「访问等级」 | 复位到 `default` | 一键回到安全档位 |
| 双击「回车」 | `Shift+Enter` | 输入框内换行 |
| 长按「命令行」 | `@` | 文件引用 |
| 长按「空格」 | `Tab` | 自动补全 |

**其余更低频操作**（`Ctrl+R` 历史搜索、`Ctrl+O` 详细输出、`/clear` 清空会话）**由主键盘承担**，不纳入本产品范围。

---

## 4. 「侧边自动审批按钮」——核心差异点

### 4.1 功能定义

**拨杆式物理开关，两态：**

- **OFF**：键盘不干预任何审批流程，一切按 Claude Code 原生行为走
- **ON**：键盘进入**监视模式**，当检测到 Claude Code 弹出审批申请时，**自动代替用户发送"同意"**

### 4.2 与「访问等级键」的职责边界（重要）

这两者**不是重复功能**，而是两个层次：

| 维度 | 访问等级键 | 审批拨杆 |
|---|---|---|
| **作用对象** | 规则本身 | 已经发生的申请 |
| **时机** | 事前——设定"什么样的操作才要问我" | 事中——模型已经在等待答复 |
| **持续性** | 切换后持续生效，直到下次切换 | 拨杆在 ON 期间生效 |
| **本质** | 修改 Claude Code 的 `permissions.defaultMode` | 监听审批事件并自动应答 |
| **粒度** | 按操作类型分级（只读 / 编辑 / 命令 / 全部） | 全通过，不做类型区分 |

**举例说明差异**：
- 用**访问等级键**切到 `acceptEdits`：文件编辑不再询问，但 `rm -rf` 这类命令**仍会**询问。
- 把**审批拨杆**拨到 ON：连 `rm -rf` 的询问也会被自动同意。

> ⚠️ 因此审批拨杆是**高风险开关**，必须配套强视觉警示，见 4.5。

### 4.3 实现机制（两种技术路线）

**路线一：终端输出嗅探（推荐，纯键盘可实现）**

键盘通过 BLE HID 与主机相连，同时上位机（或键盘固件的辅助通道）监视 Claude Code 的终端输出。

```
Claude Code 输出审批提示
        ↓
检测到特征串（如 "Do you want to proceed?" / "1. Yes" / "❯ 1. Yes"）
        ↓
拨杆 = ON ？
   ├─ 否 → 不动作
   └─ 是 → 向终端注入「回车」或「Y」+ 回车
```

**优点**：不碰 Claude Code 配置，不改变权限模型，可逆、可控。
**缺点**：依赖终端输出特征匹配，Claude Code 改文案可能失效。

**路线二：直接改写权限配置**

拨杆 ON 时，由上位机把 `~/.claude/settings.json` 的 `permissions.defaultMode` 改为 `acceptEdits`（或启动 Claude Code 时加 `--permission-mode`）。拨杆 OFF 时改回。

**优点**：不依赖文案匹配，稳定。
**缺点**：粒度粗、有落盘副作用、`auto`/`bypassPermissions` 在项目级 settings 中不生效（必须在用户级），且修改配置文件的行为本身可能被其他工具感知。

**建议**：**首版走路线一**，把路线二作为高级选项。理由：路线一不改变用户环境、行为完全可逆、不会因为改配置文件导致用户在别处的困惑。

### 4.4 自动应答的"安全默认值"

不是所有审批都该自动同意。建议按以下分级：

| 审批类型 | 拨杆 ON 时行为 |
|---|---|
| 文件读取 | 自动同意 |
| 文件编辑 / 创建 | 自动同意 |
| 常规 shell 命令（`ls` `git status` `npm test`） | 自动同意 |
| 危险命令（`rm -rf`、`sudo`、写入受保护路径、`git push --force`） | **默认不自动同意**，改为高亮闪烁提示，需用户按键确认 |
| `AskUserQuestion`（需要用户交互的工具） | **永不自动应答**（Claude Code 本身也不会自动批准这类） |

**注意**：Claude Code 官方明确即使 `bypassPermissions` 模式下也有不自动批准的操作（显式 `ask` 规则、`AskUserQuestion`、关键路径的 `rm`/`rmdir`、跨会话消息保护等）。键盘的自动审批应当**尊重这些不可绕过的边界**，不做"强行注入"。

### 4.5 安全设计（必须项）

| 措施 | 说明 |
|---|---|
| 拨杆位置醒目 | 放在键盘**侧边**，用大面积红色拨杆，与按键物理隔离，防误触 |
| 状态灯常亮 | ON 时键盘整体指示灯变红/橙，或拨杆旁高亮 LED，余光可见 |
| 启动蜂鸣 | 拨到 ON 时蜂鸣一声，拨回 OFF 时蜂鸣两声 |
| 自动回位（可选） | 可配置"ON 状态 30 分钟无操作自动回 OFF" |
| 危险命令白名单 | 见 4.4，危险命令不自动通过 |
| 二次确认（可选） | 高安全模式：拨杆 ON 后首次自动审批前需长按确认一次 |

---

## 5. 访问等级键——4 档定义

依据 Claude Code 官方权限模式文档，键盘的 4 档映射为 `Shift+Tab` 循环内的四个常用档位：

| 档位 | Claude Code 配置值 | UI 标签 | 含义 | 键帽 RGB |
|---|---|---|---|---|
| ① | `plan` | Plan | 只读研究，不做任何修改，先出计划 | 蓝 |
| ② | `default` | Manual | 每个编辑和命令都要确认（最安全） | 绿 |
| ③ | `acceptEdits` | Edit automatically | 自动接受文件编辑，命令仍询问 | 黄 |
| ④ | `auto` | Auto | 一切自动，后台分类器安全检查 | 橙 |

### 5.1 为什么是这个顺序

按**放权程度递增**排序：只读 → 手动 → 自动改文件 → 全自动。用户按住一键循环时，心里的预期是"越来越放手"，而不是官方那个 `default → acceptEdits → plan` 的顺序（那个顺序对新手不直观）。

### 5.2 两个未进入 4 档的模式

| 模式 | 为什么不做进循环 |
|---|---|
| `dontAsk` | 官方明确规定**永不进入 Shift+Tab 循环**，只能靠 `--permission-mode dontAsk` 启动。键盘无法在会话中切到它 |
| `bypassPermissions` | 官方规定必须先以该模式启动才能进入循环，且仅限隔离容器/虚拟机。放进常规循环太危险 |

**处理方式**：这两个模式**不纳入键盘映射**。用户如需要，直接在终端以启动参数指定（`claude --permission-mode dontAsk`）。

### 5.3 状态反馈机制

**核心难题**：键盘不知道 Claude Code 当前处于哪一档。

**解决方案优先级**：

1. **被动侦测（推荐）**：上位机读取终端状态栏文本（如 `⏸ plan mode on`、`⏵⏵ accept edits on`、`⏵⏵ auto mode on`），解析后回写给键盘。这是最准确的方式。
2. **主动记账**：键盘自己记住"我按了几次"，据此推算档位。缺点：用户在键盘外按 `Shift+Tab`、或 Claude Code 自己切换（如 plan 批准后进入 auto）时，键盘的记账会错位。**此方案单独使用不可靠，只作为上位机不可用时的降级方案。**
3. **混合**：优先被动侦测；侦测不到时用主动记账；两者冲突时以被动侦测为准。

### 5.4 长按复位

长按访问等级键 >1.5 秒 → 复位到 `default`。

**理由**：用户在慌乱中最需要的是"立刻回到安全状态"，而不是循环按三下。一键回到手动审查是最符合直觉的紧急出口。

---

## 6. 通信与协议设计

### 6.1 传输层

| 项目 | 方案 |
|---|---|
| 无线 | BLE 5.0+（低功耗，兼容性好） |
| 标准通道 | HID over GATT（HOGP）——用于发送按键，无需驱动、免安装 |
| 辅助通道 | BLE 自定义 GATT 服务——用于键盘 ↔ 上位机双向通信（状态回写、配置下发） |

**为什么需要双通道**：HID 只能单向"发按键"，无法接收"当前权限档位""当前模型名"这类状态。自定义 GATT 服务提供回传能力，才能实现 5.3 的 LED 状态指示。

### 6.2 HID 按键映射表

| 物理键 | 发送的 HID 报告 |
|---|---|
| Enter | `Enter` |
| ↑ ↓ ← → | 对应方向键 |
| 空格 | `Space` |
| 语音（按住） | `Space`（长按，配合 `/voice` 已启用） |
| 语音（双击） | `/voice` 字符序列 + `Enter` |
| 模型（单击） | `/model` 字符序列 + `Enter` |
| 模型（长按） | 由上位机执行循环切换（发自定义事件，不发按键） |
| 命令行 | `/` |
| 命令行（长按） | `@` |
| 空格（长按） | `Tab` |
| 回车（双击） | `Shift+Enter` |
| 停止（单击） | `Esc` |
| 停止（双击） | `Ctrl+C` |
| 访问等级 | `Shift+Tab` |
| 访问等级（长按） | 连续发送 `Shift+Tab` 直至回落 default，或发自定义事件由上位机处理 |
| 审批拨杆 ON | 自定义 HID Consumer Control 事件 / 自定义 GATT 特征值 |

### 6.3 自定义 GATT 服务草案

| 特征值 | 方向 | 用途 |
|---|---|---|
| `PermissionMode` | 主机 → 键盘 | 回写当前权限档位（plan/default/acceptEdits/auto），驱动 RGB |
| `ModelState` | 主机 → 键盘 | 回写当前模型名，驱动模型键颜色 |
| `ApprovalSwitch` | 键盘 → 主机 | 上报拨杆状态变化（ON/OFF） |
| `ApprovalEvent` | 主机 → 键盘 | 通知"当前有审批弹出"，键盘可据此闪烁提示 |
| `KeyConfig` | 主机 → 键盘 | 下发键位重映射配置（可编程键位） |
| `BatteryLevel` | 键盘 → 主机 | 电量上报 |

---

## 7. 硬件选型建议

### 7.1 主控芯片

| 方案 | 优势 | 劣势 | 推荐度 |
|---|---|---|---|
| **nRF52840** | 蓝牙协议栈成熟、低功耗顶级、ZMK 原生支持、社区资源多 | 单价略高 | ⭐⭐⭐⭐⭐ |
| **ESP32-C3 / S3** | 便宜、生态大、可跑更复杂逻辑 | 功耗高于 nRF | ⭐⭐⭐ |
| **nRF52832** | 便宜、够用 | 内存小，扩展受限 | ⭐⭐⭐ |

**建议**：**nRF52840**。若采用现成的开源方案（如 nice!nano 兼容板），可直接省掉射频设计这一大块工作。

### 7.2 固件方案

| 方案 | 说明 | 推荐度 |
|---|---|---|
| **ZMK** | 现代开源键盘固件，BLE 原生、配置化、低功耗好、支持自定义 GATT 扩展 | ⭐⭐⭐⭐⭐ |
| QMK + 蓝牙 | QMK 蓝牙支持弱，不推荐 | ⭐⭐ |
| 裸机自研 | 完全可控，但蓝牙协议栈工作量巨大 | ⭐ |

**建议**：**ZMK**。它是目前 BLE 键盘的事实标准，支持 `zmk,behavior-*` 自定义行为和扩展，且键位映射用 devicetree 描述，改键位不用改代码。

### 7.3 其他部件

| 部件 | 建议 |
|---|---|
| 轴体 | 建议矮轴（如凯华 Choc），键程短、适合快捷键高频敲击、键盘可做薄 |
| 方向键 | 可用五向摇杆（joystick）替代四个独立键，进一步省空间 |
| 审批拨杆 | 推荐 **SPDT 拨动开关**（手感明确、状态可见），不推荐自复位按钮 |
| RGB | 每键独立 WS2812，用于权限档位 / 模型 / 语音状态指示 |
| 电池 | 500–800mAh 锂电池，BLE 低功耗下续航可达数周 |
| 输入电压 | USB-C 充电 + 有线模式切换（有线时可省电、可刷固件） |

---

## 8. 状态反馈设计总表

| 状态 | 表现 |
|---|---|
| 权限档位 = plan | 访问等级键 蓝色常亮 |
| 权限档位 = default | 访问等级键 绿色常亮 |
| 权限档位 = acceptEdits | 访问等级键 黄色常亮 |
| 权限档位 = auto | 访问等级键 橙色常亮 |
| 审批拨杆 = ON | **全键盘红色警示灯常亮** + 拨杆旁 LED 亮 |
| 审批拨杆 = ON 且自动通过了一次审批 | 全键盘红色闪烁一次 |
| 检测到危险命令审批（未自动通过） | 全键盘橙色闪烁，等待用户按键 |
| 语音录制中 | 语音键红色呼吸 |
| 蓝牙未连接 | 全体指示灯慢速白色呼吸 |
| 电量 < 15% | 全体指示灯低频红色闪烁 |

---

## 9. 边界条件与风险

### 9.1 技术风险

| 风险 | 影响 | 缓解措施 |
|---|---|---|
| Claude Code 更新改变审批文案 | 输出嗅探失效，自动审批不工作 | 特征匹配做成可配置规则集；提供"最近未匹配的审批提示"日志供用户补充规则 |
| 终端渲染复杂（TUI 重绘、ANSI 转义） | 文本嗅探解析困难 | 优先解析结构化部分；或走 Claude Code hooks 机制（见 9.3） |
| 键盘无法感知真实权限档位 | LED 显示错误，用户误判 | 以上位机被动侦测为主，主动记账仅作降级 |
| BLE HID 延迟 | 快捷键响应不跟手 | 选低延迟连接间隔（7.5ms）；有线模式兜底 |
| 自动审批被误认为"键盘帮我做了危险操作" | 用户信任受损 | 强制视觉警示 + 危险命令白名单 + 完整操作日志 |

### 9.2 合规与信任风险

- **自动审批本质上是代替用户做安全决策**。必须让用户在开启时明确知晓风险，建议首次拨到 ON 时在屏幕上显示一次性风险提示。
- 建议**默认关闭**自动审批功能，由用户在设置中主动开启。
- 建议保留**审批操作日志**（时间、命令内容、是否自动通过），便于事后审计。

### 9.3 待验证的技术路径：Claude Code Hooks

Claude Code 支持 **hooks** 机制（`PreToolUse` / `PostToolUse` 等），可以在工具调用前执行自定义脚本并返回决策。相比终端文本嗅探，hooks 是**官方支持的稳定接口**：

```
模型发起工具调用
        ↓
PreToolUse hook 被触发
        ↓
hook 脚本读取键盘拨杆状态（通过本地 socket / 文件 / GATT）
        ↓
拨杆 ON → 返回 allow；拨杆 OFF → 返回 ask（走原生流程）
```

**这是比文本嗅探更优的方案，建议在技术验证阶段优先尝试。** 好处：
- 不依赖终端输出格式，Claude Code 升级不易失效
- 决策在官方提供的扩展点上做，不侵入
- 可以拿到结构化的工具名和参数，能实现 4.4 的危险命令分级

**待办**：验证 hooks 能否实时读取外部状态（键盘拨杆），以及 hook 返回 `allow` 是否能跳过审批提示。

---

## 10. 开发路线图（建议）

| 阶段 | 目标 | 关键产出 |
|---|---|---|
| **P0 产品定义** | 确认键位、交互、边界（当前阶段） | 本 PRD + 键位图 + 时序图 |
| **P1 技术验证** | 打通 BLE HID + hooks 自动审批 | 一块开发板能发出单个按键；hooks 能读到外部开关状态 |
| **P2 原型机** | 11 键（含回车/空格大键）+ 侧边拨杆实体原型 | 可用硬件、基础 ZMK 固件、键位全部可用 |
| **P3 上位机** | 状态回写、配置界面 | 桌面程序（Tauri/Electron），能显示并同步权限档位 |
| **P4 打磨** | 安全机制、日志、可编程键位 | 可量产版本 |

**当前建议下一步**：进入 P1 技术验证，优先验证 **Claude Code hooks 读取外部状态** 这一条路径——它决定了审批拨杆的技术路线选择，是整个产品最大的不确定性。

---

## 附录 A：Claude Code 权限模式速查（依据官方文档）

| 配置值 | UI 标签 | 免询问范围 | 状态栏显示 | 是否在 Shift+Tab 循环 |
|---|---|---|---|---|
| `default` | Manual | 仅读取 | `⏸ manual mode on` | ✅ |
| `acceptEdits` | Edit automatically | 读取 + 文件编辑 + 常见文件命令 | `⏵⏵ accept edits on` | ✅ |
| `plan` | Plan | 读取 + 分类器批准的命令 | `⏸ plan mode on` | ✅ |
| `auto` | Auto | 一切（分类器后台审查） | `⏵⏵ auto mode on` | ✅（需可用） |
| `dontAsk` | don't ask | 读取 + 预批准工具，其余拒绝 | `⏵⏵ don't ask on` | ❌ 永不出现 |
| `bypassPermissions` | Bypass permissions | 一切 | `⏵⏵ bypass permissions on` | ⚠️ 需以该模式启动后才出现 |

**启动指定方式**：`claude --permission-mode <值>`
**设置指定方式**：`~/.claude/settings.json` 中 `permissions.defaultMode`（注意 `auto` / `bypassPermissions` 在项目级 settings 中不生效）
**官方文档**：https://code.claude.com/docs/zh-CN/permission-modes

## 附录 B：任何权限模式下都不会自动批准的操作

即使在 `bypassPermissions` 下，以下操作仍不会被自动批准（键盘的自动审批也应尊重这些边界）：

- 匹配显式 `ask` 规则的工具
- 组织设置为 `ask` 的连接器工具
- 需要用户交互的工具（`AskUserQuestion`、`requiresUserInteraction` 的 MCP 工具）
- 针对关键路径的 `rm` / `rmdir`
- 跨会话消息传递保护
- 开启 `permissions.blockReadsOutsideWorkingDirectories` 时的工作目录外读取

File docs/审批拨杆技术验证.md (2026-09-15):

# 审批拨杆技术验证报告

**版本**：v1.0
**日期**：2026-09-14
**验证对象**：PRD 9.3「待验证的技术路径：Claude Code Hooks」
**结论**：✅ **路线成立。审批拨杆可以用官方 hooks 机制实现，且优于原定的文本嗅探方案。**

---

## 0. 一句话结论

PRD 里标注的「整个产品最大的不确定性」已排除。

`PreToolUse` hook 返回 `permissionDecision: "allow"` **确实能跳过权限提示直接执行工具调用**；
而返回空则**不算批准**，工具调用继续走原生流程。

这两条语义恰好构成审批拨杆需要的开关行为：
**拨杆 ON → 返回 allow；拨杆 OFF → 返回空。** 不需要碰终端输出，不需要改权限配置。

---

## 1. 验证依据（官方文档的确切机制）

来源：Claude Code 官方 hooks 文档。

### 1.1 决策的返回方式

PreToolUse 用 `hookSpecificOutput` 对象表达决策，**不是**顶层 `decision` 字段：

```json
{
  "hookSpecificOutput": {
    "hookEventName": "PreToolUse",
    "permissionDecision": "allow",
    "permissionDecisionReason": "原因说明"
  }
}
```

`permissionDecision` 的四个取值：

| 取值 | 含义 |
|---|---|
| `allow` | **批准执行，跳过权限提示** |
| `deny` | 拒绝工具调用 |
| `ask` | 升级给用户询问 |
| `defer` | 延迟，稍后处理 |

### 1.2 关键细节：静默 ≠ 批准

官方原文：

> exit 0 且无输出 = hook 没有决定要报告，工具调用会继续走**正常权限流程**（仍可能提示用户）。hook 可以拒绝调用，但**保持沉默不会批准它**。

**这是整个方案能成立的核心。** 它意味着：

- 拨杆 OFF 时 hook 什么都不输出 → Claude Code 完全按原生行为走，用户的既有配置（`acceptEdits`、`plan` 等）不受任何影响
- 拨杆 ON 时 hook 输出 `allow` → 只有此时才介入

也就是说，**拨杆 OFF 时这个产品是「不存在」的**，不会给用户带来任何行为改变。这是最理想的产品形态。

### 1.3 hook 收到的输入

PreToolUse 的 stdin 是一个 JSON，含：

| 字段 | 用途 |
|---|---|
| `tool_name` | 工具名（`Bash` / `Edit` / `Write` / `AskUserQuestion` …） |
| `tool_input` | 工具参数对象（Bash 是 `command`，Edit 是 `file_path` 等） |
| `permission_mode` | 当前权限模式（`default` / `plan` / `acceptEdits` / `auto` / …） |
| `cwd` | 当前工作目录 |
| `session_id` | 会话标识 |
| `hook_event_name` | 事件名 |

有了 `tool_name` 和 `tool_input`，就能实现 PRD 4.4 要求的**危险命令分级**——这是文本嗅探做不到的。

### 1.4 退出码语义

| 退出码 | 行为 |
|---|---|
| `0` | 正常，解析 stdout 的 JSON |
| `2` | 阻止（对 PreToolUse 即阻止工具调用），stderr 反馈给 Claude |
| 其他非零 | 非阻止错误，执行继续 |

> 注意：**exit 1 不阻止**。要强制阻止必须用 exit 2。

### 1.5 超时

`command` / `http` 类型默认 **600 秒**，可在条目里用 `timeout` 字段自定义。

对本方案来说余量极大——我们只需要读一个文件。

---

## 2. 为什么这条路优于原定的「终端输出嗅探」

PRD 4.3 原本推荐「路线一：终端输出嗅探」，理由是「不碰配置、可逆」。hooks 路线现在看全面更优：

| 维度 | 终端输出嗅探 | Hooks（本方案） |
|---|---|---|
| **稳定性** | 依赖匹配 Claude Code 的文案，**改文案就失效** | 官方支持的稳定接口，不依赖文案 |
| **能否分级** | 只能看到终端文本，难结构化判断 | 直接拿到 `tool_name` + `tool_input`，能精确分级 |
| **是否侵入** | 要解析 TUI 重绘 / ANSI 转义，脆弱 | 官方扩展点，不侵入 |
| **误判风险** | 文本匹配天然会误判 | 结构化字段，无误判 |
| **可逆性** | 可逆 | 同样可逆（删掉 hook 配置即可） |
| **性能** | 需要持续读终端输出 | 每次工具调用一次判断，快路径 ~2ms |

**唯一代价**：需要在 `~/.claude/settings.json` 里加一条 hook 配置。但这比解析终端文本可靠得多，且随时可删。

---

## 3. 实测数据

### 3.1 延迟：command 模式 vs HTTP 模式

hooks 支持两种执行方式，实测差异巨大：

| 模式 | 中位延迟 | 最小 | 最大 |
|---|---|---|---|
| `command`（每次起进程） | **510 ms** | 489 ms | 600 ms |
| `http`（常驻进程应答） | **15 ms** | 2 ms | 28 ms |

**快了 34 倍。** 瓶颈是 Windows 上 Python 解释器的启动开销。

`command` 模式下每次工具调用都要多等半秒，不可接受。所以**最终方案采用 HTTP 模式**：
由一个常驻守护进程同时负责键盘监听和 hook 应答。
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

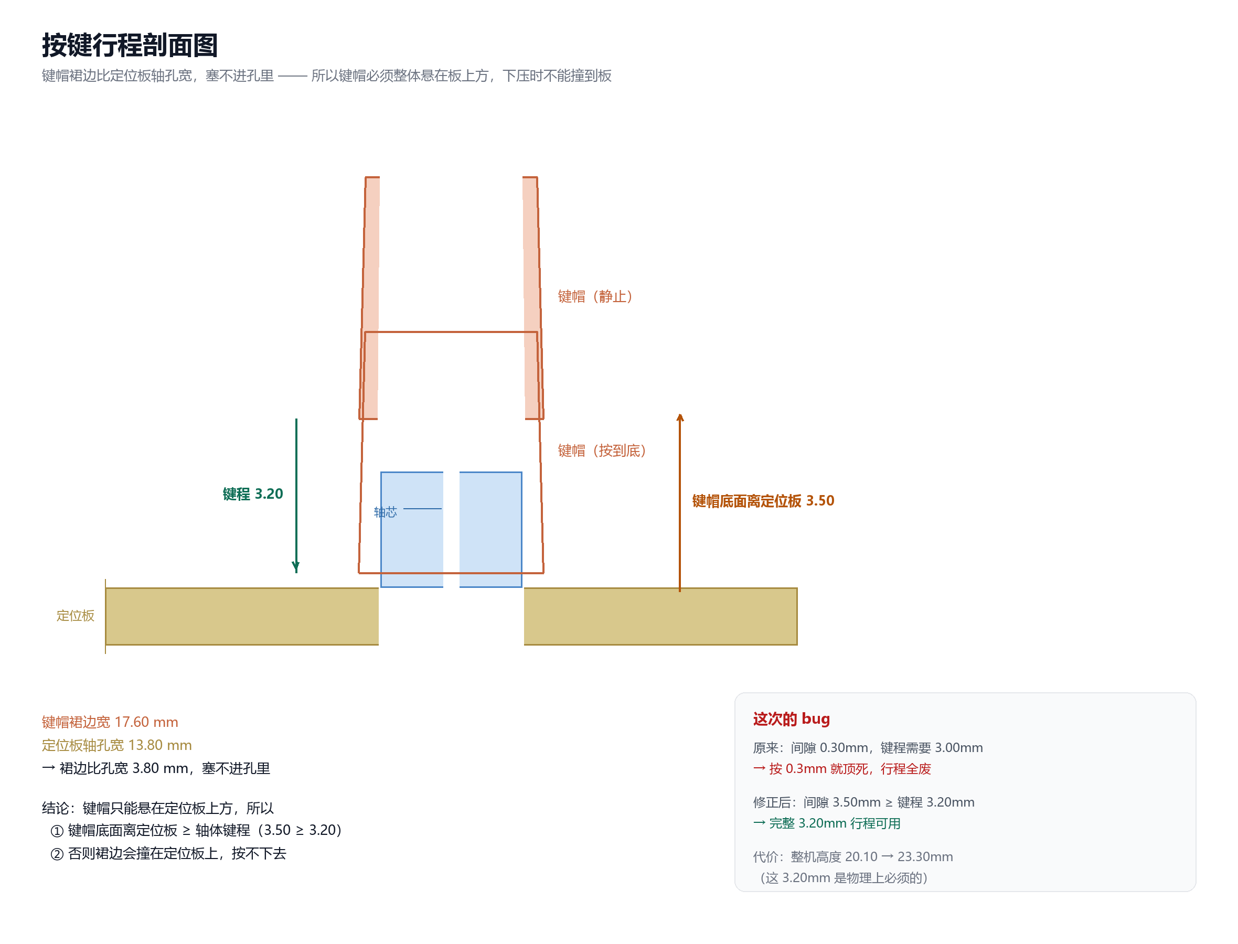
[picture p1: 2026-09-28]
docs/按键行程图.png

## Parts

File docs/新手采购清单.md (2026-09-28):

# ClaudePad 新手采购清单

**面向**：第一次做硬件、要手工焊接的人
**前提**：外壳 / 定位板 / 键帽**已经 3D 打印完成**，这里只列要买的电子件
**原则**：只列项目必需的，不加多余配件；优先推荐**好焊、容错高**的型号

---

## ⚠️ 买之前先看这两条

这两条不影响你买什么，但影响**你打印的外壳能不能用**，先确认一下。

### 1. 主控已改到 PCB 背面 ✅（2026-09-16 解决）

原本主控在 PCB 正面，与 4 个轴体重叠 322.52 mm²（板面 86×50 被 14 个轴体占满，放不下）。
现已改为**装在 PCB 背面右侧**，26 项结构校验全部通过。

**但有两件事要先告诉你：**

**① 你已打印的外壳需要重做**

支撑台位置（在底板上）和 USB 开孔高度（在右壁上）都变了。
**顶盖和定位板不受影响**，重打这两件即可。

**② USB 口够不到外壳右壁 ✅ 已解决**

原本 USB 口距内腔右壁 8.2mm，而插头金属部分只有 6.5mm，插不到底。
已通过 **PCB 加宽**（86 → 98mm）解决：现在距离 2.15mm，插入深度 4.55mm。
**不需要额外买延长线。**

**③ 轴体改用 Choc V2 —— 键帽要重打**

V2（PG1353）的轴心是 **MX 十字**，V1（PG1350）是矩形小十字，**两者键帽互不通用**。
你已打印的键帽是按 V1 做的，插不进 V2。需要用 `cad/output/03~05_*.stl` 重新打印
（模型已按 MX 十字更新）。**定位板不用换**，外壳也不用（内腔尺寸没变）。

→ 详情见 `docs/PCB设计规格书.md` §14.5（实施记录）与 §14.6（USB 遗留问题）。

### 2. 轴体卡扣间隙（`SWITCH_PLATE_GAP`）没实测过

这个值决定「定位板装在外壳里的高度」，当前取 5.0mm，但真实值可能是 3.5–6.0mm 之间。
如果和实际不符，**定位板会装不到位，外壳内腔高度也得改**。

**怎么验证**（两选一，都很快）：
- 拿到轴体后，用卡尺量「轴体底面 → 卡扣下沿」
- 或者打印 `cad/output/00_test_coupon.stl`，把轴体插进去试哪个卡扣最清脆

---

## 一、必需清单（14 项）

### 1. 主控板

| | |
|---|---|
| **名称** | **NoLogo ProMicro NRF52840**（原名 SuperMini NRF52840，兼容 nice!nano）|
| **数量** | 1 块 |
| **用途** | 键盘的大脑。跑 ZMK 固件，把按键通过蓝牙发给电脑 |
| **规格** | nRF52840 / **17.78 × 33.00mm** / Pro Micro 引脚兼容 / 板载天线 / USB-C |

**新手提示**
- ⚠️ **认准正品**。市面很多是 2020 年产芯片，容易坏
- 买「Pro Micro 引脚兼容」版本，否则固件要改引脚定义

**它已经自带的（不用另买）**
- ✅ 锂电池充电电路
- ❌ **没有复位按钮** —— 这款要「短接 RST 到 GND」进刷机模式（见第 14 项）
- ✅ Bootloader（可直接拖拽 .uf2 刷固件）
- ❌ **没有**物理电源开关 → 需要另买（见第 6 项）

---

### 2. 轴体

| | |
|---|---|
| **名称** | **凯华 Choc V2 矮轴 · 红轴（线性）** —— 型号 **PG1353** |
| **数量** | **14 个** |
| **用途** | 按键本体。空格用 3 个、回车用 2 个，其余每键 1 个 |
| **规格** | 轻力度 50±10gf / 矮轴 / 键程 **3.2mm** / 轴心 **MX 十字** |

**★ V1 和 V2 别买混 —— 两者键帽互不通用**

| | Choc V1（PG1350） | **Choc V2（PG1353）** |
|---|---|---|
| 轴心 | 3.4mm 矩形小十字 | **5mm MX 十字** |
| 键帽 | Choc 专用 | **MX 兼容** |
| 键程 | 3.0mm | **3.2mm** |
| 引脚 | 2 根 | **3 根**（2 电气 Ø1.20 + 1 不通电定位 Ø1.50） |
| PCB 中心孔 | 3.429mm | **5.00mm** |

> 上表以**凯华官方规格图**为准（2026-09-26 复核）：V2 共 **3 根引脚**，其中通电的
> 金属电气脚 2 根（官方图 `2-Ø1.20`），另有 1 根不通电的定位脚（官方图 `2*1.5`，Ø1.5）。

本项目按 **V2** 设计（键帽榫槽已改成 MX 十字、PCB 中心孔改 5.0mm）。
买的时候认准型号 **PG1353**；V2 的红轴是 **CPG135301D01**。

**新手提示**
- 每个轴只有 **2 个引脚**，插进去焊上就行，很好焊
- ⚠️ **Choc 是矮轴**，和普通 MX 轴**不通用**，别买错
- 建议多买 1–2 个备用（偶尔会碰到个别轴体手感异常的）

---

### 3. 二极管 ★ 新手最容易买错的一项

| | |
|---|---|
| **名称** | **1N4148 直插二极管（DO-35 玻璃封装）** |
| **数量** | **12 个** |
| **用途** | 键盘矩阵防「鬼影」——同时按多个键时不误判 |
| **规格** | **直插**，引脚长，玻璃封装 |

**★ 一定要买「直插」，不要买贴片！**

| | 直插 DO-35（选它） | 贴片 0805（别买） |
|---|---|---|
| 大小 | 约 4mm 长，引脚伸出 25mm | 2mm × 1.25mm，**肉眼难辨** |
| 焊接 | 手捏着引脚就能焊 | 要镊子 + 放大镜 |
| 新手成功率 | 高 | 低 |

**方向不能接反**：**阳极（有黑环的反面）接列线，阴极（黑环那端）接行线**。
接反了不会烧，但按键读不出来，排查很痛苦——**焊之前先在纸上画一遍**。

**为什么是 12 个而不是 14 个**：二极管是「每个矩阵位置一个」，空格 3 个轴并联成 1 个位置、回车 2 个轴并联成 1 个位置，所以 14 个轴只对应 12 个位置。

---

### 4. 拨动开关（审批拨杆）

| | |
|---|---|
| **名称** | **SPDT 三脚拨动开关** |
| **数量** | 1 个 |
| **用途** | 侧边的审批拨杆 |
| **规格** | **三脚（COM / NO / NC）** / **轴套长度 ≥ 9mm** / **带焊片的更好焊** |

**两个必须注意的**
- ⚠️ **要「拨过去停住」的，不是自复位按钮**（松开回弹的那种）——否则做不出 OFF/ON 两态
- ⚠️ **轴套长度必须 ≥9mm**：外壳壁 2.4 + 凸台 4.1 + 螺母 2.0 = 8.5mm，买短了装不上

**新手提示**：选**带焊片（接线片）**的型号，焊片面积大，比 PCB 插脚好焊得多。

---

### 5. 锂电池

| | |
|---|---|
| **名称** | **3.7V 锂聚合物电池** |
| **数量** | 1 块 |
| **用途** | 供电 |
| **规格** | **容量 ≥ 400mAh**（★ 见下方警告）/ **厚度 ≤4.0mm** / 带保护板 |

**★ 容量下限 200mAh（安全要求），但按续航建议 400–500mAh**

你买的主控（NoLogo ProMicro NRF52840）文档原文：

> 充电电流 **100mA**（BOOT 跳线后 300mA）。**只有当电池容量大于 500mAh 时才可连接 BOOST**，
> 以避免爆炸。

100 ÷ 2 = **200mAh** 是硬下限。但按**续航**选，仍推荐 **400–500mAh**（20µA 待机下可撑数月）。

| 电池容量 | 185mA 充电电流下 | 判定 |
|---|---|---|
| 200mAh | 200/2 = 100 | ⚠️ 刚到下限，续航短 |
| **400mAh** | 400/2 = 200 > 100 | ✅ **推荐** |
| 500mAh | 250 > 100 | ✅ 更好 |

**另外两点**
- 主控的电池接口是 **B+ / B− 两个焊盘**（不是插座），所以电池买**带线**的即可，
  剪掉插头焊上去；不带插头的也行
- 厚度仍要 **≤ 4.0mm**（这一层总共只有 5.0mm）

**新手提示**
- ⚠️ **买带引线的，不要自己焊电池本体** —— 锂电池焊接有起火风险
- 主控的电池接口是 **B+ / B− 焊盘**（不是插座），所以：买**已经焊好引线**的电池，
  把引线焊到主控焊盘上即可。**不要买只有裸极耳的电池**
- ⚠️ **容量必须 ≥400mAh**（见上方警告，充电电流 185mA 的硬要求）
- ⚠️ **厚度必须 ≤4.0mm**，厚了装不进外壳（PCB 下方只有 5.0mm）
- 买带保护板的，防过充过放

---

### 6. 电源开关

| | |
|---|---|
| **名称** | **小型拨动开关**（SPST 或 SPDT） |
| **数量** | 1 个 |
| **用途** | 不用的时候切断电池 |
| **规格** | 能过 1A 即可，体积尽量小 |

**为什么必须买**：NoLogo ProMicro（和官方 nice!nano 一样）**没有**物理电源开关。不切断的话，电池会一直连在板子上，**长期不用会过放损坏**。

---

### 7. 导线

| | |
|---|---|
| **名称** | **30AWG 硅胶线**（单芯） |
| **数量** | 1 卷 |
| **用途** | 连接轴体、二极管、主控 |
| **规格** | 30AWG / **硅胶皮** |

**新手提示**
- **选硅胶皮，别选漆包线**：硅胶皮剥皮就能用；漆包线要刮漆或烙铁烫，新手容易断芯
- 30AWG 有点细，手抖的话可以买 **28AWG**，稍粗一点更好操作

---

### 8. 洞洞板

| | |
|---|---|
| **名称** | **双面洞洞板** |
| **数量** | 1 块 |
| **用途** | 代替 PCB，做机械支撑和走线 |
| **规格** | **≥ 98 × 50 mm** / 2.54mm 孔距 / 双面镀锡 |

**为什么要**：外壳是按「有 PCB」设计的，定位板靠 PCB 支撑。没有板子的话轴体悬空。
另外洞洞板上的孔位方便走线，比纯飞线好操作。

---

### 9. 热缩管

| | |
|---|---|
| **名称** | **热缩管**（多种直径套装） |
| **数量** | 1 小包 |
| **用途** | 包住焊接点和裸露导线，防止短路 |
| **规格** | φ1.5–3mm 混装 |

**为什么算必需**：手工走线容易有裸露的线头互相碰到，短路可能烧主控。几块钱的东西，别省。

---

### 10. USB-C 数据线 ★

| | |
|---|---|
| **名称** | **USB-C 数据线** |
| **数量** | 1 条 |
| **用途** | 刷固件 + 给电池充电 |
| **规格** | USB-C 转 USB-A（或 C），**必须是数据线** |

**新手提示**
- ⚠️ **主控不带线**，要自己买
- ⚠️ **必须是数据线，不是纯充电线**：市面上大量线材只有电源针脚、没有数据针脚，
  插上去电脑**不认设备**，刷不了固件。这是新手最常见的坑
- 认准商品页标注「数据线」「支持传输」或「USB 2.0/3.0」

---

### 11–13. 结构小件

| # | 名称 | 数量 | 用途 / 规格 |
|---|---|---|---|
| 11 | **M2 × 6mm 自攻螺丝** | 4 颗 | 固定定位板。多买 2 颗备用 |
| 12 | **硅胶脚垫 φ8mm** | 4 个 | 防滑，粘在底面四角 |
| 13 | **双面泡棉胶 0.6mm** | 1 片 | 固定电池（电池不能晃） |

---

### 14. 自复位轻触开关 ★ 用来进刷机模式

| | |
|---|---|
| **名称** | **6×6mm 轻触开关（长柄）** 或 **带引线的自复位小按钮** |
| **数量** | 1 个 |
| **用途** | 接在主控的 **RST** 和 **GND** 之间，按一下复位 —— 用来进刷机模式 |
| **规格** | 柄长 **≥8mm**（要穿过 2mm 底板）；或选**带引线**的款 |

**为什么必须买**

你买的这块主控（NoLogo ProMicro NRF52840）**没有复位按钮**。说明书写得很清楚：

> 如果想要进入 Bootloader，请在 **0.5S 内短接 2 次 RST 到 GND**

官方 nice!nano 有物理按钮（双击进入），**这块没有** —— 所以要自己补一个。

**怎么装**

外壳底板**已经预留了一个 φ8mm 的孔**（位置正好在主控外侧，不在主控正下方）：

1. 把轻触开关贴在**底板内侧**，柄对准 φ8mm 孔露出来
2. 两根引线分别焊到主控的 **RST** 和 **GND**
3. 用热熔胶固定开关

> ⚠️ 开关总高要 **< 5mm**（底板到 PCB 之间只有 5.0mm），所以别买高身按钮。

**一个可以省事的办法**

ZMK 支持 `&bootloader` 行为 —— 可以在键位表里加一个键，以后**按键就能进刷机模式**。

⚠️ 但**第一次刷固件时键盘还没有固件**，那个键还不存在 —— 所以物理按钮省不掉。

**预算**：几块钱。

---

## 二、工具（家里没有才买）

新手成功率的**最大变量是烙铁**，不是手速。

| # | 名称 | 规格 | 说明 |
|---|---|---|---|
| 1 | **可调温电烙铁** | T12 / TS101 类，**带细尖头** | ★ 最重要。恒温烙铁比几十块的固定温度笔好用太多 |
| 2 | **焊锡丝** | **0.6mm，63/37 含铅** | ★ 含铅的熔点低、流动性好，新手成功率高得多。**注意通风、焊完洗手** |
| 3 | **助焊剂** | 松香或助焊笔 | 让焊点更亮更牢 |
| 4 | **吸锡带** | 2mm 宽 | 焊错了能救回来 |
| 5 | **镊子** | 防静电尖头 | 夹小元件 |
| 6 | **斜口钳** | 小号 | 剪引脚、剪线 |
| 7 | **万用表** | 带**通断测试**档 | ★ 排查线路必备。焊完一定要逐个测通断 |

**如果想再省**：1、2、7 三项不能省，其余可以慢慢添。

---

## 三、不用买（会白花钱）

| 不要买 | 原因 |
|---|---|
| **充电模块 / TP4056** | nice!nano **自带**充电电路 |
| **键帽 / 定位板 / 外壳** | 你已经 3D 打印了 |
| **排针 / 排母** | 主控装在 PCB **背面**，那一层净空只有 **5.0mm**，而主控本体 3.2mm + 排针座 2.54mm = **5.74mm，超了**。引脚直接穿过 PCB 焊（见 §6） |
| **热插拔轴座** | 轴座在 PCB 下方凸出 2.5–3.0mm，而那一层只有 5.0mm、电池已占 4.6mm，**必然打架** |
| **成品 PCB** | 市面上没有符合这个布局的板（空格中间那根轴不在标准网格上） |
| **ESP32 / ESP32-WROOM-32** | 三个硬伤：开发板厚 **10mm**（键盘只有 3.4 / 5.0mm）；模组引脚间距 **1.27mm** 焊不进洞洞板；**跑不了 ZMK**，要自己写 C 代码。续航还只有 nRF52840 的 1/10 |

---

## 四、焊接顺序（新手建议）

按这个顺序焊，出错最容易发现：

```
1. 先只焊 12 个二极管
   → 焊完用万用表逐个测：正反导通方向对不对

2. 再走矩阵线（3 行 + 6 列）
   → 每走完一条线，测一次通断

3. 焊 14 个轴体
   → 大键的多个轴要并联到同一条线上

4. 最后接主控、拨杆、电池
   → 主控最后接，避免前面焊错把它烧了

5. 先插 USB 刷固件测试，确认按键都对了，再接电池
   → 这一步能省一块电池和一次返工
```

**两条通用原则**
- **每焊完一部分就测一次**，不要全部焊完再排查
- **烙铁停留时间控制在 2–3 秒**，太久会烫坏轴体塑料或焊盘脱落

---

## 五、一页速查（打印出来照着买）

```
【核心电子件】
□ NoLogo ProMicro NRF52840 主控         × 1
□ 凯华 Choc V2 红轴 轻力度（PG1353）              × 14（多备 1-2 个）
□ 1N4148 直插二极管（DO-35）            × 12   ← 必须直插，不要贴片
□ SPDT 三脚拨动开关（轴套 ≥9mm）         × 1
□ 3.7V 锂电池 400-500mAh 厚≤4.0mm       × 1   ← 带引线
□ 小型电源开关                          × 1
□ 30AWG 硅胶线                          × 1 卷
□ 双面洞洞板 ≥98×50mm                   × 1
□ 热缩管 φ1.5-3mm 混装                  × 1 包
  □ USB-C 数据线（必须是数据线）           × 1 条
  □ M2×6mm 自攻螺丝                       × 4
□ 硅胶脚垫 φ8mm                         × 4
□ 双面泡棉胶 0.6mm                      × 1 片
□ 6×6 轻触开关（长柄）                  × 1   ← 进刷机模式用

【工具】（没有才买）
□ 可调温电烙铁 + 细尖头   □ 焊锡丝 0.6mm 63/37
□ 助焊剂                  □ 吸锡带
□ 镊子                    □ 斜口钳
□ 万用表（带通断档）

【不买】
✗ 充电模块   ✗ 键帽/定位板/外壳
✗ 排针排母   ✗ 热插拔轴座  ✗ 成品 PCB
```

---

## 六、主控怎么接线（新手常问）

### 要不要焊排针？

**不要。** 主控现在装在 PCB **背面**，而这一层的净空只有 **5.0mm**：

| 方案 | 占用高度 | 结果 |
|---|---|---|
| 主控本体 | 3.20mm | ✅ 剩 1.80mm |
| 再加标准排针座 | +2.54 = 5.74mm | ❌ 超过 5.0 |
| **导线直接焊** | 不额外占高度 | ✅ **采用** |

### 主控怎么固定、怎么连？

主控**贴在 PCB 背面**（紧贴），引脚**朝上穿过 PCB 上的孔**，焊在**正面**（轴体那一面）。

```
   轴体 ─────────────────────  PCB 正面（焊接面）
                              PCB 板
   主控 ▓▓▓▓▓▓▓▓▓▓▓  ←────  PCB 背面（主控贴这里）
        └─ 引脚向上穿过 PCB，焊在正面
```

**为什么这样最好**：主控紧贴 PCB，**不额外占高度**（总共只 3.2mm），
而那一层只有 5.0mm 可用。

主控边缘是 **2.54mm 通孔**，洞洞板也是 2.54mm 网格 —— **能对齐**。

### nano 怎么摆？

- **元件面朝下**（有蓝色 LED 和复位按钮的那一面，朝向底板）
  - 这样 **USB-C 口在下方**，正好对准右壁那个开孔
  - ⚠️ 这块板**没有复位按钮**，进刷机模式要短接 RST 到 GND → 需要另装一个按钮（见第 14 项）
- **USB-C 口朝右壁**
- 位置固定：**PCB 坐标 (79.70, 8.50)**，贴着 PCB 右侧（右边距仅 0.52mm）

> ⚠️ 元件面朝下意味着主控的**芯片和 USB 座都在下面**，与底板之间只剩 **1.80mm**。
> 装的时候别把导线压在主控底下。

### 数据线要买吗？

**要。** 主控**不带线**，而且必须是**数据线**不是纯充电线。
用途有两个：刷固件 + 给电池充电。

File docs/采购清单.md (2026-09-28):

# ClaudePad 采购清单（BOM）

**版本**：v0.2（原型阶段）
**日期**：2026-09-14（**2026-09-20 同步**：主控定稿 NoLogo ProMicro、PCB 98mm、Choc V2、主控在背面）
**方案**：现成套件改造 + 定制 PCB
**键盘规格**：三行五列 15 格 · 11 键（含回车跨2格 / 空格跨4格）· 侧边审批拨杆 · BLE 无线

> ⚠️ **价格说明**：本清单**不标注具体价格**，因为电子元件价格波动大且随渠道差异明显。请以淘宝/立创商城实时报价为准。清单中给出的是**规格要求**和**选型理由**，照着规格买不会错。

---

## 一、核心结论（先看这个）

### 1.1 为什么不能直接买「套件」

市面上**没有**符合本项目布局的现成套件。你的键盘有两个特殊点：

1. **非标准布局**——三行五列，空格跨 4 格、回车跨 2 格，没有套件是这个形状
2. **侧边审批拨杆**——这是自定义部件，任何套件都不会有

**因此实际做法是：**

> **买一套标准套件 → 用它练手 + 拿它的主控/轴体/键帽/线材 → 然后自己画 PCB 或洞洞板搭真正的 ClaudePad**

套件的价值在于：**验证 BLE 连接和 ZMK 固件能力**，以及**提供一套不会被浪费的通用零件**（主控、轴体、键帽通用）。

### 1.2 强烈建议的推进顺序

| 步骤 | 买什么 | 目的 |
|---|---|---|
| **第 1 步** | 只买「最小验证集」（见第三章） | 花最少的钱验证：BLE 能否连上、ZMK 能否自定义按键、拨杆能否被识别 |
| **第 2 步** | 验证通过后，买完整元器件做原型 | 做真正的三行五列键盘 |
| **第 3 步** | 原型好用后，打定制 PCB | 做正式版 |

**不要一上来就买全套**——你的布局和拨杆机制都还没验证，先花小钱试通再投入。

---

## 二、轴体选型建议（你让我推荐）

### 2.1 推荐：凯华 Choc 矮轴（Kailh Choc V2）

**推荐理由：**

| 维度 | Choc 矮轴 | 标准 MX 轴 |
|---|---|---|
| 总高度 | **低（含键帽约 11mm）** | 高（含键帽约 18mm） |
| 键程 | 短（Choc V2 为 3.2mm） | 长（4.0mm） |
| 触发力度 | 轻（红轴约 35-50g） | 标准（红轴约 45g） |
| 适合场景 | **高频敲击、快速触发** | 长时间打字 |
| 键盘厚度 | 可做很薄 | 偏厚 |

**为什么给你推荐矮轴**：ClaudePad 是**快捷键键盘**，不是打字键盘。使用特征是「快速点按」而非「长时间连续输入」。矮轴的短键程意味着：

- **触发更快**——按下去 1.5mm 就触发，比 MX 轴少走一半路程
- **回弹更快**——连续按方向键时更跟手
- **键盘更薄**——放桌面不占高度，也不用配掌托

### 2.2 具体轴体推荐（按手感排序）

| 轴体 | 手感 | 推荐场景 |
|---|---|---|
| **Choc 红轴（Linear）** | 直上直下，无明显段落 | **首选**。快捷键键盘不需要段落反馈，线性轴触发最干脆 |
| **Choc 茶轴（Tactile）** | 有轻微段落感 | 如果你喜欢"按下去有确认感" |
| **Choc 白轴（Click）** | 有明显咔哒声 | 不建议——办公室会吵到人 |

**力度建议**：选 **轻力度版本**（35-40g）。快捷键键盘需要高频快速点按，轻力度能显著降低手指疲劳。

### 2.3 键帽配套（★ 已改为自己 3D 打印）

**结论：键帽不用买，直接用项目里的 CAD 模型打印。**

原因：本项目是**三行五列非标布局**，空格跨 4 格、回车跨 2 格，市面上的 Choc 键帽套装根本不匹配。而且 Choc 生态的**大键（2u 以上）键帽极其难买**。

所以项目已产出可打印的键帽模型（`cad/keycap.scad`）：

| 键帽 | 文件 | 数量 | 打印耗时 |
|---|---|---|---|
| 1u 标准 | `03_keycap_1u.stl` | **9 个** | 约 12 min/个 |
| 2u 回车 | `04_keycap_2u.stl` | **1 个** | 约 20 min |
| 4u 空格 | `05_keycap_4u.stl` | **1 个** | 约 35 min |

键帽内部已做 **3 条加强筋**（4u）和 **3 个榫头**（对应空格下方的 3 个轴），解决长键翘曲问题。

> 改用 Choc **V2** 后轴心是 MX 十字，**1u 键帽可直接买市售 MX 矮键帽**；
> 但 2u/4u 仍基本买不到，还是得打印。

### 2.4 大键的机械问题（重要）

空格跨 4 格 = 约 70mm 宽。**这么长的键按两端会翘，中间没支撑**。解决方案：

| 方案 | 说明 | 推荐度 |
|---|---|---|
| **多点支撑** | 在空格下方放 **3 个轴体**（左中右各一），三个轴并联到同一个开关电路 | ⭐⭐⭐⭐⭐ **推荐** |
| 卫星轴 / 平衡杆 | 传统大键方案，但 Choc 矮轴配套的卫星轴难找 | ⭐⭐ |
| 单轴 + 长键帽 | 按两端会翘，手感差 | ❌ 不推荐 |

**采购要点**：空格位置按 **3 个轴体**买（多备 2 个），PCB 上对应位置要留 3 个轴的焊盘。

---

## 三、最小验证集（第 1 步，建议先买这些）

**目的**：花最少的钱，验证三个关键技术点。

| 技术点 | 验证内容 |
|---|---|
| BLE 连接 | 主控能否与电脑配对，并稳定发送按键 |
| ZMK 自定义 | 能否自定义按键映射、实现长按/双击手势 |
| 拨杆识别 | 拨动开关能否被主控读取到状态变化 |

### 3.1 最小验证清单

| # | 物品 | 规格要求 | 数量 | 用途 |
|---|---|---|---|---|
| 1 | **NoLogo ProMicro NRF52840 主控** | nRF52840 芯片，Pro Micro 引脚兼容，带锂电池充电管理 | **1 块** | 核心主控 |
| 2 | **BLE 锂电池** | 3.7V，**容量 300-500mAh**，带 JST 1.25 插头，注意尺寸要小 | 1 块 | 供电 |
| 3 | **矮轴 Choc V2 红轴（PG1353）** | 50±10gf | **6 个** | 测试用，多买当备用 |
| 4 | **1N4148 二极管** | 直插或贴片均可 | **10 个** | 面包板上搭真矩阵，验证 col2row 接线方向 |
| 5 | **拨动开关** | **SPDT 三脚**（不是自复位按钮），**轴套长度 ≥9mm** | **2 个** | 审批拨杆验证，多买备用 |
| 6 | **杜邦线 / 飞线** | 母对母、公对母各一扎 | 各 1 扎 | 接线测试 |
| 7 | **面包板** | 标准 400 孔 | 1 块 | 免焊接验证 |
| 8 | **USB-C 数据线** | 支持数据传输（不是纯充电线） | 1 条 | 刷固件用 |
| 9 | **Choc 1u 键帽** | 矮轴专用 | 6 个 | **可选** —— 不急可以自己打印 |

> ⚠️ **USB 线要注意**：必须是**数据线**，纯充电线无法刷固件。这是新手最常见的坑。
>
> ⚠️ **拨杆轴套要 ≥9mm**：外壳壁 2.4 + 凸台 4.1 + 螺母 2.0 = 8.5mm，买短了装不上。

**最小验证集的成本控制**：以上约 6 个轴 + 1 块主控 + 10 个二极管，是验证三件事的最低配置。

---

## 四、完整原型清单（第 2 步，验证通过后买）

### 4.1 电子部分

| # | 物品 | 规格要求 | 数量 | 备注 |
|---|---|---|---|---|
| 1 | **NoLogo ProMicro NRF52840 主控** | nRF52840，Pro Micro 兼容 | 1 块 | 已有可不重复买 |
| 2 | **BLE 锂电池** | 3.7V，**400–500mAh**，厚 **≤4.0mm**，带引线（焊到主控 B+/B− 焊盘） | 1 块 | **注意测量键盘内部空间** |
| 3 | **Choc V2 矮轴（PG1353）** | 红轴 50±10gf | **17 个** | **共需 14 个**（9 单键 ×1 + 回车 2u ×2 + 空格 4u ×3），多买 3 个备用 |
| 4 | ~~Choc 键帽~~ | — | **0 个** | **不买** —— 用 `cad/output/03~05_*.stl` 自己打印（见 2.3） |
| 7 | **SPDT 拨动开关** | 三脚，带固定螺孔 | 2 个 | 审批拨杆，多买 1 个备用 |
| 8 | **二极管** | 1N4148（直插或贴片） | 20 个 | 键盘矩阵防鬼影，多备 |
| 9 | **电源开关** | 小型拨动开关 | 1 个 | 总电源控制 |
| 10 | **复位按钮** | 轻触开关 | 2 个 | 主控刷机用 |
| 11 | ~~排针 / 排母~~ | — | **0 套** | ⚠️ **不能用**：主控装在 PCB **背面**，那层只有 5.0mm，主控本体 3.2 + 排母 2.54 = **5.74mm 超了**，必须**直焊** |
| 12 | **细导线** | 漆包线 0.3mm 或 30AWG 硅胶线 | 1 卷 | 手工布线 |

### 4.2 结构部分

| # | 物品 | 规格要求 | 数量 | 备注 |
|---|---|---|---|---|
| 13 | **定位板（轴板）** | 3D 打印 | 1 块 | 固定轴体，**11 键 / 14 个轴孔**；用 `02_plate.stl` |
| 14 | **外壳 / 底座** | 3D 打印 或 亚克力 | 1 套 | 容纳主控、电池、拨杆 |
| 15 | **脚垫** | 硅胶防滑垫 | 4 个 | 防滑 |
| 16 | **螺丝 / 铜柱** | M2 或 M3 | 1 套 | 固定结构 |

**关于定位板和外壳**：原型阶段建议 **3D 打印**（如果有打印机或找代打），比激光切割亚克力便宜且改版快。布局还可能调整，3D 打印改起来成本低。

### 4.3 工具部分（如果家里没有）

| # | 物品 | 规格要求 | 备注 |
|---|---|---|---|
| 17 | **电烙铁** | 可调温，建议 60W 以上，配细尖头 | 必备 |
| 18 | **焊锡丝** | 0.6mm 含铅（好焊）或 0.8mm 无铅 | 必备 |
| 19 | **助焊剂 / 松香** | — | 必备 |
| 20 | **吸锡带 / 吸锡器** | — | 拆焊用，必备 |
| 21 | **镊子** | 防静电尖头 | 必备 |
| 22 | **斜口钳 / 剪线钳** | 小号 | 必备 |
| 23 | **万用表** | 带通断测试功能 | 必备，排查线路 |
| 24 | **热风枪** | 可选 | 贴片焊接才需要 |
| 25 | **放大镜 / 台灯** | 带放大功能 | 可选，焊接细线时有用 |

---

## 五、可选增强件

| 物品 | 用途 | 是否值得 |
|---|---|---|
| **WS2812 RGB 灯珠** | 每键独立灯效，实现权限档位状态指示 | ⭐⭐⭐ **值得**——状态指示是产品核心设计 |
| **I2C OLED 小屏** | 显示当前权限档位/模型名文字 | ⭐⭐ 看需求，但增加厚度和功耗 |
| **蜂鸣器** | 拨杆切换时声音反馈 | ⭐⭐ 低成本，体验加分 |
| **防静电手环** | 焊接保护 | ⭐⭐⭐ 如果你住的地方干燥，建议买 |
| **热缩管** | 线材绝缘处理 | ⭐⭐⭐ 便宜好用 |

---

## 六、采购注意事项（避坑）

### 6.1 主控相关

| 坑 | 说明 |
|---|---|
| **主控是否带充电管理** | nice!nano 自带，但一些廉价替代板**不带**，需另配 TP4056 充电模块 |
| **引脚定义是否兼容** | 买"Pro Micro 引脚兼容"版本，否则 ZMK 配置要用别人写好的板子定义 |
| **是否已烧 bootloader** | 买标注"已烧录 bootloader"的，否则要先烧 bootloader 才能用 |
| **芯片年份** | ⚠️ 市面 nice!nano 多为 **2020 年产芯片，容易坏**（EPPad 作者也提到）。尽量买正品 |
| **别选 ESP32 系** | ESP32-WROOM-32 **开发板厚 10mm**（键盘装不进）；纯模组引脚间距 **1.27mm**（洞洞板焊不了）；**跑不了 ZMK**；续航约为 nRF52840 的 **1/10**。详见 `docs/PCB设计规格书.md` §14.4.1 |
| **想省钱可以选** | **NoLogo ProMicro NRF52840**（约 20–30 元）—— Pro Micro 引脚兼容、2.54mm 通孔、能跑 ZMK、低功耗。**本项目已选这块** |

> **✅ 主控选型已定稿（2026-09-16）**：选定 **NoLogo ProMicro NRF52840**（原名 SuperMini NRF52840）。
> 它 17.78 × 33.00mm，与官方 nice!nano 尺寸一致、Pro Micro 引脚兼容、能跑 ZMK，且比正品便宜。
>
> ⚠️ 它在原 86×50 的板面上**放不下**（正面被 14 个轴体占满），所以**装在 PCB 背面右侧**；
> PCB 同时加宽到 98mm 解决 USB 口够不到右壁的问题。
> 详见 `docs/PCB设计规格书.md` §14。
>
> **它有两点和官方 nice!nano 不同，采购时要留意**：
> 1. **没有复位按钮** —— 进 bootloader 要「0.5s 内短接 2 次 RST 到 GND」，需外接轻触开关（见第四章第 10 项）
> 2. **电池接口是 B+ / B− 焊盘，不是 JST 插座** —— 买带引线的电池直接焊上去

### 6.2 电池相关

| 坑 | 说明 |
|---|---|
| **插头规格** | JST 1.25 是主流，但有些是 JST 2.0，**买前确认主控的插座规格** |
| **尺寸** | 一定要**量好键盘内部空间**再买，电池买大了装不进去 |
| **保护板** | 买**带保护板**的电池，防过充过放 |

### 6.3 拨动开关相关

| 坑 | 说明 |
|---|---|
| **SPDT vs 自复位** | 必须买**SPDT 拨动开关**（拨过去停住），**不是**自复位按钮（松开回弹） |
| **轴套长度** | **必须 ≥ 9mm**。外壳壁 2.4 + 凸台 4.1 + 螺母 2.0 = 8.5mm，还要留余量。买短了装不上 |
| **轴套直径** | 默认按 φ6.0 建模（M6 螺纹），买前量一下，不对就改 `params.scad` 的 `SW_BUSH_D` |
| **引脚数** | 三脚（COM/NO/NC）最灵活 |

> 买回来先量三个尺寸：**轴套直径 / 轴套长度 / 面板尺寸**，对不上就改 `cad/lib/params.scad` 里对应的 `SW_*` 参数，然后跑 `python tools/check_dims.py` 复验（脚本会检查轴套能否穿过壁+凸台+螺母）。

### 6.4 轴体相关

| 坑 | 说明 |
|---|---|
| **Choc 版本** | 本项目用 **V2（PG1353）**。V1 与 V2 的**电气引脚位置相同**，但轴心（V1 小十字 / V2 MX 十字）、键程（3.0 / 3.2）、PCB 中心孔（3.0 / 5.0）都不同 → **键帽互不通用**，买前确认 |
| **键帽兼容** | Choc 键帽**不能**用在 MX 轴上，反之亦然，别买错 |
| **大键键帽** | ~~极难买~~ → **已解决**：本项目提供可打印的 2u/4u 键帽模型，见 2.3 |

### 6.5 USB 线相关

**必须是数据线**。市面上大量线材是"纯充电线"（只有电源针脚，没有数据针脚），插上去电脑不认设备，刷不了固件。买时确认标注"数据线"或"支持传输"。

---

## 七、采购渠道建议

| 类型 | 渠道 | 说明 |
|---|---|---|
| **主控 / 轴体 / 键帽** | 淘宝（搜"nice!nano"、"choc 矮轴"） | 最全，价格透明 |
| **电子元器件**（二极管、开关、排针） | **立创商城 / 嘉立创** | 正品保障，规格清晰，适合批量 |
| **PCB 打样**（第 3 步用） | **嘉立创** | 便宜，5 片起，学生价更低 |
| **3D 打印** | 淘宝代打 / 本地打印店 | 按体积计费 |
| **工具** | 淘宝 / 京东 | 电烙铁建议买好评多的套装 |

---

## 八、预算估算框架

由于不标具体价格，给出**构成比例**供参考：

| 类别 | 占比（大致） | 说明 |
|---|---|---|
| 主控 + 电池 | 25-30% | 单价最高的电子件 |
| 轴体 + 键帽 | 25-30% | 数量多，累计成本高 |
| 拨杆 + 元器件 | 5-10% | 便宜 |
| 结构件（定位板/外壳） | 10-15% | 取决于打印/切割方式 |
| 工具 | 20-30% | **一次性投入，后续项目可复用** |

**省钱建议**：
1. **先买最小验证集**（第三章），验证通过再投完整清单
2. **工具是长期投资**——如果以后还会做硬件，别买最便宜的
3. **定位板/外壳先用 3D 打印**，等布局定稿再考虑更正式的方式

---

## 九、购买顺序建议（推荐执行）

```
第 1 天 │ 下单「最小验证集」（第三章 8 项）
       │
第 1 周 │ 收到后验证：BLE 连接 → ZMK 自定义 → 拨杆识别
       │
       │ ✅ 三项都通过 → 进入第 2 步
       │ ❌ 某项失败 → 先解决，不要急着买完整清单
       │
第 2 周 │ 下单「完整原型清单」（第四章）
       │
第 3 周 │ 焊接组装，做出第一台能用的 ClaudePad
       │
第 4 周 │ 实测手感，调整布局，然后考虑打 PCB
```

---

## 十、本清单的边界说明

**本清单不包含：**

- ❌ **上位机软件部分**——审批拨杆要配合的桌面程序（读取终端输出/写 hooks）是**软件工作**，不需要采购
- ❌ **具体价格**——请以实时报价为准
- ❌ **具体购买链接**——型号规格已给全，按规格搜索即可；链接易失效，不如给规格

**本清单的假设：**

- 你有基本的焊接能力（或愿意学）
- 你能接触 3D 打印（自己打印或找代打）
- 你的电脑支持蓝牙（BLE 4.0 以上，现在电脑基本都支持）

---

> 📘 **第一次做硬件？** 看 `docs/新手采购清单.md` —— 面向新手重写的一版，
> 只列必需项，逐项说明用途和规格，并标注了容易买错的坑（比如二极管要买直插不要贴片）。

## 十一、想跳过验证、直接开干？

**可以。** 但要知道代价，以及有一件事绕不过去。

### 11.1 跳过的代价

| 跳过什么 | 代价 |
|---|---|
| 面包板验证 BLE / ZMK / 拨杆 | 如果哪里不通，会在**焊完之后**才发现，拆起来麻烦 |
| 校准试件 | ⚠️ **不建议跳过** —— 见 11.2 |

**如果决定跳过**，那就一次买齐下面这份。

### 11.2 ★ 唯一不建议跳过的事：校准试件

`SWITCH_PLATE_GAP`（PCB 上表面 → 定位板下表面）是**唯一无法从公开资料确定的尺寸**。
Choc 官方没公开，社区实测在 3.5–6.0mm 浮动。

**它错 0.5mm 会怎样**：

- 定位板位置错 → 轴体卡扣扣不上定位板 → 定位板固定不住
- 而外壳内腔高度 = `PCB_STANDOFF_H + PCB_T + SWITCH_PLATE_GAP`
  → 这个值错了，**整个外壳（3–4 小时打印）要重打**

**两个解法，任选其一，都很快**：

| 方法 | 耗时 | 说明 |
|---|---|---|
| **A. 打校准试件** | 15 分钟打印 | `cad/output/00_test_coupon.stl`，3 个测试位，轴体插进去找「卡扣清脆」那个 |
| **B. 卡尺量实物** | 5 分钟 | 拿到轴体后，把轴体压平在桌面上，量「轴体底面 → 卡扣下沿」的距离 |

> **建议**：下单当天就把校准试件丢去打印（或找代打），和等快递**并行**，不占额外时间。

### 11.3 跳过验证版：一次买齐

```
【主控】
□ NoLogo ProMicro NRF52840（Pro Micro 引脚兼容，自带充电管理） × 1
   ⚠️ 没有复位按钮 → 另需轻触开关；电池焊盘是 B+/B− 不是插座

【轴体】
□ 凯华 Choc 红轴 轻力度（35-40g） × 17（需 14，备 3）

【电子件】
□ 1N4148 二极管 × 20
□ SPDT 拨动开关（三脚，非自复位，轴套长 ≥9mm） × 2
□ 电源开关（小型拨动） × 1
□ 复位轻触开关 × 2
□ 3.7V 锂电池 400-500mAh，厚 ≤4.0mm，JST 1.25，带保护板 × 1

【连线】
□ 30AWG 漆包线 或 硅胶细线 × 1 卷
□ 洞洞板 ≥90 × 54mm × 1（走洞洞板路线才需要）

【结构件】
□ M2 × 6mm 自攻螺丝 × 6（多备）
□ 硅胶脚垫 φ8mm × 4
□ 双面泡棉胶 0.6mm × 1 片

【工具】（家里没有才买）
□ 可调温电烙铁 + 细尖头  □ 焊锡丝 0.6mm  □ 助焊剂 / 松香
□ 吸锡带 或 吸锡器        □ 防静电镊子    □ 斜口钳
□ 万用表（带通断测试）     □ 热缩管        □ 防静电手环
```

**不用买、自己打印的**：定位板 · 外壳 · 键帽（1u ×9 / 2u ×1 / 4u ×1）· 校准试件

### 11.4 买到之后怎么走

| 步 | 做什么 | 依赖 |
|---|---|---|
| 1 | 打印**校准试件** → 测出 `SWITCH_PLATE_GAP` 回填 `params.scad` | 需要轴体到手 |
| 2 | 重跑 `python tools/check_dims.py`，确认全绿 | 上一步 |
| 3 | ✅ 主控方案已定（装 PCB 背面）—— 直接按当前 `params.scad` 打印即可 | — |
| 4 | 打印定位板 → 键帽 → 外壳 | 2、3 步 |
| 5 | 焊二极管 + 飞线矩阵（按 `pcb/wiring.svg`） | 打印件就位 |
| 6 | 刷 ZMK 固件（`firmware/`） | — |
| 7 | 接主控、拨杆、电池，装壳 | 全部 |

> ⚠️ **但校准件仍不能跳**：`SWITCH_PLATE_GAP` 决定外壳内腔高度，
> 错了要重打 3–4 小时的外壳。见 §11.2。

---

## 附：一页速查（打印出来照着买）

### 第 1 批：最小验证集 —— 现在就买

**目的**：花最少的钱验证三件事 —— BLE 能否连上 / ZMK 能否自定义 / 拨杆能否被识别

```
□ NoLogo ProMicro NRF52840 主控 × 1
□ 3.7V 锂电池 300-500mAh（JST 1.25） × 1
□ 凯华 Choc 红轴 轻力度 × 6
□ 1N4148 二极管 × 10              ← 面包板上搭真矩阵，验证 col2row 接线
□ SPDT 拨动开关（非自复位，轴套长 ≥9mm） × 2
□ 杜邦线（母对母 / 公对母）各 × 1 扎
□ 面包板 400 孔 × 1
□ USB-C 数据线（必须是数据线） × 1
□ Choc 1u 键帽 × 6                ← 可选；不急可以自己打印
```

### 现在同时做（不用买）

```
□ 打印校准试件 cad/output/00_test_coupon.stl（15 分钟）
   → 测出 SWITCH_PLATE_GAP —— 这是整个项目唯一的阻塞项
   → 有打印机自己打；没有找淘宝代打（几块钱）
```

### 第 2 批：完整原型补充 —— 验证通过后再买

```
□ Choc 矮轴 × 17（共需 14：9 单键 + 回车 2 + 空格 3，多备 3 个）
□ 3.7V 锂电池 400-500mAh 厚≤4.0mm（JST 1.25，带保护板） × 1
□ 1N4148 二极管 × 20
□ 电源开关 × 1
□ 复位轻触开关 × 2
□ 细导线 30AWG × 1 卷
□ M2 × 6mm 自攻螺丝 × 6（固定定位板，多备）
□ 硅胶脚垫 φ8mm × 4
□ 双面泡棉胶 0.6mm × 1 片（固定电池）
□ WS2812 RGB 灯珠 × 若干
```

### ⛔ 不要买（会白花钱）

| 不要买 | 原因 |
|---|---|
| **键帽（2u / 4u）** | 市面基本买不到 Choc 大键帽；用 `cad/output/03~05_*.stl` 自己打印 |
| **定位板 / 外壳** | 用 `cad/output/01~02_*.stl` 自己打印 |
| **排针 / 排母** | PCB 上方只有 5.0mm 净空，**主控必须直焊**，排母装不进去 |
| **热插拔轴座** | 轴座在 PCB 下方凸出 2.5–3.0mm，而该层只有 5.0mm、电池已占 4.6mm —— **必然干涉** |
| **成品 PCB** | 市面无符合本布局的板（空格中间轴 x=40 不在 18mm 网格上），见 `docs/PCB设计规格书.md` §13 |

### 工具（家里没有就买）

```
□ 可调温电烙铁 + 细尖头
□ 焊锡丝 0.6mm
□ 助焊剂 / 松香
□ 吸锡带 或 吸锡器
□ 防静电镊子
□ 斜口钳
□ 万用表（带通断测试）
□ 热缩管
□ 防静电手环（干燥地区建议）
```

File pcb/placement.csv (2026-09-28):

# ClaudePad 元件坐标表（供 KiCad 放置用）
# 由 tools/gen_pcb.py 从 cad/lib/params.scad 生成 —— 勿手改
# 板子外形 98.0 × 50.0 mm，厚 1.6 mm
#
# 坐标系：板左下角为原点
#   x_mm / y_mm        本设计坐标系（Y 向上）
#   x_kicad / y_kicad  KiCad 坐标系（Y 向下），y_kicad = 板高 − y_mm
#
# 轴体旋转角：Choc 轴体封装默认 0°，本设计全部正向放置
ref,type,label,matrix,x_mm,y_mm,x_kicad,y_kicad,rotation,note
SW1,switch,PERM,ROW1xCOL1,13.00,7.00,13.00,43.00,0,PERM
SW2,switch,UP,ROW1xCOL2,31.00,7.00,31.00,43.00,0,UP
SW3,switch,MODEL,ROW1xCOL3,49.00,7.00,49.00,43.00,0,MODEL
SW4,switch,CMD,ROW1xCOL4,67.00,7.00,67.00,43.00,0,CMD
SW5,switch,STOP,ROW1xCOL5,85.00,7.00,85.00,43.00,0,STOP
,toggle,APPROVE,ROW1xCOL6,,,,,,SPDT 拨动开关；位置见外壳右壁，不在主矩阵区
SW6,switch,LEFT,ROW2xCOL1,13.00,25.00,13.00,25.00,0,LEFT
SW7,switch,DOWN,ROW2xCOL2,31.00,25.00,31.00,25.00,0,DOWN
SW8,switch,RIGHT,ROW2xCOL3,49.00,25.00,49.00,25.00,0,RIGHT
SW9,switch,ENTER,ROW2xCOL4,67.00,25.00,67.00,25.00,0,ENTER（1/2 并联到同一矩阵点）
SW10,switch,ENTER,ROW2xCOL4,85.00,25.00,85.00,25.00,180,ENTER（2/2 并联到同一矩阵点）
SW11,switch,SPACE,ROW3xCOL1,13.00,43.00,13.00,7.00,0,SPACE（1/3 并联到同一矩阵点）
SW12,switch,SPACE,ROW3xCOL1,40.00,43.00,40.00,7.00,0,SPACE（2/3 并联到同一矩阵点）
SW13,switch,SPACE,ROW3xCOL1,67.00,43.00,67.00,7.00,0,SPACE（3/3 并联到同一矩阵点）
SW14,switch,VOICE,ROW3xCOL5,85.00,43.00,85.00,7.00,180,VOICE
# 二极管：型号 1N4148，阳极接列线、阴极接行线（col2row）
# 位置在行间走廊（y=16 / y=34），已避开支撑台与缺口（2026-09-26 固化）
ref,type,matrix,x_mm,y_mm,x_kicad,y_kicad,rotation,note
D1,diode,ROW1xCOL1,6.00,16.00,6.00,34.00,0,PERM；阳极→COL1，阴极→ROW1
D2,diode,ROW1xCOL2,16.50,16.00,16.50,34.00,0,UP；阳极→COL2，阴极→ROW1
D3,diode,ROW1xCOL3,27.00,16.00,27.00,34.00,0,MODEL；阳极→COL3，阴极→ROW1
D4,diode,ROW1xCOL4,47.26,16.00,47.26,34.00,0,CMD；阳极→COL4，阴极→ROW1
D5,diode,ROW1xCOL5,57.58,16.00,57.58,34.00,0,STOP；阳极→COL5，阴极→ROW1
D6,diode,ROW1xCOL6,67.90,16.00,67.90,34.00,0,APPROVE；阳极→COL6，阴极→ROW1
D7,diode,ROW2xCOL1,6.00,34.00,6.00,16.00,0,LEFT；阳极→COL1，阴极→ROW2
D8,diode,ROW2xCOL2,16.50,34.00,16.50,16.00,0,DOWN；阳极→COL2，阴极→ROW2
D9,diode,ROW2xCOL3,27.00,34.00,27.00,16.00,0,RIGHT；阳极→COL3，阴极→ROW2
D10,diode,ROW2xCOL4,57.58,34.00,57.58,16.00,0,ENTER；阳极→COL4，阴极→ROW2
D11,diode,ROW3xCOL1,47.26,34.00,47.26,16.00,0,SPACE；阳极→COL1，阴极→ROW3
D12,diode,ROW3xCOL5,67.90,34.00,67.90,16.00,0,VOICE；阳极→COL5，阴极→ROW3

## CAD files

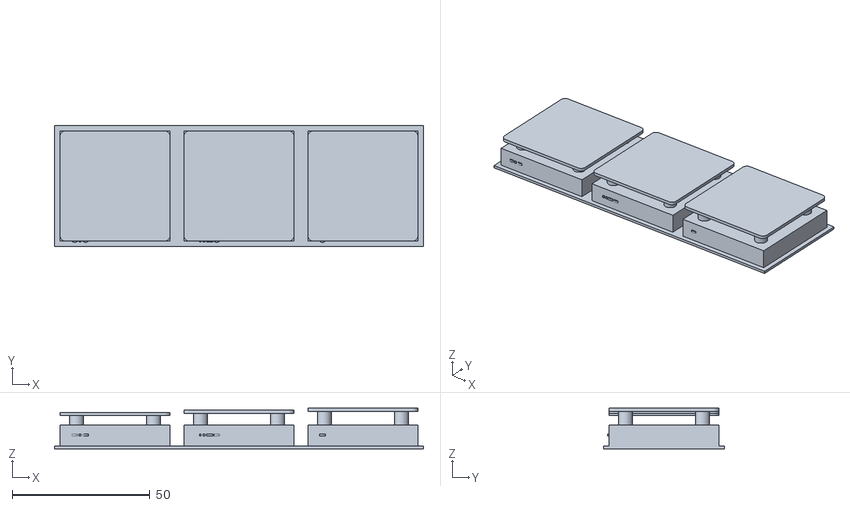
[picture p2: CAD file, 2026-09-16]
cad/output/00_test_coupon.stl
134.0 x 44.0 x 14.8

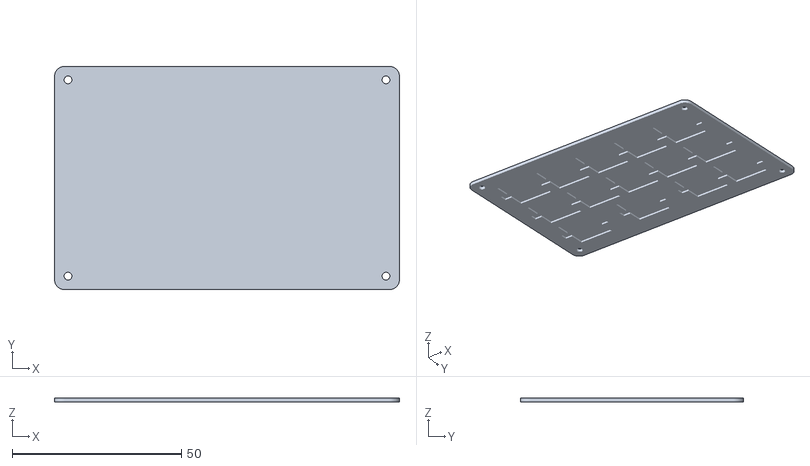
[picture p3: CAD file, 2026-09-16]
cad/output/02_plate.stl
102.0 x 66.0 x 1.20

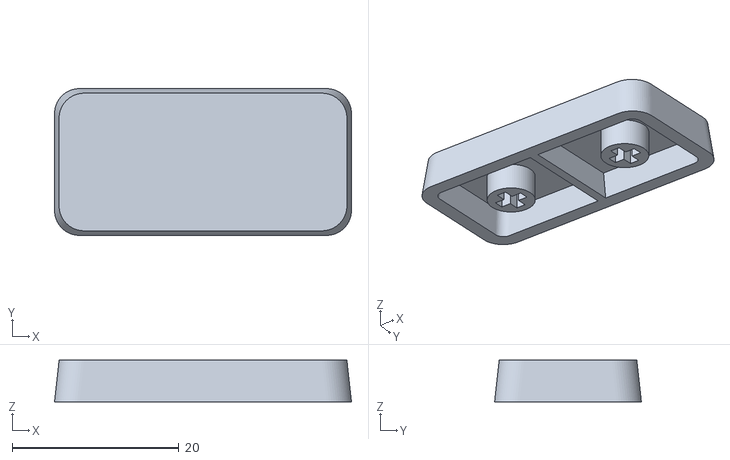
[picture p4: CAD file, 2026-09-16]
cad/output/04_keycap_2u.stl
35.6 x 17.6 x 5.00

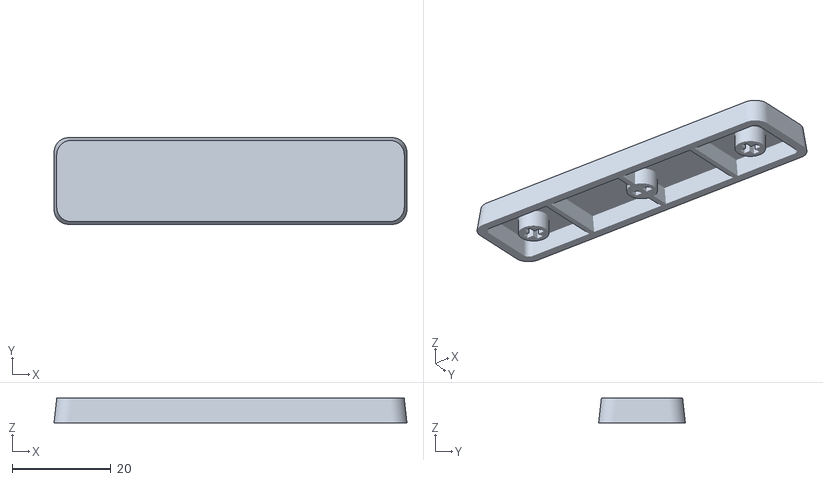
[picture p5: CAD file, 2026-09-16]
cad/output/05_keycap_4u.stl
71.6 x 17.6 x 5.00

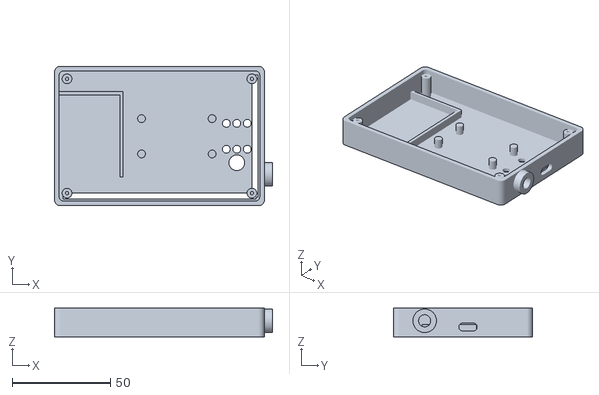
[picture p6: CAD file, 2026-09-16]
cad/output/01_case_bottom.stl
111.2 x 71.1 x 14.6

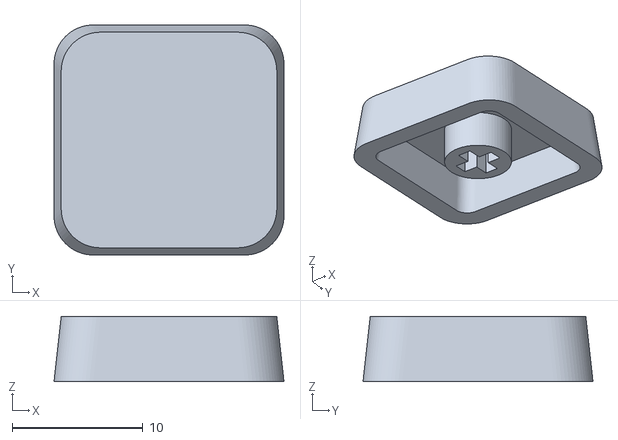
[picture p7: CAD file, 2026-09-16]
cad/output/03_keycap_1u.stl
17.6 x 17.6 x 5.00

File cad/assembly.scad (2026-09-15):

// =============================================================================
// ClaudePad · 总装与导出 (assembly.scad)
// -----------------------------------------------------------------------------
// 用途：
//   1. 爆炸视图预览（检查装配关系与干涉）
//   2. 一键导出所有零件（配合 OpenSCAD CLI 或 tools/export_stl.py）
//
// 命令行导出示例（在 cad/ 目录执行）：
//   openscad -o output/01_case_bottom.stl case_bottom.scad
//   openscad -o output/02_plate.stl plate.scad
//   openscad -D 'keycap_mode="1u"' -o output/03_keycap_1u.stl keycap.scad
//   openscad -D 'keycap_mode="2u"' -o output/04_keycap_2u.stl keycap.scad
//   openscad -D 'keycap_mode="4u"' -o output/05_keycap_4u.stl keycap.scad
//   openscad -o output/06_test_coupon.stl test_coupon.scad
// =============================================================================

include <lib/params.scad>
use <plate.scad>
use <case_bottom.scad>
use <keycap.scad>

// ---------- 派生高度（与各零件保持一致）----------------------------------
CASE_INNER_W = PLATE_W + CASE_TOP_TOL * 2;
CASE_INNER_D = PLATE_H + CASE_TOP_TOL * 2;
CASE_W = CASE_INNER_W + CASE_WALL * 2;
CASE_D = CASE_INNER_D + CASE_WALL * 2;

PLATE_BOTTOM_Z = CASE_BOTTOM_T + CASE_INNER_H;          // = 12.1
CAP_BOTTOM_Z = PLATE_BOTTOM_Z + PLATE_T + CAP_GAP;      // = 13.6
PCB_TOP_Z = CASE_BOTTOM_T + PCB_STANDOFF_H + PCB_T;     // = 8.6

// ---------- 装配预览 ------------------------------------------------------
module all_keycaps() {
    for (k = KEYMAP) {
        c = k[0]; r = k[1]; u = k[2];
        // 键帽中心 = 该键跨格范围中点（换算到外壳绝对坐标）
        translate([
            CASE_WALL + PLATE_BORDER + (c - 1) * PITCH + u * PITCH / 2,
            CASE_WALL + PLATE_BORDER + (r - 1) * PITCH + PITCH / 2,
            0
        ]) keycap(u);
    }
}

module assembly_exploded(explode = 0) {
    color("LightSteelBlue", 0.9) case_bottom();

    color("Khaki", 0.95)
        translate([CASE_WALL, CASE_WALL, PLATE_BOTTOM_Z + explode * 14])
            switch_plate();

    color("Salmon", 0.95)
        translate([0, 0, CAP_BOTTOM_Z + explode * 34])
            all_keycaps();
}

// ---------- 渲染控制 ------------------------------------------------------
VIEW = "explode";     // "explode" / "assembly" / "case" / "plate" / "caps"

if (VIEW == "explode") {
    assembly_exploded(1.0);
} else if (VIEW == "assembly") {
    assembly_exploded(0.0);
} else if (VIEW == "case") {
    case_bottom();
} else if (VIEW == "caps") {
    all_keycaps();
} else {
    switch_plate();
}

// ---------- 尺寸链自检（改参数后看这里）----------------------------------
echo("════════ ClaudePad 尺寸链 ════════");
echo(str("整机外形      : ", CASE_W, " × ", CASE_D, " × ", TOTAL_H, " mm"));
echo(str("底座          : ", CASE_W, " × ", CASE_D, " × ", CASE_OUTER_H, " mm"));
echo(str("定位板        : ", PLATE_W, " × ", PLATE_H, " × ", PLATE_T, " mm"));
echo(str("内腔净高      : ", CASE_INNER_H, " mm"));
echo(str("  ├ 电池/走线层 : ", PCB_STANDOFF_H, " mm"));
echo(str("  ├ PCB         : ", PCB_T, " mm"));
echo(str("  └ 轴体卡扣间隙: ", SWITCH_PLATE_GAP, " mm  ← 关键待验证"));
echo(str("定位板底面 z  : ", PLATE_BOTTOM_Z, " mm"));
echo(str("PCB 顶面   z  : ", PCB_TOP_Z, " mm"));
echo(str("键帽底面   z  : ", CAP_BOTTOM_Z, " mm"));
echo(str("键帽顶面   z  : ", CAP_BOTTOM_Z + CAP_H, " mm  ← 整机总高"));
echo(str("电池可用厚度  : ", PCB_STANDOFF_H - BATT_TAPE_T, " mm"));
echo(str("轴芯高出定位板: ", SWITCH_TIP_ABOVE_PLATE, " mm（榫槽深 ", CAP_STEM_DEPTH, " mm）"));

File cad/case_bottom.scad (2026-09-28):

// =============================================================================
// ClaudePad · 底座 / 外壳下壳 (case_bottom.scad)
// -----------------------------------------------------------------------------
// 结构：一个上开口的盒子。
//   · 内腔是直壁矩形，定位板从上方落入，与外壳上沿齐平
//   · 四角螺丝柱托住定位板（M2 螺丝从上往下拧）
//   · PCB 由 4 个矮支撑台托起，靠轴体+定位板压住固定
//   · 电池贴在底板中央（PCB 下方），四周有限位挡墙
//   · 右壁装 SPDT 审批拨杆
//
// 打印方向：底面朝下平放，无需支撑
// =============================================================================

include <lib/params.scad>

// ---------- 派生尺寸 ------------------------------------------------------
CASE_INNER_W = PLATE_W + CASE_TOP_TOL * 2;      // = 102.30
CASE_INNER_D = PLATE_H + CASE_TOP_TOL * 2;      // = 66.30
CASE_W = CASE_INNER_W + CASE_WALL * 2;          // = 107.10
CASE_D = CASE_INNER_D + CASE_WALL * 2;          // = 71.10

// 定位板底面高度（= 螺丝柱顶面 = 底板上表面 + 内腔高度）
PLATE_BOTTOM_Z = CASE_BOTTOM_T + CASE_INNER_H;  // = 13.60
PCB_TOP_Z = CASE_BOTTOM_T + PCB_STANDOFF_H + PCB_T;   // = 8.60
PCB_BOTTOM_Z = PCB_TOP_Z - PCB_T;                     // = 7.00（主控安装面）

// 拨杆位置（右壁）
SW_Y = 16.0;                                    // 拨杆中心纵向位置
SW_Z = CASE_BOTTOM_T + CASE_INNER_H * 0.55;     // 拨杆中心高度

// 主控位置（PCB 背面右侧）
// ★ 2026-09-16 方案 A：主控从 PCB 正面移到背面（下表面）
//   PCB 坐标系原点在外壳坐标 (PCB_X + CASE_WALL, PCB_Y + CASE_WALL)
NANO_X = PCB_X + CASE_WALL + NANO_POS_X;    // 绝对坐标
NANO_Y = PCB_Y + CASE_WALL + NANO_POS_Y;

// ---------- 通用工具 ------------------------------------------------------
module rounded_box(w, h, d, r) {
    linear_extrude(height = d)
        offset(r = r) offset(delta = -r)
            square([w, h]);
}

// ---------- 底座主体 ------------------------------------------------------
module case_shell() {
    difference() {
        // 外壳实体（底面做 0.2 倒角防大象脚）
        translate([0, 0, TOL_BOTTOM_CHAMFER])
            rounded_box(CASE_W, CASE_D, CASE_OUTER_H - TOL_BOTTOM_CHAMFER, CASE_RADIUS);
        translate([TOL_BOTTOM_CHAMFER, TOL_BOTTOM_CHAMFER, 0])
            rounded_box(
                CASE_W - TOL_BOTTOM_CHAMFER * 2,
                CASE_D - TOL_BOTTOM_CHAMFER * 2,
                TOL_BOTTOM_CHAMFER + 0.01,
                CASE_RADIUS - TOL_BOTTOM_CHAMFER
            );

        // 内腔（直壁，上开口）
        translate([CASE_WALL, CASE_WALL, CASE_BOTTOM_T])
            rounded_box(
                CASE_INNER_W,
                CASE_INNER_D,
                CASE_INNER_H + PLATE_T + 1,
                CASE_RADIUS - 1
            );
    }
}

// ---------- 四角螺丝柱（托住定位板）--------------------------------------
// 柱高 = 内腔高度（从底板上表面到定位板底面）
// ★ 向下多伸 FUSE_OVERLAP 与底板融合，避免共面产生非流形边
// 顶部开 M2 自攻底孔，深 6mm（留 4.5mm 不穿透底板）
module case_posts() {
    for (px = [0, 1], py = [0, 1]) {
        translate([
            px == 0 ? CASE_WALL + SCREW_INSET : CASE_W - CASE_WALL - SCREW_INSET,
            py == 0 ? CASE_WALL + SCREW_INSET : CASE_D - CASE_WALL - SCREW_INSET,
            CASE_BOTTOM_T - FUSE_OVERLAP
        ]) difference() {
            cylinder(d = POST_D, h = CASE_INNER_H + FUSE_OVERLAP);
            // M2 自攻底孔（从柱顶向下 6mm）
            translate([0, 0, CASE_INNER_H - 6.0 + FUSE_OVERLAP])
                cylinder(d = SCREW_M2_TAP, h = 6.5);
        }
    }
}

// ---------- PCB 支撑台 ----------------------------------------------------
// 4 个矮柱托起 PCB，高度 = PCB_STANDOFF_H
// ★ 位置取「轴体之间的空隙中央」，不能放四角（会顶住轴体塑料脚）
module pcb_supports() {
    ox = PCB_X + CASE_WALL;
    oy = PCB_Y + CASE_WALL;
    for (sx = [PCB_SUPPORT_X1, PCB_SUPPORT_X2],
         sy = [PCB_SUPPORT_Y1, PCB_SUPPORT_Y2]) {
        translate([ox + sx, oy + sy, CASE_BOTTOM_T - FUSE_OVERLAP])
            cylinder(d = PCB_SUPPORT_D, h = PCB_STANDOFF_H + FUSE_OVERLAP);
    }
}

// ---------- 电池仓 --------------------------------------------------------
// 电池用双面胶贴在底板上（PCB 正下方），四周限位挡墙防止滑动
// 挡墙高度受 PCB_STANDOFF_H 限制，不能顶到 PCB
//
// ★ 2026-09-16 改：电池从「居中」改为「贴左壁」
//   原因：主控移到 PCB 背面右侧后，支撑台必须占用中间的空隙中心（现为 x=40/76），
//         而居中的电池（原 PCB 坐标 x 28.15~58.15）正好盖住它们。
//   结果：电池 PCB 坐标 x −2~28，与支撑台（38~42 与 74~78）互不干涉。
BATT_X = CASE_WALL;                                 // 贴内腔左壁（原为居中）
BATT_Y = CASE_WALL + (CASE_INNER_D - BATT_L) / 2;   // 纵向仍居中
BATT_WALL_H = PCB_STANDOFF_H - BATT_TAPE_T;      // = 4.4，正好不顶 PCB

module battery_bay() {
    // 限位挡墙：右 + 上 两侧（左、下靠外壳内壁）
    // ★ 向下多伸 FUSE_OVERLAP 与底板融合
    translate([BATT_X + BATT_W + BATT_TOL, BATT_Y - BATT_TOL,
               CASE_BOTTOM_T - FUSE_OVERLAP])
        cube([1.60, BATT_L + BATT_TOL * 2, BATT_WALL_H + FUSE_OVERLAP]);
    translate([BATT_X - BATT_TOL, BATT_Y + BATT_L + BATT_TOL,
               CASE_BOTTOM_T - FUSE_OVERLAP])
        cube([BATT_W + BATT_TOL * 2 + 1.60, 1.60, BATT_WALL_H + FUSE_OVERLAP]);
}

// ---------- 走线通道 ------------------------------------------------------
// A：沿下缘横向（键位矩阵行线）
// B：沿右缘纵向（拨杆信号线 → 主控）
module wire_channels() {
    // A
    translate([CASE_WALL + 2, CASE_WALL + 1, CASE_BOTTOM_T - WIRE_CH_D])
        cube([CASE_INNER_W - 4, WIRE_CH_W, WIRE_CH_D + 0.01]);
    // B
    translate([CASE_W - CASE_WALL - 1 - WIRE_CH_W, CASE_WALL + 2, CASE_BOTTOM_T - WIRE_CH_D])
        cube([WIRE_CH_W, CASE_INNER_D - 4, WIRE_CH_D + 0.01]);
}

// ---------- 右壁：USB-C 开孔 ---------------------------------------------
// 主控装在 PCB 背面（下表面），USB 口朝右壁，开口是「横长」的槽（宽 > 高）
// ★ 2026-09-16 方案 A：开孔高度从「PCB 上表面上方」改到「PCB 下表面下方」
//
// ⚠️ 注意 rotate([0,90,0]) 之后：局部 X 轴 → 世界 Z 轴（垂直）
//    所以要沿「局部 Y 轴」偏移，才能得到水平方向的槽。
// 开孔高度随主控安装面自动切换（正面 / 背面）
// 主控的 USB 口在板边缘，开孔中心取「PCB 表面 ± 1.80」
USB_CUT_Z = NANO_ON_BACK ? PCB_BOTTOM_Z - 1.80 : PCB_TOP_Z + 1.80;

module usb_cutout() {
    d = NANO_USB_H + NANO_USB_TOL;                       // 槽高
    off = NANO_USB_W + NANO_USB_TOL - d;                 // 槽宽 - 槽高
    translate([CASE_W - CASE_WALL - 2, NANO_Y + NANO_L / 2, USB_CUT_Z])
        rotate([0, 90, 0])
            hull() {
                cylinder(d = d, h = CASE_WALL + 6);
                translate([0, off, 0]) cylinder(d = d, h = CASE_WALL + 6);
            }
}

// ---------- 右壁：拨杆凸台与开孔 -----------------------------------------
// 凸台是「壳外」的圆形加厚垫，用来给轴套提供额外咬合长度。
// 拨杆在壳外摆动，不需要在壳壁上开行程槽 —— 只需要一个轴套过孔。
module switch_boss() {
    // ★ 向壳内多伸 FUSE_OVERLAP 与侧壁融合
    translate([CASE_W - FUSE_OVERLAP, SW_Y, SW_Z])
        rotate([0, 90, 0])
            cylinder(d = SW_BOSS_D, h = SW_BOSS_T + FUSE_OVERLAP);
}

module switch_cutouts() {
    // 轴套过孔（贯穿 壁 + 凸台），两端各留 1mm 保证切透
    translate([CASE_W - CASE_WALL - 1, SW_Y, SW_Z])
        rotate([0, 90, 0])
            cylinder(d = SW_BUSH_D + TOL_HOLE, h = CASE_WALL + SW_BOSS_T + 2);
}

// ---------- 底面：脚垫沉孔 / 通气孔 / 复位孔 ------------------------------
module bottom_features() {
    // 脚垫沉孔（四角）
    for (px = [0, 1], py = [0, 1]) {
        translate([
            px == 0 ? FOOT_INSET : CASE_W - FOOT_INSET,
            py == 0 ? FOOT_INSET : CASE_D - FOOT_INSET,
            -0.1
        ]) cylinder(d = FOOT_D + TOL_HOLE, h = FOOT_DEPTH + 0.1);
    }

    // 通气孔（主控正下方，VENT_COLS × VENT_ROWS 阵列）
    for (ix = [0 : VENT_COLS - 1], iy = [0 : VENT_ROWS - 1]) {
        translate([
            NANO_X + NANO_W * (0.2 + 0.6 * ix / max(1, VENT_COLS - 1)),
            NANO_Y + NANO_L * (0.3 + 0.4 * iy / max(1, VENT_ROWS - 1)),
            -0.1
        ]) cylinder(d = BOTTOM_VENT_D, h = CASE_BOTTOM_T + 0.2);
    }

    // 复位按钮开孔（主控 reset 位置）
    translate([NANO_X + NANO_W / 2, NANO_Y + 3.0, -0.1])
        cylinder(d = 8.0, h = CASE_BOTTOM_T + 0.2);
}

// ---------- 装配体 --------------------------------------------------------
module case_bottom() {
    difference() {
        union() {
            case_shell();
            case_posts();
            pcb_supports();
            battery_bay();
            switch_boss();
        }
        usb_cutout();
        switch_cutouts();
        bottom_features();
        wire_channels();
    }
}

case_bottom();

// ---------- 尺寸自检 -------------------------------------------------------
echo("──────── 底座尺寸 ────────");
echo(str("外形   = ", CASE_W, " × ", CASE_D, " × ", CASE_OUTER_H, " mm"));
echo(str("内腔   = ", CASE_INNER_W, " × ", CASE_INNER_D, " × ", CASE_INNER_H, " mm"));
echo(str("定位板底面 z = ", PLATE_BOTTOM_Z, " ｜ PCB 顶面 z = ", PCB_TOP_Z));
echo(str("电池仓 高度限制 = ", BATT_WALL_H, " mm（电池 ", BATT_H, " + 胶 ", BATT_TAPE_T, "）"));
echo(str("螺丝柱外缘到轴孔余量 = ",
    (PLATE_BORDER + PITCH / 2 - (SWITCH_CUTOUT + SWITCH_CUTOUT_TOL) / 2)
    - (SCREW_INSET + POST_D / 2), " mm"));
echo(str("拨杆凸台：直径 ", SW_BOSS_D, " 厚 ", SW_BOSS_T,
         " ｜ z 范围 ", SW_Z - SW_BOSS_D / 2, " ~ ", SW_Z + SW_BOSS_D / 2,
         "（外壳高 ", CASE_OUTER_H, "）"));

// ---------- 打印建议 -------------------------------------------------------
// 方向：底面朝下平放，无需支撑
// 层高：0.20mm｜壁数：3｜填充：25%
// 材料：PETG 优先（韧性好），PLA 次选

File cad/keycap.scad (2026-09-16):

// =============================================================================
// ClaudePad · 键帽 (keycap.scad)
// -----------------------------------------------------------------------------
// 三类键帽：1u 标准 / 2u 回车 / 4u 空格
// Choc 矮轴专用（十字榫槽适配 Choc 轴芯 1.1 十字）
//
// 结构：薄壳（四壁 + 顶面）+ 中心榫头柱，底部开口
// 打印方向：顶面朝下（倒扣），榫头朝上 —— 榫槽精度最高，无需支撑
// =============================================================================

include <lib/params.scad>

// ---------- 榫头定位（必须与 plate.scad 的轴孔位置严格一致）---------------
// 键帽中心 = 该键跨格范围的中点，故第 i 个榫头相对中心的偏移为：
//   PITCH * (axis_offset(u,i) - u/2)
function kc_axis_count(u) = (u <= 1) ? 1 : ((u == 2) ? 2 : 3);
function kc_stem_offset(u, i) =
    PITCH * ((u <= 1) ? 0
                      : (0.5 + i * (u - 1) / (kc_axis_count(u) - 1) - u / 2));

// ---------- 圆角矩形截面（复用）------------------------------------------
module rrect(w, h, r) {
    offset(r = r) offset(delta = -r) square([w, h], center = true);
}

// ---------- 十字榫槽（从 z=0 向上开，深 CAP_STEM_DEPTH）-------------------
module cross_stem_socket() {
    union() {
        translate([-CAP_CROSS_L / 2, -CAP_CROSS_W / 2, 0])
            cube([CAP_CROSS_L, CAP_CROSS_W, CAP_STEM_DEPTH]);
        translate([-CAP_CROSS_W / 2, -CAP_CROSS_L / 2, 0])
            cube([CAP_CROSS_W, CAP_CROSS_L, CAP_STEM_DEPTH]);
    }
}

// ---------- 键帽外壳（薄壳：四壁 + 顶面，底部开口）----------------------
module cap_shell(u) {
    outer_w = PITCH * u - 0.40;
    outer_d = PITCH - 0.40;
    top_w = outer_w - CAP_TAPER * 2;
    top_d = outer_d - CAP_TAPER * 2;
    r_out = min(CAP_TOP_R, min(outer_w, outer_d) / 2 - 0.1);
    r_in = max(r_out - CAP_WALL, 0.2);

    difference() {
        // 外壳实体（下大上小的梯形）
        hull() {
            linear_extrude(height = 0.01) rrect(outer_w, outer_d, r_out);
            translate([0, 0, CAP_H - CAP_TOP_T])
                linear_extrude(height = CAP_TOP_T) rrect(top_w, top_d, r_out);
        }
        // 内腔（从底部开口一直挖到顶面下方，留 CAP_TOP_T 做顶）
        hull() {
            translate([0, 0, -1])
                linear_extrude(height = 0.01)
                    rrect(outer_w - CAP_WALL * 2, outer_d - CAP_WALL * 2, r_in);
            translate([0, 0, CAP_H - CAP_TOP_T])
                linear_extrude(height = 0.01)
                    rrect(top_w - CAP_WALL * 2, top_d - CAP_WALL * 2, r_in);
        }
    }
}

// ---------- 榫头柱 --------------------------------------------------------
module stem_boss() {
    h = CAP_H - CAP_TOP_T;
    difference() {
        cylinder(d = CAP_STEM_BOSS_D, h = h);
        translate([0, 0, -0.5]) cross_stem_socket();
    }
}

// ---------- 内部加强筋（大键防变形）--------------------------------------
module cap_ribs(u) {
    if (u >= 2) {
        outer_w = PITCH * u - 0.40;
        outer_d = PITCH - 0.40;
        n = (u == 2) ? CAP_RIB_COUNT_MED : CAP_RIB_COUNT_LONG;
        for (i = [1 : n]) {
            translate([
                -outer_w / 2 + outer_w * i / (n + 1) - CAP_RIB_T / 2,
                -outer_d / 2 + CAP_WALL,
                0
            ]) cube([CAP_RIB_T, outer_d - CAP_WALL * 2, CAP_H - CAP_TOP_T]);
        }
    }
}

// ---------- 完整键帽 ------------------------------------------------------
module keycap(u = 1) {
    union() {
        cap_shell(u);
        for (i = [0 : kc_axis_count(u) - 1]) {
            translate([kc_stem_offset(u, i), 0, 0]) stem_boss();
        }
        cap_ribs(u);
    }
}

// ---------- 渲染控制（改这里切换键帽规格）--------------------------------
keycap_mode = "1u";     // "1u" / "2u" / "4u"

if (keycap_mode == "1u") {
    keycap(1);
} else if (keycap_mode == "2u") {
    keycap(2);
} else {
    keycap(4);
}

// ---------- 尺寸自检 -------------------------------------------------------
echo(str("键帽：高 ", CAP_H, " ｜ 1u 外宽 ", PITCH - 0.40, " ｜ MX 十字榫槽 ", CAP_CROSS_L, "×", CAP_CROSS_W, " 深 ", CAP_STEM_DEPTH));
echo(str("装配校验：轴芯高出定位板 ", SWITCH_TIP_ABOVE_PLATE,
         " ≤ 间隙 ", CAP_GAP, " + 榫槽深 ", CAP_STEM_DEPTH, " = ", CAP_GAP + CAP_STEM_DEPTH));

// ---------- 打印建议 -------------------------------------------------------
// 方向：顶面朝下倒扣打印（榫头朝上），无需支撑
// 层高：0.12mm｜壁数：3｜填充：15%
// 材料：PLA（手感清脆）或 PETG（耐用）

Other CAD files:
cad/plate.scad
cad/test_coupon.scad

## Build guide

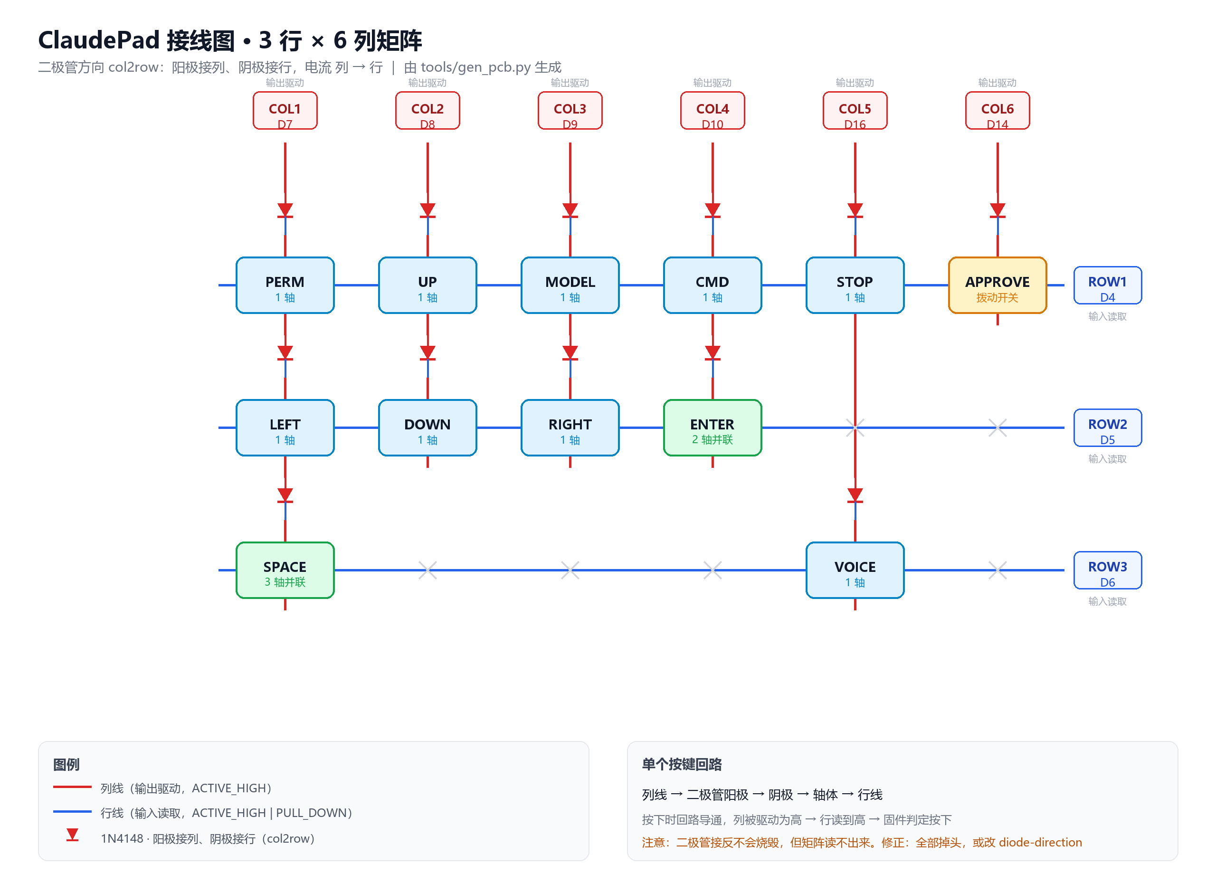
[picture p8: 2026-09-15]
pcb/wiring.png

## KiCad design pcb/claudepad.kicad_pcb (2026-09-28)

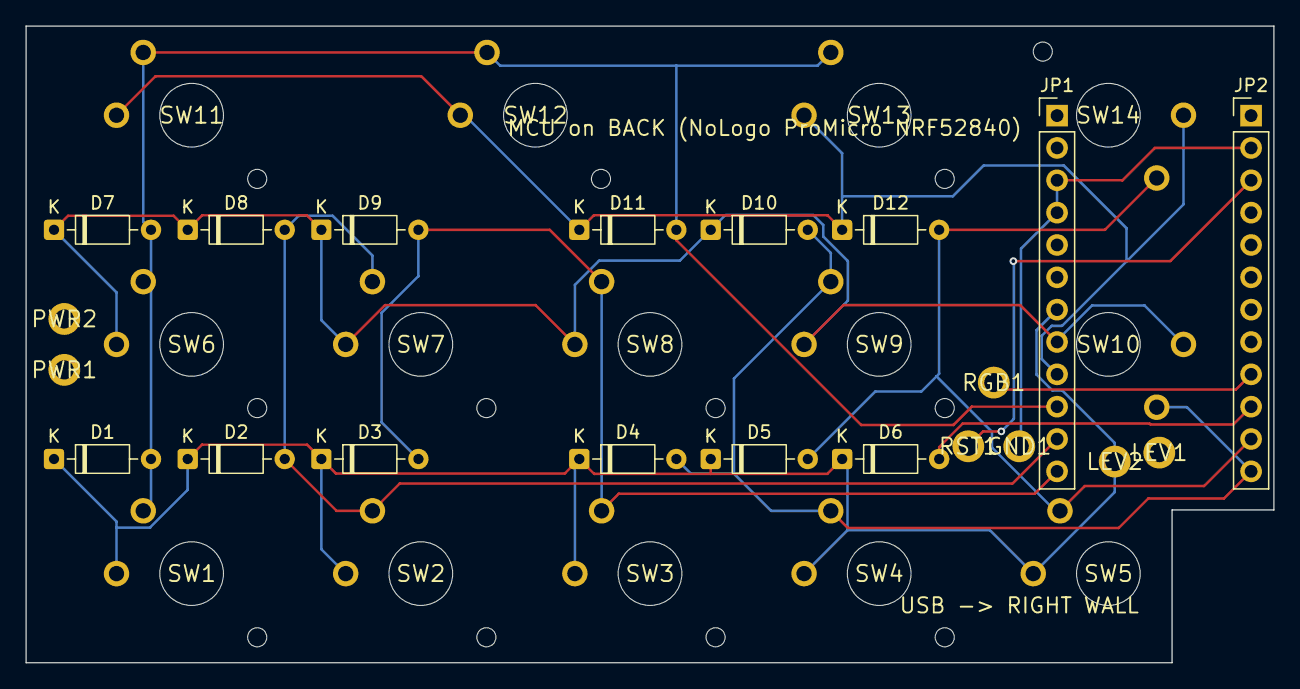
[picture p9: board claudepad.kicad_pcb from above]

Board: 2 copper layers, 98.0 x 50.0 mm, 35 parts (0 on the bottom side), 12 nets.

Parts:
D1, D2, D3, D4, D5, D6, D7, D8, D9, D10, D11, D12: 1N4148; D_DO-35_SOD27_P7.62mm_Horizontal
GND1: 复位按钮
JP1, JP2: MCU; PinHeader_1x12_P2.54mm_Vertical
LEV1: 拨杆 NO
LEV2: 拨杆 COM
PWR1, PWR2: 电源开关(飞线)
RGB1: D15 预留
RST1: 复位按钮
SW1, SW2, SW3, SW4, SW5, SW6, SW7, SW8, SW9, SW10, SW11, SW12, SW13, SW14: ChocV2

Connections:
COL1: D1.2, D7.2, D11.2, JP1.10, SW1.1, SW6.1, SW11.1, SW12.1, SW13.1
COL2: D2.2, D8.2, JP1.11, SW2.1, SW7.1
COL3: D3.2, D9.2, JP1.12, SW3.1, SW8.1
COL4: D4.2, D10.2, JP2.12, SW4.1, SW9.1, SW10.1
COL5: D5.2, D12.2, JP2.11, SW5.1, SW14.1
COL6: D6.2, JP2.10
GND: GND1.1, JP1.3, JP1.4, JP2.2
RGB_DIN: JP2.9, RGB1.1
ROW1: D1.1, D2.1, D3.1, D4.1, D5.1, D6.1, JP1.7, LEV2.1, SW1.2, SW2.2, SW3.2, SW4.2, SW5.2
ROW2: D7.1, D8.1, D9.1, D10.1, JP1.8, SW6.2, SW7.2, SW8.2, SW9.2, SW10.2
ROW3: D11.1, D12.1, JP1.9, SW11.2, SW12.2, SW13.2, SW14.2
RST: JP2.3, RST1.1

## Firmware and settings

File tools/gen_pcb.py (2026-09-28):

#!/usr/bin/env python3
# -*- coding: utf-8 -*-
"""
ClaudePad PCB 网表与接线图生成器
================================================================================
从 cad/lib/params.scad 读取键位表（单一数据源），生成：

  pcb/netlist.json  机器可读网表
  pcb/netlist.md    人读网表（焊接对照表）
  pcb/placement.csv 元件坐标表（供 KiCad 放置，改板用）
  pcb/wiring.svg    接线图（矢量，可打印放大）
  pcb/wiring.png    接线图（位图，快速预览）

绘图采用「一份布局描述 + 两个渲染后端」：所有图元先记录到 Canvas，
再分别由 SVG 和 Pillow 渲染，保证两张图内容完全一致。

关键数据（2026-09-21 改按凯华官方规格图 —— 此前依据的两个开源封装库**已发现有误**）：

  Kailh Choc **V2** (PG1353) PCB 封装（原点 = 轴芯中心）：
    物理引脚     3 根      ← PCB 要钻 3 个孔，一个都不能省
      其中金属电气脚 2 根  孔径 Ø1.20 PTH  ← ★ 官方图标注 `2-Ø1.20`，通电
      其中不通电定位脚 1 根 孔径 Ø1.60 NPTH ← 轴体第 3 脚，不导通
    轴芯中心孔   1 个       孔径 Ø5.00   ← 非金属化，让位给中央 Ø4.80 塑料凸台
    另有 1 个 LED 焊盘
    外形         15 × 15 × 5.3mm（图上另见底座外形 13.95 × 13.95）

  ★ 三根引脚坐标已落定并经实物确认（2026-09-26）：(0,5.9) 电气 / (5,-5.15) 电气 / (-5,3.8) 不通电定位。
    依据：官方图 5 个尺寸与 siderakb V1V2_THT_Hybrid 封装交叉吻合 + 用户万用表实测导通对确认。

  ★ 键程 3.2±0.25mm（官方）｜轴心 5mm MX 十字（V1 是 3.4mm 矩形小十字，键帽不通用）
    【来源】凯华 PG1353 官方规格图

  二极管方向 col2row：阳极接列、阴极接行，电流 列 → 行
    列 = 输出驱动（GPIO_ACTIVE_HIGH）
    行 = 输入读取（GPIO_ACTIVE_HIGH | GPIO_PULL_DOWN）

运行：python tools/gen_pcb.py
"""

import json
import os
import sys

sys.path.insert(0, os.path.dirname(os.path.abspath(__file__)))
from scad_params import load, load_keymap, find_project_root     # noqa: E402
from console_utf8 import enable                                  # noqa: E402

enable()

ROOT = find_project_root() or os.path.dirname(os.path.dirname(os.path.abspath(__file__)))
OUT = os.path.join(ROOT, "pcb")

P = load()
KEYMAP = load_keymap()

# ---- 引脚分配（必须与 firmware/.../claudepad.overlay 一致）------------------
ROW_PINS = ["D4", "D5", "D6"]
COL_PINS = ["D7", "D8", "D9", "D10", "D16", "D14"]
APPROVE_PIN = "D14"

# ---- Kailh Choc V2 (PG1353) PCB 封装（原点 = 轴芯中心，mm）------------------
# ★ 2026-09-21 按凯华官方规格图。以下三个数据已确认：
CHOC_PIN_COUNT = 3              # 物理引脚数（PCB 3 个孔，一个都不能省）
CHOC_ELEC_PIN_COUNT = 2         # 其中金属电气脚（官方图 `2-Ø1.20`，PTH，通电）
CHOC_ANCHOR_PIN_COUNT = 1       # 其中不通电定位脚（NPTH，不导通）
CHOC_PIN_DRILL = 1.20           # 电气脚孔径（PTH）
CHOC_ANCHOR_DRILL = 1.50        # 定位脚孔径（NPTH，官方图 2*1.5）
CHOC_CENTER_D = 5.00            # 中心孔 Ø5.00，非金属化（让位给 Ø4.80 塑料凸台）
# ★ 2026-09-26 坐标最终落定（凯华官方 datasheet CPG135301D01 2020-10-23 版，
#   Recommended PCB Layout 矢量图 600dpi 像素标定，双尺寸交叉验证误差 0.1%）：
#   电气脚 (−3.80, 4.93) 与 (−5.90, 0.00) Ø1.20 PTH；不通电定位脚 (5.15, −5.00) Ø1.50 NPTH。
#   ⚠️ siderakb 社区封装是官方坐标的 x/y 互换错版，勿再引用其坐标。
CHOC_PINS = [
    {"xy": (-3.80, 4.93), "type": "elec",   "drill": 1.20},   # 电气脚 1（PTH）
    {"xy": (-5.90, 0.00), "type": "elec",   "drill": 1.20},   # 电气脚 2（PTH）
    {"xy": (5.15, -5.00), "type": "anchor", "drill": 1.50},   # 不通电定位脚（NPTH，官方 2*1.5）
]
CHOC_LED_POS = (5.15, 0.00)     # LED 焊盘中心（官方图）
CHOC_PADS_UNRESOLVED = False    # 坐标已按官方 datasheet 像素标定落定

# ---- 二极管选位（2026-09-26 v2，DRC 校正后固化，spec §7：三处共用同一份坐标）--
# 12 只 1N4148 横躺在两条行间走廊（y=16 / y=34，宽 4.05mm，本体 Ø1.9 放得下）。
# 约束（DRC 实测校正）：
#   · 相邻二极管中心距 ≥ 10.32（跨距 7.62 + 焊盘 Ø2.5×2/2 + 间隙 0.2）
#   · 支撑台 ⌀4（(40,16)(76,16)(40,34)(76,34)）：pad 中心距台心 ≥ 3.45
#   · 主控左排孔带 x[78.22,83.72]（y 14.53~42.47 横贯两条走廊）→ 二极管中心 ≤ 68.74
#   · 板缘：pad1 左缘 ≥ 0.5 → 中心 ≥ 6（pad1 = 中心 −3.81 −1.25）
#   · 缺口 x≥90：pad2 右缘 ≤ 89.5 → 中心 ≤ 84.44（本布局最大 67.9，充裕）
DIODE_POS = {
    "PERM":    (6.0, 16.0),  "UP":   (16.5, 16.0), "MODEL": (27.0, 16.0),
    "CMD":     (47.26, 16.0), "STOP": (57.58, 16.0), "APPROVE": (67.9, 16.0),
    "LEFT":    (6.0, 34.0),  "DOWN": (16.5, 34.0), "RIGHT": (27.0, 34.0),
    "SPACE":   (47.26, 34.0), "ENTER": (57.58, 34.0), "VOICE": (67.9, 34.0),
}

# ---- 轴体旋转角（文档视角，逆时针为正）--------------------------------------
# 目的：让靠近主控（背面 x[79.7,97.48] y[8.5,41.5]）的轴体把 PTH 电气焊盘
# 转离主控排针（正面两排孔 x=80.97/96.21，y 11.03~38.97），避免焊盘重叠；
# 不通电 NPTH 定位脚尽量转出主控区（出不去的由 gen_kicad.py 省孔处理）。
# KiCad 放置时取负角（y 轴方向约定相反）：θ_kicad = −θ_doc。
SWITCH_ROT = {
    ("STOP", 0): 0.0,      # (85,7)  主控下移 0.5 后 0° 焊盘即避开左排孔带（见 gen_kicad.py）
    ("ENTER", 1): 180.0,   # (85,25) 电气焊盘转向右侧，避开排针左排
    ("VOICE", 0): 180.0,   # (85,43) NPTH 转到 (79.85,48) 出主控区
}

PITCH = P["PITCH"]
BORDER = P["PLATE_BORDER"]
# PCB 相对定位板的偏移（PCB 比定位板小一圈，居中放置）
PCB_W, PCB_H = P["PCB_W"], P["PCB_H"]
PCB_OX = (P["PLATE_W"] - PCB_W) / 2      # = 8.0
PCB_OY = (P["PLATE_H"] - PCB_H) / 2      # = 8.0
PCB_NOTCH_D, PCB_NOTCH_L = P["PCB_NOTCH_D"], P["PCB_NOTCH_L"]

# 配色
C_COL, C_ROW = "#dc2626", "#2563eb"
C_TEXT, C_MUTED, C_LINE = "#111827", "#6b7280", "#e5e7eb"
C_KEY1, C_KEYN, C_SW = "#e0f2fe", "#dcfce7", "#fef3c7"
S_KEY1, S_KEYN, S_SW = "#0284c7", "#16a34a", "#d97706"


# ============================== 网表构建 ====================================
def build():
    def n_switch(u):
        return 1 if u <= 1 else (2 if u == 2 else 3)

    def axis_x(c, u, i):
        """第 i 个轴体的 x（相对定位板左缘）"""
        if u <= 1:
            return BORDER + (c - 1) * PITCH + PITCH * 0.5
        return BORDER + (c - 1) * PITCH + PITCH * (0.5 + i * (u - 1) / (n_switch(u) - 1))

    keys = []
    for (c, r, u, tag) in sorted(KEYMAP, key=lambda k: (k[1], k[0])):
        plate_pos = [(round(axis_x(c, u, i), 2),
                      round(BORDER + (r - 1) * PITCH + PITCH / 2, 2))
                     for i in range(n_switch(u))]
        keys.append({
            "label": tag, "row": r, "col": c, "width_u": u,
            "switches": n_switch(u),
            "net_row": f"ROW{r}", "net_col": f"COL{c}",
            "pin_row": ROW_PINS[r - 1], "pin_col": COL_PINS[c - 1],
            "diode": "1N4148",
            # 相对定位板左下角
            "positions": plate_pos,
            # 相对 PCB 左下角（画板子用这个）
            "pcb_positions": [(round(x - PCB_OX, 2), round(y - PCB_OY, 2))
                              for (x, y) in plate_pos],
            # 二极管中心（行间走廊，2026-09-26 固化，spec §7）
            "diode_pcb_pos": list(DIODE_POS.get(tag, [])),
        })

    keys.append({
        "label": "APPROVE", "row": 1, "col": 6, "width_u": 1, "switches": 1,
        "net_row": "ROW1", "net_col": "COL6",
        "pin_row": ROW_PINS[0], "pin_col": APPROVE_PIN,
        "diode": "1N4148（建议）", "positions": [], "pcb_positions": [],
        "diode_pcb_pos": list(DIODE_POS["APPROVE"]),
        "note": "SPDT 拨动开关，不是轴体。装在右壁，本体在壳内，公共端接 ROW1、常开端接 COL6",
    })

    rows = [{"name": f"ROW{i}", "pin": p, "keys": [k["label"] for k in keys if k["row"] == i]}
            for i, p in enumerate(ROW_PINS, 1)]
    cols = [{"name": f"COL{i}", "pin": p, "keys": [k["label"] for k in keys if k["col"] == i]}
            for i, p in enumerate(COL_PINS, 1)]

    return {
        "board": "ClaudePad",
        "matrix": {"rows": len(ROW_PINS), "cols": len(COL_PINS)},
        "pinout": {"rows": ROW_PINS, "cols": COL_PINS,
                   "approve": APPROVE_PIN, "rgb_data": "D15"},
        "diode_direction": "col2row",
        "diode_rule": "阳极接列线，阴极接行线（电流 列 → 行）",
        "switch_footprint": {
            "name": "Kailh Choc V2 (PG1353)",
            "source": "凯华官方规格图",
            "pins": CHOC_PINS,
            "pin_count": CHOC_PIN_COUNT,
            "elec_pin_count": CHOC_ELEC_PIN_COUNT,
            "anchor_pin_count": CHOC_ANCHOR_PIN_COUNT,
            "pin_drill_mm": CHOC_PIN_DRILL,
            "anchor_drill_mm": CHOC_ANCHOR_DRILL,
            "pin_note": "3 物理脚 = 2 金属电气脚(PTH Ø1.20, 官方图 2-Ø1.20, 通电)"
                        " + 1 不通电定位脚(NPTH Ø1.50)",
            "led_pad": CHOC_LED_POS,
            "pin_size_mm": 2.0,
            "center_hole": (0.0, 0.0), "center_hole_d": CHOC_CENTER_D,
            "pads_unresolved": CHOC_PADS_UNRESOLVED,
        },
        "rows": rows, "cols": cols, "keys": keys,
        "total_switches": sum(k["switches"] for k in keys if k["label"] != "APPROVE"),
        "pcb": {
            "width": PCB_W, "height": PCB_H, "thickness": P["PCB_T"],
            "origin_offset_from_plate": [PCB_OX, PCB_OY],
            "notch_depth": PCB_NOTCH_D, "notch_length": PCB_NOTCH_L,
            "notch_y0": P["PCB_NOTCH_Y0"], "notch_y1": P["PCB_NOTCH_Y1"],
            "notch_note": "右侧开缺口让位给拨杆本体，纵向区间 [0, 17.5]（对准拨杆中心 y=5.6）",
        },
    }


# ============================== 画布 ========================================
# 画布与渲染后端抽在 tools/canvas.py，与「按键行程图」共用
from canvas import Canvas, render_svg, render_png     # noqa: E402

# ============================== 接线图布局 ==================================
def draw_wiring(nl):
    W, H = 1280, 940
    c = Canvas(W, H)
    X0, Y0, DX, DY = 300, 300, 150, 150
    cx = [X0 + i * DX for i in range(6)]
    cy = [Y0 + j * DY for j in range(3)]

    # 标题
    c.text(40, 46, "ClaudePad 接线图 · 3 行 × 6 列矩阵", 24, C_TEXT, "start", True)
    c.text(40, 74, "二极管方向 col2row：阳极接列、阴极接行，电流 列 → 行 ｜ 由 tools/gen_pcb.py 生成",
           14, C_MUTED)

    # 列线（垂直）与行线（水平）——先画线，方块后画以遮住线
    # 列线长度按「该列最后一个用到的行」决定，避免悬空线头
    keymap0 = {(k["row"], k["col"]) for k in nl["keys"]}
    for i, x in enumerate(cx):
        last_row = max((r for (r, cc) in keymap0 if cc == i + 1), default=1)
        c.line(x, 150, x, cy[last_row - 1] + 42, C_COL, 2.5)
    for y in cy:
        c.line(cx[0] - 70, y, cx[5] + 70, y, C_ROW, 2.5)

    # 列引脚标签（顶部）
    for i, (x, pin) in enumerate(zip(cx, COL_PINS)):
        c.text(x, 88, "输出驱动", 10, "#9ca3af", "middle")
        c.rect(x - 34, 96, 68, 40, "#fef2f2", C_COL, 1.5, 7)
        c.text(x, 114, f"COL{i+1}", 13, "#991b1b", "middle", True)
        c.text(x, 130, pin, 12, "#b91c1c", "middle")

    # 行引脚标签（右侧）
    for j, (y, pin) in enumerate(zip(cy, ROW_PINS)):
        c.rect(cx[5] + 80, y - 20, 72, 40, "#eff6ff", C_ROW, 1.5, 7)
        c.text(cx[5] + 116, y - 4, f"ROW{j+1}", 13, "#1e40af", "middle", True)
        c.text(cx[5] + 116, y + 12, pin, 12, "#1d4ed8", "middle")
        c.text(cx[5] + 116, y + 34, "输入读取", 10, "#9ca3af", "middle")

    # 矩阵交点
    keymap = {(k["row"], k["col"]): k for k in nl["keys"]}
    for j, y in enumerate(cy):
        for i, x in enumerate(cx):
            k = keymap.get((j + 1, i + 1))
            if not k:
                c.line(x - 9, y - 9, x + 9, y + 9, "#d1d5db", 2)
                c.line(x + 9, y - 9, x - 9, y + 9, "#d1d5db", 2)
                continue

            is_sw = k["label"] == "APPROVE"
            fill = C_SW if is_sw else (C_KEY1 if k["switches"] == 1 else C_KEYN)
            stroke = S_SW if is_sw else (S_KEY1 if k["switches"] == 1 else S_KEYN)

            # 二极管：画在列线上、两行方块之间的空隙中央
            # 行距 150，方块高 60 → 空隙 90，符号占约 44，居中放
            dy = y - 75
            c.rect(x - 13, dy - 22, 26, 44, "#ffffff")          # 遮住列线
            c.line(x, dy - 24, x, dy - 11, C_COL, 2)
            c.poly([(x - 8, dy - 11), (x + 8, dy - 11), (x, dy + 3)], C_COL)   # 阳极朝下
            c.line(x - 8, dy + 3, x + 8, dy + 3, C_COL, 2.8)                    # 阴极横杠
            c.line(x, dy + 3, x, dy + 22, C_ROW, 2)

            # 轴体方块（后画，遮住行线/列线，形成"线接入方块"的视觉）
            c.rect(x - 52, y - 30, 104, 60, fill, stroke, 2, 9)
            c.text(x, y - 4, k["label"], 14, C_TEXT, "middle", True)
            sub = ("拨动开关" if is_sw
                   else (f'{k["switches"]} 轴并联' if k["switches"] > 1 else "1 轴"))
            c.text(x, y + 14, sub, 11, stroke, "middle")

    # 图例
    lx, ly = 40, 780
    c.rect(lx, ly, 580, 126, "#f9fafb", C_LINE, 1, 10)
    c.text(lx + 16, ly + 26, "图例", 14, "#374151", "start", True)
    c.line(lx + 16, ly + 48, lx + 56, ly + 48, C_COL, 2.5)
    c.text(lx + 66, ly + 52, "列线（输出驱动，ACTIVE_HIGH）", 12, "#4b5563")
    c.line(lx + 16, ly + 74, lx + 56, ly + 74, C_ROW, 2.5)
    c.text(lx + 66, ly + 78, "行线（输入读取，ACTIVE_HIGH | PULL_DOWN）", 12, "#4b5563")
    c.poly([(lx + 30, ly + 92), (lx + 42, ly + 92), (lx + 36, ly + 104)], C_COL)
    c.line(lx + 30, ly + 104, lx + 42, ly + 104, C_COL, 2.4)
    c.text(lx + 66, ly + 104, "1N4148 · 阳极接列、阴极接行（col2row）", 12, "#4b5563")

    # 单键回路说明
    rx, ry = 660, 780
    c.rect(rx, ry, 580, 126, "#f9fafb", C_LINE, 1, 10)
    c.text(rx + 16, ry + 26, "单个按键回路", 14, "#374151", "start", True)
    c.text(rx + 16, ry + 58, "列线 → 二极管阳极 → 阴极 → 轴体 → 行线", 13, C_TEXT)
    c.text(rx + 16, ry + 84, "按下时回路导通，列被驱动为高 → 行读到高 → 固件判定按下",
           12, C_MUTED)
    c.text(rx + 16, ry + 108, "注意：二极管接反不会烧毁，但矩阵读不出来。修正：全部掉头，或改 diode-direction",
           12, "#b45309")
    return c


# ============================== 输出 ========================================
def write_json(nl):
    os.makedirs(OUT, exist_ok=True)
    p = os.path.join(OUT, "netlist.json")
    with open(p, "w", encoding="utf-8") as f:
        json.dump(nl, f, ensure_ascii=False, indent=2)
    return p


def write_md(nl):
    L = []
    A = L.append
    A("# ClaudePad PCB 网表\n")
    A(f"矩阵 **{nl['matrix']['rows']} 行 × {nl['matrix']['cols']} 列**"
      f"｜轴体 **{nl['total_switches']} 个**（含大键并联）｜审批拨杆 **1 个**\n")
    A("> 本文件由 `tools/gen_pcb.py` 从 `cad/lib/params.scad` 自动生成，不要手改。\n")

    A("## 1. 引脚分配\n")
    A("| 信号 | 主控引脚（NoLogo ProMicro NRF52840 / nice!nano 兼容） | 说明 |")
    A("|---|---|---|")
    for r in nl["rows"]:
        A(f"| {r['name']} | **{r['pin']}** | 行，输入（`ACTIVE_HIGH \\| PULL_DOWN`） |")
    for c in nl["cols"]:
        A(f"| {c['name']} | **{c['pin']}** | 列，输出（`ACTIVE_HIGH`） |")
    A(f"| RGB 数据 | {nl['pinout']['rgb_data']} | WS2812 数据线 |")
    A("")

    A("## 2. 二极管方向\n")
    A(f"`diode-direction = \"{nl['diode_direction']}\"`\n")
    A(f"**{nl['diode_rule']}**\n")
    A("即每个按键回路：**列线 → 二极管阳极 → 二极管阴极 → 轴体 → 行线**\n")
    A("> 接反不会烧，但矩阵读不出来。修正二选一：所有二极管掉头，"
      "或把固件 `diode-direction` 改成 `\"row2col\"`。\n")

    A("## 3. 按键接线对照表\n")
    A("| # | 按键 | 矩阵位置 | 行线 | 列线 | 轴体数 | 二极管 |")
    A("|---|---|---|---|---|---|---|")
    for i, k in enumerate(nl["keys"], 1):
        A(f"| {i} | **{k['label']}** | 行{k['row']}·列{k['col']} | "
          f"{k['net_row']}({k['pin_row']}) | {k['net_col']}({k['pin_col']}) | "
          f"{k['switches']} | {k['diode']} |")
    A("")

    big = [k for k in nl["keys"] if k["switches"] > 1]
    if big:
        A("### 大键并联接法（重要）\n")
        for k in big:
            A(f"**{k['label']}**（{k['width_u']}u）—— 定位板开 {k['switches']} 个轴孔，"
              f"**{k['switches']} 个轴体电气并联**到同一个矩阵交点 "
              f"（{k['net_row']} × {k['net_col']}）：\n")
            A("```")
            A(f"  轴体① 引脚 → {k['net_col']} ｜ 轴体① 另一脚 → 二极管 → {k['net_row']}")
            for n in range(2, k["switches"] + 1):
                A(f"  轴体{'①②③④'[n-1]} 引脚 → 与轴体① 同一条线（并联）")
            A("```")
            A("")
        A("> PCB：这几个轴体的焊盘用铜箔连到同一条行/列线。")
        A("> 手焊洞洞板：用一根导线把它们的引脚串起来。\n")

    A("## 4. Choc V2 (PG1353) 轴体 PCB 封装\n")
    A("原点 = 轴芯中心。**来源：凯华官方规格图**（PCB 板安装示意图）。\n")
    A("> ⚠️ 2026-09-21 修订：此前本节依据两个开源封装库（daprice / siderakb）「交叉验证」，"
      "但实物实测与该表不符 —— **两个库一起错了**。\n")
    A("| 特征 | 坐标 (x, y) mm | 孔径 mm | 数量 | 类型 |")
    A("|---|---|---|---|---|")
    for p in CHOC_PINS:
        if p["type"] == "elec":
            A(f"| 金属电气脚 | ({p['xy'][0]:.2f}, {p['xy'][1]:.2f}) | {p['drill']:.2f} | 1 | 金属化（PTH），通电 |")
        else:
            A(f"| 不通电定位脚 | ({p['xy'][0]:.2f}, {p['xy'][1]:.2f}) | {p['drill']:.2f} | 1 | 非金属化（NPTH），不导通 |")
    A(f"| 轴芯中心孔 | (0, 0) | {CHOC_CENTER_D} | 1 | 非金属化（NPTH） |")
    A(f"| LED 焊盘 | ({CHOC_LED_POS[0]:.2f}, {CHOC_LED_POS[1]:.2f}) | — | 1 | 官方图标注 `LED` |")
    A("")
    A("坐标来源：凯华官方 datasheet（CPG135301D01，2020-10-23 版）Recommended PCB Layout，")
    A("600dpi 矢量图像素标定，双尺寸交叉验证误差 0.1%（2026-09-26 落定）。")
    A(f"LED 焊盘中心 ({CHOC_LED_POS[0]:.2f}, {CHOC_LED_POS[1]:.2f})。")
    A(f"PCB 必须钻满 {CHOC_PIN_COUNT} 个孔，一个都不能省（定位脚孔 NPTH，不导通）。")
    A("★ 导通对已于 2026-09-26 经万用表实测确认（按下导通 = 电气脚对），坐标可用。\n")
    A("**外形**：官方图标注 15 × 15 × 5.3mm，底座外形 13.95 × 13.95。\n")

    A("## 5. 其他元件\n")
    A("| 元件 | 连接 |")
    A("|---|---|")
    A("| 审批拨杆 SPDT | 公共端 → ROW1；常开端 → COL6。**串一只 1N4148 防鬼影** |")
    A("| 电池 | 带引线的电池 → 主控 **B+ / B− 焊盘**（注意极性；该板不是 JST 插座） |")
    A("| 电源开关 | 串在电池正极与主控之间 |")
    A("| 复位按钮 | 并联到主控的 RST 焊盘（该板无板载复位按钮） |")
    A("| WS2812 | 数据线 → D15，电源接 3.3V/VCC，地接 GND |")
    A("")

    p = os.path.join(OUT, "netlist.md")
    with open(p, "w", encoding="utf-8") as f:
        f.write("\n".join(L))
    return p


def write_placement(nl):
    """输出 KiCad 就绪的元件坐标表（CSV）

    给「拿开源设计改板」用：布局不用量，直接照表放。

    坐标系说明：
      x_mm / y_mm   —— 板左下角为原点，Y 向上（与 params.scad 一致）
      x_kicad / y_kicad —— KiCad 用左上角为原点、Y 向下，故 y_kicad = 板高 − y_mm
    """
    W = nl["pcb"]["width"]
    H = nl["pcb"]["height"]

    L = [
        "# ClaudePad 元件坐标表（供 KiCad 放置用）",
        "# 由 tools/gen_pcb.py 从 cad/lib/params.scad 生成 —— 勿手改",
        f"# 板子外形 {W} × {H} mm，厚 {nl['pcb']['thickness']} mm",
        "#",
        "# 坐标系：板左下角为原点",
        "#   x_mm / y_mm        本设计坐标系（Y 向上）",
        "#   x_kicad / y_kicad  KiCad 坐标系（Y 向下），y_kicad = 板高 − y_mm",
        "#",
        "# 轴体旋转角：Choc 轴体封装默认 0°，本设计全部正向放置",
        "",
        "ref,type,label,matrix,x_mm,y_mm,x_kicad,y_kicad,rotation,note",
    ]

    sw_n = 0
    for k in sorted(nl["keys"], key=lambda x: (x["row"], x["col"])):
        positions = k.get("pcb_positions") or []
        if not positions:
            L.append(f",toggle,{k['label']},ROW{k['row']}xCOL{k['col']},,,,,,"
                     "SPDT 拨动开关；位置见外壳右壁，不在主矩阵区")
            continue
        multi = len(positions) > 1
        for i, (x, y) in enumerate(positions):
            sw_n += 1
            ref = f"SW{sw_n}"
            note = f"{k['label']}"
            if multi:
                note += f"（{i+1}/{len(positions)} 并联到同一矩阵点）"
            rot = SWITCH_ROT.get((k["label"], i), 0.0)
            L.append(f"{ref},switch,{k['label']},ROW{k['row']}xCOL{k['col']},"
                     f"{x:.2f},{y:.2f},{x:.2f},{H - y:.2f},{rot:g},{note}")

    L.append("")
    L.append("# 二极管：型号 1N4148，阳极接列线、阴极接行线（col2row）")
    L.append("# 位置在行间走廊（y=16 / y=34），已避开支撑台与缺口（2026-09-26 固化）")
    L.append("ref,type,matrix,x_mm,y_mm,x_kicad,y_kicad,rotation,note")
    d_n = 0
    for k in sorted(nl["keys"], key=lambda x: (x["row"], x["col"])):
        dx, dy = k.get("diode_pcb_pos") or (None, None)
        if dx is None:
            continue
        d_n += 1
        note = f"{k['label']}；阳极→COL{k['col']}，阴极→ROW{k['row']}"
        L.append(f"D{d_n},diode,ROW{k['row']}xCOL{k['col']},"
                 f"{dx:.2f},{dy:.2f},{dx:.2f},{H - dy:.2f},0,{note}")

    p = os.path.join(OUT, "placement.csv")
    with open(p, "w", encoding="utf-8", newline="") as f:
        f.write("\n".join(L) + "\n")
    return p


def main():
    nl = build()
    os.makedirs(OUT, exist_ok=True)

    errs = []
    used = set()
    for k in nl["keys"]:
        pos = (k["row"], k["col"])
        if pos in used:
            errs.append(f"矩阵位置冲突：{pos}")
        used.add(pos)
        if not (1 <= k["row"] <= len(ROW_PINS)):
            errs.append(f"{k['label']} 行号越界")
        if not (1 <= k["col"] <= len(COL_PINS)):
            errs.append(f"{k['label']} 列号越界")

    print("=" * 72)
    print("ClaudePad PCB 网表生成")
    print("=" * 72)
    print(f"  矩阵        : {nl['matrix']['rows']} 行 × {nl['matrix']['cols']} 列")
    print(f"  矩阵交点    : {len(nl['keys'])} 个（含审批拨杆）")
    print(f"  轴体总数    : {nl['total_switches']} 个（9 单键 + 回车 2 + 空格 3）")
    print(f"  审批拨杆    : 1 个（SPDT 拨动开关）")
    print(f"  行引脚      : {', '.join(ROW_PINS)}")
    print(f"  列引脚      : {', '.join(COL_PINS)}")
    print()
    print(f"{'按键':<10}{'位置':<12}{'行线':<16}{'列线':<16}{'轴数'}")
    print("-" * 72)
    for k in nl["keys"]:
        rn = f"{k['net_row']}({k['pin_row']})"
        cn = f"{k['net_col']}({k['pin_col']})"
        pos = f"行{k['row']}·列{k['col']}"
        print(f"{k['label']:<10}{pos:<12}{rn:<16}{cn:<16}{k['switches']}")

    # 生成文件
    c = draw_wiring(nl)
    files = [write_json(nl), write_md(nl), write_placement(nl)]
    svg_p = os.path.join(OUT, "wiring.svg")
    with open(svg_p, "w", encoding="utf-8") as f:
        f.write(render_svg(c))
    files.append(svg_p)
    try:
        files.append(render_png(c, os.path.join(OUT, "wiring.png")))
    except Exception as e:
        print(f"⚠️  PNG 渲染失败（不影响 SVG）：{e}")

    print()
    for p in files:
        print(f"✅ {os.path.relpath(p, ROOT)}")

    print()
    if errs:
        print(f"❌ {len(errs)} 个问题：")
        for e in errs:
            print(f"   · {e}")
        return 1
    print(f"✅ 自检通过：{len(nl['keys'])} 个矩阵位置无冲突，引脚分配在范围内")
    return 0


if __name__ == "__main__":
    sys.exit(main())

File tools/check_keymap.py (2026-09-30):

# -*- coding: utf-8 -*-
"""
固件 ↔ 结构 一致性校验
----------------------
键盘项目最容易出的错：改了 CAD 布局忘了改固件键位（或反过来）。
本脚本把两边对齐验证。

校验内容：
  1. overlay 的矩阵变换 map 数量 == keymap 的 bindings 数量
  2. 两个数量 == params.scad 的键位数 + 1（审批拨杆）
  3. 键位顺序逐项比对（params.scad 的 KEYMAP 顺序 vs keymap 的 bindings 顺序）
  4. 每个键绑定的行为是否与 PRD 定义的功能相符
  5. 所有自定义行为的 #binding-cells 与实际传参个数是否匹配

运行：python tools/check_keymap.py
"""

import json
import os
import re
import sys

sys.path.insert(0, os.path.dirname(os.path.abspath(__file__)))
from scad_params import load_keymap     # noqa: E402
from console_utf8 import enable         # noqa: E402

enable()

ROOT = os.path.dirname(os.path.dirname(os.path.abspath(__file__)))
SHIELD = os.path.join(ROOT, "firmware", "config", "boards", "shields", "claudepad")
OVERLAY = os.path.join(SHIELD, "claudepad.overlay")
KEYMAP = os.path.join(SHIELD, "claudepad.keymap")

# ZMK 内建行为的参数个数（只列本项目用到的）
BUILTIN_CELLS = {
    "kp": 1, "none": 0, "trans": 0, "mo": 1, "tog": 1, "to": 1,
    "bt": 2, "rgb_ug": 2, "bootloader": 0, "sys_reset": 0,
}

# 每个键位标签「应该」绑定什么行为（依据 PRD 第 3 章）
EXPECTED = {
    "PERM":    "perm",
    "UP":      "kp",
    "MODEL":   "model",
    "CMD":     "cmd",
    "STOP":    "stop",
    "LEFT":    "kp",
    "DOWN":    "kp",
    "RIGHT":   "kp",
    "ENTER":   "ent_td",
    "SPACE":   "spc_tab",
    "VOICE":   "voice",
}
# 审批拨杆（不在 KEYMAP 里，单独列出）
APPROVE_BEHAVIOR = "kp"

errors = []
warns = []


def strip_comments(t):
    t = re.sub(r"/\*.*?\*/", "", t, flags=re.S)
    t = re.sub(r"//[^\n]*", "", t)
    return t


def parse_behavior_cells(text):
    """从 keymap 文件里解析所有自定义行为的 #binding-cells"""
    cells = {}
    # 抓取每个节点块： label: node_name { ... };
    for m in re.finditer(r"([A-Za-z_]\w*)\s*:\s*([A-Za-z_]\w*)\s*\{(.*?)\n\s*\};",
                         text, flags=re.S):
        label, body = m.group(1), m.group(3)
        cm = re.search(r"#binding-cells\s*=\s*<(\d+)>", body)
        if cm:
            cells[label] = int(cm.group(1))
    return cells


def tokenize_bindings(text, cells):
    """把 keymap 里 default_layer 的 bindings 解析成 [(行为名, [参数...]), ...]

    ⚠️ 必须限定在 default_layer 块内查找 —— 文件里前面的宏也有 bindings，
       直接全局搜会抓到宏的 bindings（这是个真实踩过的坑）。
    """
    lm = re.search(r"default_layer\s*\{(.*?)\n\s*\};", text, flags=re.S)
    scope = lm.group(1) if lm else text

    m = re.search(r"bindings\s*=\s*<(.*?)>\s*;", scope, flags=re.S)
    if not m:
        return []
    body = m.group(1)
    # 切成 token：&name 或普通标识符/数字/括号表达式
    tokens = re.findall(r"&[A-Za-z_]\w*|[A-Za-z_]\w*\([^)]*\)|[A-Za-z_]\w*|\d+", body)

    out = []
    i = 0
    all_cells = {**BUILTIN_CELLS, **cells}
    while i < len(tokens):
        tok = tokens[i]
        if tok.startswith("&"):
            name = tok[1:]
            n = all_cells.get(name)
            if n is None:
                errors.append(f"未定义的行为：&{name}（无法确定参数个数）")
                i += 1
                continue
            params = tokens[i + 1: i + 1 + n]
            if len(params) < n:
                errors.append(f"&{name} 需要 {n} 个参数，实际只给了 {len(params)} 个")
            out.append((name, params))
            i += 1 + n
        else:
            i += 1
    return out


def main():
    for p in (OVERLAY, KEYMAP):
        if not os.path.exists(p):
            print(f"❌ 文件不存在：{p}")
            return 1

    overlay = strip_comments(open(OVERLAY, encoding="utf-8").read())
    keymap_raw = open(KEYMAP, encoding="utf-8").read()
    keymap = strip_comments(keymap_raw)

    print("=" * 74)
    print("固件 ↔ 结构 一致性校验")
    print("=" * 74)

    # ---- 1. 矩阵变换 map ----
    tm = re.search(r"map\s*=\s*<(.*?)>\s*;", overlay, flags=re.S)
    if not tm:
        print("❌ overlay 里没找到 matrix-transform 的 map")
        return 1
    rc_list = re.findall(r"RC\((\d+),(\d+)\)", tm.group(1))
    print(f"\n【矩阵变换】map 里有 {len(rc_list)} 个 RC() 交点")
    for idx, (r, c) in enumerate(rc_list):
        print(f"  [{idx:>2}] 行{int(r)+1} 列{int(c)+1}")

    # 行/列数声明
    cols_decl = re.search(r"columns\s*=\s*<(\d+)>", overlay)
    rows_decl = re.search(r"rows\s*=\s*<(\d+)>", overlay)
    if cols_decl and rows_decl:
        nc, nr = int(cols_decl.group(1)), int(rows_decl.group(1))
        print(f"  声明矩阵 = {nr} 行 × {nc} 列")
        # 检查 col-gpios / row-gpios 数量
        n_col = len(re.findall(r"&pro_micro\s+\d+", overlay.split("col-gpios")[1].split(";")[0]))
        n_row = len(re.findall(r"&pro_micro\s+\d+", overlay.split("row-gpios")[1].split(";")[0]))
        print(f"  row-gpios = {n_row} 个，col-gpios = {n_col} 个")
        if n_row != nr:
            errors.append(f"rows 声明 {nr} 但 row-gpios 有 {n_row} 个")
        if n_col != nc:
            errors.append(f"columns 声明 {nc} 但 col-gpios 有 {n_col} 个")
        # 每个 RC 必须落在范围内
        for r, c in rc_list:
            if int(r) >= nr or int(c) >= nc:
                errors.append(f"RC({r},{c}) 超出 {nr}×{nc} 矩阵范围")

    # ---- 2. 解析 bindings ----
    cells = parse_behavior_cells(keymap)
    print(f"\n【自定义行为】解析到 {len(cells)} 个")
    for k, v in sorted(cells.items()):
        print(f"  &{k:<16} 参数个数 = {v}")

    bindings = tokenize_bindings(keymap, cells)
    print(f"\n【键位绑定】共 {len(bindings)} 个")

    # ---- 3. 数量比对 ----
    km = load_keymap()          # CAD 侧的键位表
    expect_count = len(km) + 1  # +1 = 审批拨杆
    print(f"\n【数量比对】")
    print(f"  CAD 键位      : {len(km)} 个 + 审批拨杆 1 个 = {expect_count}")
    print(f"  矩阵变换 map  : {len(rc_list)}")
    print(f"  keymap 绑定   : {len(bindings)}")
    if len(rc_list) != expect_count:
        errors.append(f"矩阵 map 数量 {len(rc_list)} ≠ 期望 {expect_count}")
    if len(bindings) != expect_count:
        errors.append(f"keymap 绑定数量 {len(bindings)} ≠ 期望 {expect_count}")
    if len(rc_list) != len(bindings):
        errors.append(f"map 数量 {len(rc_list)} ≠ 绑定数量 {len(bindings)}（键位会错位）")

    # ---- 4. 顺序与功能比对 ----
    print(f"\n【逐项比对】")
    print(f"{'#':<4}{'CAD 键位':<12}{'期望行为':<12}{'实际绑定':<20}{'结果'}")
    print("-" * 74)

    # CAD 侧顺序：按 (行, 列) 排序，审批拨杆插在行1末尾
    ordered = sorted(km, key=lambda k: (k[1], k[0]))
    expected_seq = []
    for (c, r, u, tag) in ordered:
        if r == 1:
            expected_seq.append((tag, EXPECTED.get(tag, "?")))
            if c == 5:      # 行1 最后一格之后插审批拨杆
                expected_seq.append(("APPROVE", APPROVE_BEHAVIOR))
        else:
            expected_seq.append((tag, EXPECTED.get(tag, "?")))

    for i, (tag, exp) in enumerate(expected_seq):
        if i >= len(bindings):
            print(f"{i:<4}{tag:<12}{exp:<12}{'(缺失)':<20}❌")
            errors.append(f"键位 {tag} 没有对应绑定")
            continue
        actual, params = bindings[i]
        ok = (actual == exp)
        mark = "✅" if ok else "❌"
        pstr = " ".join(params) if params else ""
        print(f"{i:<4}{tag:<12}&{exp:<11}&{actual} {pstr:<16}{mark}")
        if not ok:
            errors.append(f"键位 {tag}：期望 &{exp}，实际 &{actual}")
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

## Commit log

2026-09-15 初始提交：ClaudePad 蓝牙编程键盘完整设计
    11 键 + 侧边审批拨杆的 BLE 小键盘，为 Claude Code / 终端场景定制。
    包含：
    - 产品需求（PRD）：键位定义、手势表、HID 映射
    - 参数化 3D 模型（OpenSCAD）：底座 / 定位板 / 键帽 / 校准试件
    - 已渲染验证的 6 个 STL（全部水密、包围盒零偏差）
    - 可交互三维查看器（three.js）
    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
    [00_test_coupon.stl, 01_case_bottom.stl, 02_plate.stl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]
2026-09-15 新增项目报告；修正采购清单中的过时数字
    新增 docs/项目报告.md：
    - 任务计划（P0-P4 路线图 + 完成度）
    - 模块进度明细（含验证证据与实测数据）
    - 材料清单（最小验证集 / 完整原型 / 工具 / 成本构成）
    - 关键设计决策、风险与未验证项、下一步
    修正 docs/采购清单.md 的 5 处过时数字：
    - 轴体数量 13 → 14（9 单键 + 回车 2 + 空格 3），采购量 16 → 17
    - 键帽改为「不买，自己打印」（项目已产出可打印的 2u/4u 模型）
    - 删除排针/排母（PCB 上方仅 5.0mm 净空，主控必须直焊）
    - 定位板说明改为「11 键 / 14 个轴孔」（原写「15 格」）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
2026-09-15 PCB 规格书新增 §13：能买现成的 PCB 吗
    结论：不能。根本障碍不是"布局特殊"，而是**空格中间的轴不在标准网格上**。
    轴体坐标显示网格线是 7/25/43/61/79（18mm 间距），
    而 4u 空格的中间支撑轴在 x=34 —— 落在网格线 25 与 43 之间。
    这不是失误：4u 键跨列 1-4（跨度 72mm），三点对称支撑位于
    1/6、3/6、5/6 处，中点正好是跨度中心。任何均匀网格 PCB 都放不下。
    新增内容：
    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
2026-09-15 新增 PCB 改板方案（路径 B）；gen_pcb 增加坐标表输出
    选定底板：EPPad（立创开源硬件平台 / GAVIS / GPL 3.0）
    —— 唯一同时满足「无线 + nice!nano + 凯华矮轴」且资料齐全的开源项目
    docs/PCB改板方案.md 内容：
    - 底板选型对比（EPPad vs TK13 vs GitHub 候选）
    - 复用清单 / 重做清单
    - 三个必先解决的冲突
    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
    [placement.csv]
2026-09-15 技能更新：新增「复用第三方设计前必须审查其机械假设」规则
    references/design-rule-checks.md 新增 §13：
    - 借用开源设计时，哪些机械假设会静默破坏你的堆叠
    （元件高度 / 连接器类型 / 板形 / 键距 / 离格位置）
    - 实例：4u 键跨度 72mm，三点对称支撑必然落在跨度中点，
    与 18mm 网格线错开 9mm —— 设计是对的，是网格表达不了它
    - 原则：借电路设计，重新推导机械设计
    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
2026-09-15 ★ 发现阻塞问题：主控在 PCB 上放不下
    问题
    主控 nice!nano 17.8×33mm，板面只有 86×50mm，上面已摆 14 个轴体
    （本体 13.5mm 见方，占 2550mm²／板面 4300mm²）
    穷举板面所有位置（步长 0.5mm）：
    当前设计位置 (65.2, 14.0) → 与轴体重叠 322.52 mm²
    零重叠位置数 = 0
    根因：3×5 网格在 18mm 键距下需 90×54mm，而 PCB 只有 86×50
    轴体本体几乎贴到板边（四边各余 0.25mm），没有连续空位
    影响：所有路径（买现成/改开源/自己画）都受此阻塞
    不是 PCB 的问题，是布局没给主控留位置
    解决方案（推荐）
    主控移到 PCB 背面：P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
    [check_dims.py]
2026-09-16 采购清单：补全最小验证集并新增「不要买」清单
    第 1 批（最小验证集）补充与修正：
    - 新增 1N4148 二极管 ×10 —— 面包板上搭真矩阵，验证 col2row 接线方向
    - 拨动开关规格补上「轴套长度 ≥9mm」（壁 2.4 + 凸台 4.1 + 螺母 2.0 = 8.5）
    - 键帽标注为可选（可自己打印）
    - 新增「现在同时做」：打印校准试件测 SWITCH_PLATE_GAP（唯一阻塞项）
    新增「⛔ 不要买」清单（会白花钱）：
    - 键帽 2u/4u（买不到，自己打印）
    - 定位板/外壳（自己打印）
    - 排针排母（PCB 上方仅 5.0mm 净空，主控必须直焊）
    - 热插拔轴座（下方凸出 2.5-3.0mm，与电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
2026-09-16 采购清单新增「想跳过验证直接开干？」章节
    用户想跳过面包板验证阶段直接开工。可以，但要说清代价。
    新增 §11：
    - 11.1 跳过的代价（问题会在焊完后才发现）
    - 11.2 ★ 唯一不建议跳过的：校准试件
    SWITCH_PLATE_GAP 错 0.5mm → 定位板固定不住 + 外壳要重打
    两个解法：打试件（15min）或卡尺量实物（5min）
    建议下单当天就丢去打印，与等快递并行
    - 11.3 跳过验证版：一次买齐的完整清单（8 类）
    - 11.4 买到之后的 7 步流程，标出第 3 步（主控放不下）不能跳
2026-09-16 清理冗余文件
    删除 2 个确定多余的文件（均已备份 + 可从 git 历史恢复）：
    - cad/output/wiring.svg 与 pcb/wiring.svg 逐字节相同（MD5 一致），
    是早先手工复制的，viewer.html 未引用
    - dist/parametric-3d-print-design.zip 技能打包产物，可用 skill-creator 重新生成
    同时：
    - 删除空的 dist/ 目录
    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
    [00_test_coupon.stl, 01_case_bottom.stl, 02_plate.stl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]
2026-09-16 恢复被误删的 cad/ 目录
    上一个提交（0a92a96）误将整个 cad/ 目录一并删除并推送，
    本提交从 0d13e8d 完整恢复 24 个文件。
    同时保留上一提交中有意删除的两项：
    - cad/output/wiring.svg（与 pcb/wiring.svg 重复的副本）
    - dist/parametric-3d-print-design.zip（可重新打包）
    [00_test_coupon.stl, 01_case_bottom.stl, 02_plate.stl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]
2026-09-16 删除重复文件 cad/output/wiring.svg
    与 pcb/wiring.svg 逐字节相同（MD5 一致），viewer.html 未引用。
    正式版仍由 tools/gen_pcb.py 生成到 pcb/wiring.svg。
    注：上一次尝试用 git rm 删除时，git rm 误将整个 cad/ 目录一并删除，
    已在上一个提交（9cc7685）恢复。本次改用精确的单文件删除。
2026-09-16 新增 docs/新手采购清单.md（面向第一次做硬件的版本）
    用户是电子制作新手，外壳/定位板/键帽已 3D 打印完成，
    需要一份只含必需项、逐项说明用途与规格、且便于手工焊接的清单。
    内容：
    - 必需清单 12 项（名称/数量/用途/规格/新手提示）
    - 工具 7 项（标出不可省的三项）
    - 不买清单 6 类（含 nice!nano 自带的复位按钮与充电电路）
    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
2026-09-16 新手采购清单：补上 USB-C 数据线，新增主控接线说明
    用户问了三个问题，暴露出清单里漏了数据线。
    修正：
    - 必需清单 12 → 13 项，补上「USB-C 数据线」
    注明 nice!nano 不带线，且必须是数据线不是纯充电线
    - 「排针排母」不买理由更新为实测值：主控上方净空仅 3.40mm
    新增 §6「主控怎么接线（新手常问）」：
    - 要不要焊排针：不要。实测净空 3.40mm vs 标准排针 8.5mm
    - 正确做法：导线直接焊进 nano 的 2.54mm 通孔（孔是给新手准备的，
    线头先上锡再穿过去，比表面焊容易得多）
    - nano 摆放：元件面朝上（能看到 LED 和复位键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
2026-09-16 ESP32 选型评估：写入文档并否决
    用户问「能不能用 ESP32-WROOM-32 做主控」。查证官方规格书后结论为不行，
    三处文档同步该结论，避免以后重复调研。
    数据来源：乐鑫 ESP32-WROOM-32_datasheet_cn.pdf v3.8 第 32 页外形尺寸
    - 纯模组 18.00 × 25.50 × 3.10 mm，38 脚，引脚间距 1.27mm
    - 开发板（DevKitC 形态）54.4 × 27.9 × 10 mm
    三个硬伤：
    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
2026-09-16 方案 A 实施完成：主控移到 PCB 背面（26 项校验首次全绿）
    用户 2026-09-16 选定方案 A。
    params.scad
    - 新增 NANO_ON_BACK / NANO_POS_X / NANO_POS_Y（主控安装面与位置）
    - PCB_SUPPORT_X1/X2：16/70 → 34/52（让开主控）
    case_bottom.scad
    - NANO_X/NANO_Y 改为由 PCB 坐标换算
    - 新增 PCB_BOTTOM_Z；USB 开孔高度随安装面自动切换（z 10.40 → 5.20）
    - 电池从「居中」改为「贴内腔左壁」
    tools/scad_params.py
    - 修复：解析器只接受数字，OpenSCAD 的 true/false 解析不了
    现在优先判断 bool（bool 是 int 的子类，否则会被 float() 分支吞掉），
    并在 safe 环境注入 true/false
    tools/check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
    [00_test_coupon.stl, 01_case_bottom.stl, 02_plate.stl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]
2026-09-16 新手采购清单：同步方案 A 的改动
    主控改到 PCB 背面后，清单有四处必须更新：
    1. 开头警告「主控位置冲突（未解决）」→「已解决」，
    但补充两件事：外壳需重做（顶盖与定位板不受影响）、USB 口够不到右壁
    2. 新增第 14 项「USB-C 面板延长线」—— 必需清单 13 → 14 项
    原因：USB 口距内腔右壁 8.2mm，而插头金属部分只有 6.5mm，插不到底
    3. §6「主控怎么接线」按新安装面重写：
    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
2026-09-16 新手采购清单：修掉「不用买」清单里的过时数据
    排针/排母的排除理由还在引用旧的「主控上方净空 3.40mm」，
    主控已移到 PCB 背面，改为「下方层高 5.0mm，主控 3.2 + 排针座 2.54 = 5.74，超了」。
2026-09-16 V2 轴体 + PCB 加宽：两项设计变更（26 项校验全绿）
    用户 2026-09-16 确认：轴体用 Choc V2（PG1353）；USB 问题不买延长线、直接改 PCB。
    一、轴体 V1 → V2
    | 项 | V1 (PG1350) | V2 (PG1353) |
    | 轴心 | 3.4mm 矩形小十字 | 5mm MX 十字 |
    | 键程 | 3.0mm | 3.2±0.25mm |
    | PCB 中心孔 | 3.429mm | 5.0mm |
    | 固定脚 | 有 fixing pins | 取消 |
    | 电气引脚 | (0,5.9) (-5,3.8) | 相同 |
    来源：themk.org PG1353 词条 + mwlabs.be 实装日志（两处独立印证）。
    网上另有文章称 V2 保持矩形轴心，与这两处矛盾，经比对判定为错误内容。
    改动：
    - SWITCH_TRAVEL 3.00 → 3.20 → CAP_GAP 3.30 → 3.50 → 整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
    [00_test_coupon.stl, 01_case_bottom.stl, 02_plate.stl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]
2026-09-16 主控改用 nice!nano v2.0_SMT（第三方兼容板）：尺寸与电池要求更新
    用户提供的淘宝截图确认主控为「nice!nano v2.0_SMT」（大熊智能）。
    下载其官方说明书（ZMK 技术手册 V1.0，2026-07-23）核对，结论：
    这是**第三方 ProMicro 替代板**，不是 Nice Keyboards 官方 nice!nano。
    说明书原文：「兼容 Nice!Nano，他的引脚与 Nice!Nano 相同……
    在此基础上还新增了 SMT 半孔焊盘，直插和贴片都兼容」
    好消息（不用改设计）：
    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
    [00_test_coupon.stl, 01_case_bottom.stl, 02_plate.stl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]
2026-09-16 主控无复位按钮：新增外接按钮采购项
    用户确认实物后反馈：nice!nano v2.0_SMT 板上**没有复位按钮**。
    说明书写明进 Bootloader 的方式是「在 0.5S 内短接 2 次 RST 到 GND」，
    而官方 nice!nano 是物理按钮（双击进入）—— 这是兼容板与官方的一处实质差异。
    影响：外壳底板预留的 φ8mm 复位孔原本是「给主控自带按钮留的」，
    现在主控没按钮，该孔失去原用途。
    好消息：孔的位置（PCB 坐标 82.5, 5.5）**正好在主控外侧**
    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
2026-09-16 主控定稿：NoLogo ProMicro NRF52840（尺寸与官方一致）
    用户对比后选用 NoLogo ProMicro NRF52840（原 SuperMini NRF52840），
    取代之前考虑的 nice!nano v2.0_SMT。
    依据厂商文档站 nologo.tech + 产品尺寸图：
    - 尺寸 **17.78 × 33.00mm**（= 7 × 2.54 宽，30.48 引脚跨度 + 两端）—— **与官方 nice!nano 完全一致**
    - 引脚标准 Pro Micro 布局 → 固件不用改
    - 充电电流 **100mA**（BOOST 跳线 300mA，需 >500mAh 电池）
    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
    [00_test_coupon.stl, 01_case_bottom.stl, 02_plate.stl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]
2026-09-28 PCB 完成并下单：轴体数据按官方 datasheet 修正 + 全自动生成/布线管线
    - 凯华 PG1353 引脚坐标按官方 datasheet 像素标定落定：电气脚 (-3.8,4.93)/(-5.9,0) Ø1.2 PTH、定位脚 (5.15,-5) Ø1.5 NPTH（siderakb 等社区库为 x/y 互换错版，已弃用）
    - gen_kicad.py：pcbnew API 全自动生成 PCB（板框+缺口/14 轴/12 二极管/主控排针/拨杆焊盘），布局经多轮 DRC 校正（主控 y[12.5,45.5]、缺口 y[0,12]、STOP 0°/ENTER2 180°/VOICE 180°、省 2 个定位孔）
    - 布线：FreeRouting v2.4.1 CLI 自动布线（58 项全通）+ 自写 import_ses.py 导回（KiCad 10 不认 FR v2.4.1 SES），179 段走线 + 2 过孔
    - DRC 最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
    [case_bottom.scad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]
2026-09-30 固件编译打通：改为标准 zmk-config 布局 + GitHub Actions
    固件从未编译过，且原「方式一：GitHub Actions」实际不可用 —— 仓库里没有任何
    workflow 文件，推上去不会触发任何构建。核对 ZMK v0.1.0 与 v0.3.0 官方源码后修正。
    问题与修正
    - 布局：boards/ 从 config/ 外挪到 config/boards/。ZMK 只从 <ZMK_CONFIG>/boards/shields/
    找 shield（modules.cmake:51 / Kconfig:747），放错层级即报 shield not found
    - 删除 zephyr/module.yml：它把 firmware/ 声明成 ZMK 模块，会让官方 CI 改走模块分支
    （复制 config 到临时目录 + 传 -DZMK_EXTRA_MODULES），shield 查找路径随之改变。
    改成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
    [check_env.py, check_keymap.py]
2026-09-30 固件 README：记录 CI 已跑通（138KB .uf2）与 zmk-firmware 分支的更新方法
    - 方式一标注为「已实测成功」，写清当前用 zmk-firmware 分支（git subtree split）
    的构建方式，以及改完固件后重新 split + force push 的步骤
    - 说明推 main 不触发构建、只有推 zmk-firmware 才会，避免改完键位以为会自动重编
    - 已知限制「从未真正编译过」→「已编译通过，但未上机」
2026-10-11 焊接指南与分步渲染：3D 模型 + 6 步装配图（提交保护）
    这部分是 2026-10-01 之后产生的工作，一直未提交。原样入库，不做任何修改，
    以便后续板子改版的 diff 能干净地看出来。
    - docs/焊接指南.md 焊接流程：工具/元件清点/5 步顺序/焊后检查
    - docs/焊接参考图.html 配对的可视化参考页
    - docs/img/*.png|svg 6 步过程渲染 + 正反面 3D 渲染 + 3 张参考 SVG
    - pcb/steps/*.kicad_pcb 6 个分步板文件（对应每张过程图）
    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
2026-10-11 PCB 第二版：主控排针改 1×13（实物 13 脚）+ USB 开孔从右壁挪到上壁
    第一版已报废，两个硬伤：
    【1】主控排针 12 孔 → 13 孔（致命）
    实物每排 13 个引脚、跨距 30.48mm（= 12 × 2.54）。原按 KiCad 1x12 封装生成
    （跨距 27.94），于是 12 个孔相对 13 个引脚**每个都偏 1.27mm（半个间距）**，
    还少一个孔 —— 主控根本插不上去。
    根因：params.scad 里写着「30.48 引脚跨度」却没记「一排几个脚」，
    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
2026-10-11 补渲染：USB 开孔改到上壁后的底座预览
    - case_usb_port.png 从 +y 侧看，可见新的圆角矩形 USB 开孔（在上壁、对准主控短边中点）
    - case_usb_port_iso.png 等轴测视图
    渲染命令：
    openscad -o output/preview/case_usb_port.png --imgsize=1200,850 \
    --camera=0,0,0,62,0,205,270 --projection=p --autocenter --viewall case_bottom.scad
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2026-10-11 布局再改：空格那行 4 颗键贴左排（跨列 1-3 + 语音列 4）+ 定位板切孔 bug 修复
    用户原话（2026-10-11）：'最下层不是有四个键而已吗？我们之间给他并排与上方对其'
    + 澄清 '第 1~4 列，最左列不该空出来'。上一版误改成跨列 2-4 + 最左列空出，方向反了。
    【1】空格行贴左
    KEYMAP [2,3,3,SPACE] + [5,3,1,VOICE] → [1,3,3,SPACE] + [4,3,1,VOICE]
    空格 3 轴 31/49/67 → 13/31/49（全部落在 18mm 网格线上）；语音键列 5 → 列 4
    列 5（x=85）空出 → 主控上方不再压任何轴体（原 VOICE 正好压在主控上）
    连带：overlay 矩阵变换末行 RC(2,4) → RC(2,3)；空格 net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
